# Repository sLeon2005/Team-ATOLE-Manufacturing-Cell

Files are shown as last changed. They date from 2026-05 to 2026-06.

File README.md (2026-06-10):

# 🏭 Team ATOLE Manufacturing Cell
### PLC Coordination · Computer Vision · Collaborative Robotics · IIoT Monitoring · Cybersecurity

Manufacturing Cell

An Industry 4.0 manufacturing cell developed at Tecnológico de Monterrey that integrates industrial automation, machine vision, collaborative robotics, Industrial IoT, cybersecurity, custom electronics, and digital manufacturing.

The system simulates an automated pastry production facility capable of:

- Identifying products using industrial vision
- Dynamically selecting manufacturing recipes
- Coordinating two Siemens PLCs through an S7 network
- Performing automated material handling with a collaborative robot
- Monitoring energy consumption in real time via MQTT
- Enforcing operator authentication through RFID access control
- Palletizing finished products automatically

---

# 📖 Project Overview

The project combines machining, industrial automation, robotics, cybersecurity, and Industrial IoT into a single integrated manufacturing system.

The complete solution is divided into two major subsystems:

## ⚙️ Plant 1 – Machining & Industrial IoT Monitoring

A custom Aluminum 6061 workpiece was designed, manufactured, and monitored during machining operations.

A custom non-invasive monitoring system measures:

- RMS current
- Active power
- Energy consumption
- Operating cost
- Machine operating state

The collected data is transmitted through MQTT and visualized in real time using a Node-RED dashboard.

Plant 1 Overview

---

## 🏭 Plant 2 – Automated Manufacturing Cell

The manufacturing cell is controlled by two Siemens S7-1200 PLCs interconnected through industrial Ethernet communication.

The production process includes:

1. Product classification using Cognex Vision
2. Automatic recipe selection
3. Pneumatic processing stations
4. Conveyor synchronization
5. Collaborative robotic manipulation
6. Product assembly
7. Automated palletizing

Plant 2 Overview

---

# 🏗️ System Architecture

System Architecture

The architecture integrates:

- Siemens S7-1200 PLCs
- Siemens HMIs
- Cognex Vision Sensor
- UFACTORY xArm Lite 6
- ESP32 IoT Gateway
- MQTT Broker
- Node-RED Dashboard
- RFID Authentication System
- Pneumatic Stations
- Conveyor Network

---

# 🎛️ Industrial Automation

The automation layer was implemented using two Siemens S7-1200 PLCs communicating through an S7 network.

Key features include:

- Dual PLC architecture
- Bidirectional communication
- Dynamic recipe management
- Conveyor synchronization
- Pneumatic sequencing
- HMI operation and diagnostics

PLC System

---

# 👁️ Computer Vision

A Cognex industrial vision sensor acts as the cell’s quality gate.

Three reference objects are classified and mapped to production recipes:

| Object | Recipe |
|---|---|
| Turned Aluminum Part | Chocolate |
| Milled Aluminum Part | Strawberry |
| Metal Hook | Vanilla |

The detected classification is transmitted directly to the PLC network and automatically configures downstream process parameters.

Cognex Vision System

---

# 🤖 Collaborative Robotics

A UFACTORY xArm Lite 6 collaborative robot performs:

- Raw material loading
- Inter-conveyor transfers
- Product assembly
- Palletizing

The robot was programmed in Python using the xArm SDK and operates through a Finite State Machine (FSM) architecture capable of managing multiple workpieces simultaneously.

Collaborative Robot

---

# 📡 Industrial IoT Monitoring

A custom monitoring cabinet was developed around:

- ESP32
- SCT-013 Current Transformer
- ADS1115 16-bit ADC

The system continuously estimates:

- Current
- Power
- Energy
- Operating cost
- Machine utilization

without requiring direct electrical connection to the machine power circuit.

IoT Monitoring System

---

# 📊 MQTT & Node-RED Dashboard

Process variables are published through MQTT and visualized through a Node-RED dashboard.

Available metrics include:

- Live current consumption
- Active power
- Energy usage
- Estimated operating cost
- Machine operating state
- Historical trends

Node-RED Dashboard

---

# 🔐 RFID Cybersecurity

An RFID authentication system was integrated to restrict access to critical HMI functions.

Only authorized operators are allowed to access or modify manufacturing parameters.

RFID Access Control

---

# 🔧 Custom Hardware Development

Several custom-designed hardware components were developed specifically for this project.

## 💻 IoT Monitoring PCB

Custom PCB for:

- Signal conditioning
- Current measurement
- ESP32 integration
- MQTT communication

PCB

---

# 🔧 Custom Hardware Development

Several custom electronic and mechanical systems were designed and fabricated specifically for this project.

## 🔐 RFID Access Control PCB

A custom PCB based on the ATmega328P was designed to provide RFID-based operator authentication.

Main features:

- ATmega328P microcontroller
- RFID card reader
- Relay outputs for PLC interfacing
- User identification system
- HMI access control

The board allows the PLC to identify authorized operators and restrict access to critical manufacturing functions.

<p align="center">
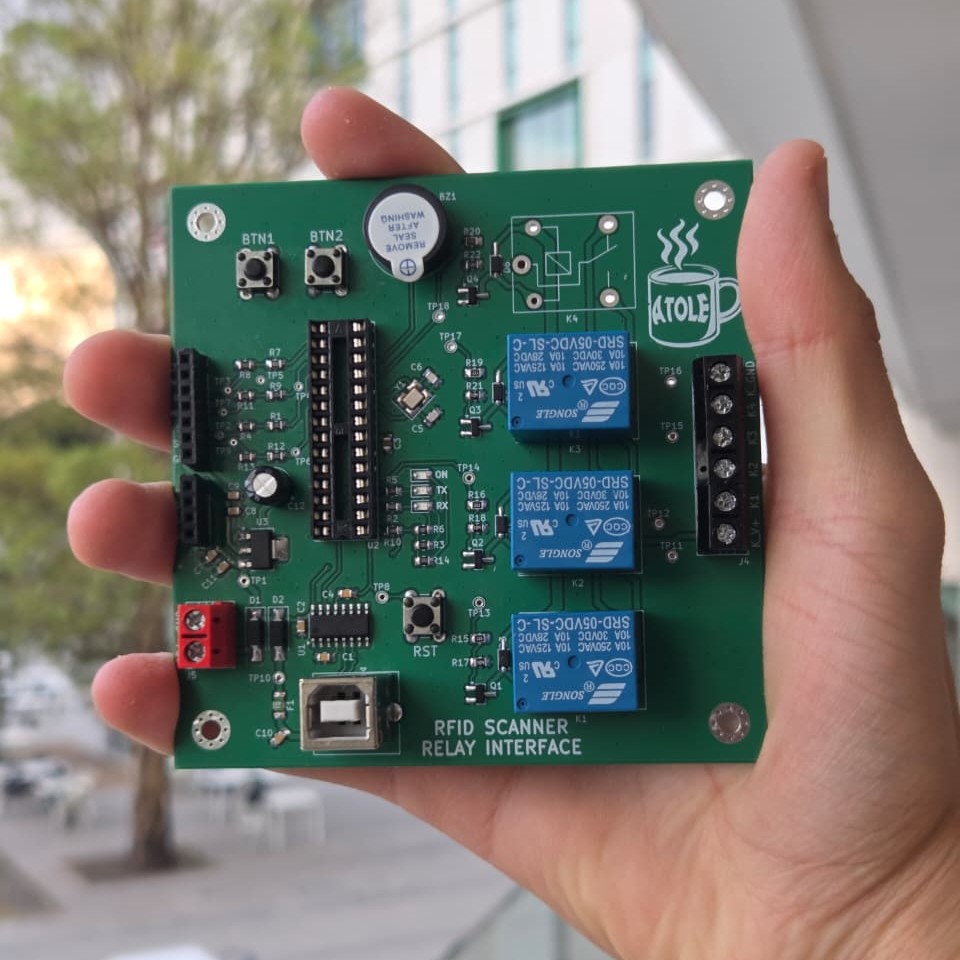
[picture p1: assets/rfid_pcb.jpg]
  
</p>

---

## 📡 IoT Energy Monitoring System

A dedicated Industrial IoT monitoring system was developed to analyze the electrical consumption of the ROMI T240 lathe.

Hardware used:

- ESP32
- SCT-013 Current Transformer
- ADS1115 16-bit ADC
- Signal conditioning circuit

The system was implemented on a prototyping board and publishes real-time data through MQTT for remote monitoring and energy analysis.

IoT Monitoring System

---

## 🦾 Custom End Effectors

Custom grippers were designed and manufactured to handle:

- Raw materials
- Semi-finished products
- Finished assemblies
- Palletizing operations

Custom Grippers

---

# 🛠️ Manufacturing

## ⚙️ Custom Machined Component

A stepped Aluminum 6061 workpiece was designed in Fusion 360 and manufactured on a ROMI T240 lathe.

The part serves both as a manufactured component and as a reference object for the vision classification system.

| CAD Model | Manufactured Part |
|---|---|
|  |  |

---

# 🧰 Software & Engineering Tools

- Siemens TIA Portal
- Siemens Plant Simulation
- Python
- xArm SDK
- MQTT
- Mosquitto
- Node-RED
- Arduino IDE
- Fusion 360
- KiCad

---

# 📈 Results

The final system successfully demonstrated:

✅ Industrial machine vision integration

✅ Dual-PLC communication architecture

✅ Collaborative robotic manipulation

✅ Automated product assembly

✅ Automated palletizing

✅ MQTT-based Industrial IoT monitoring

✅ Real-time energy analytics

✅ RFID-based cybersecurity controls

✅ Custom electronics and PCB development

✅ End-to-end Industry 4.0 integration

---

# 👥 Team

**Team ATOLE**

Tecnológico de Monterrey, Campus Querétaro

B.S. in Mechatronics Engineering

- Kintia Alexa Negrete Osuna
- Francisco Hernández Ramírez
- Sebastián León Medellín
- Yudy Camila Pérez Cervantes
- Jesús Zamora Castelazo

---

# 📄 License

This project is licensed under the MIT License.

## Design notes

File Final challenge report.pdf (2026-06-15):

## Design and Implementation of an Intelligent Pastry Manufacturing Cell Using

PLC Coordination, Computer Vision, Collaborative Robotics, IoT Monitoring,

## and Cybersecurity

Kintia Alexa Negrete Osuna (A01742928); Francisco Hernández Ramírez (A00573224); Sebastián León Medellín (A01412395); Yudy Camila Pérez Cervantes (A01707646); Jesús Zamora Castelazo (A01278023)

B.S. in Mechatronics Engineering Tecnológico de Monterrey
Querétaro, México

Abstract — This paper presents the design and physical implementation of an automated manufacturing cell integrating machining, industrial automation, computer vision, collaborative robotics, IoT monitoring, and cybersecurity. A stepped cylindrical workpiece was manufactured from Aluminum 6061 on a ROMI T240 lathe, serving as both a production component and a classification reference for the vision system. Electrical consumption during machining was monitored non-invasively using an SCT-013 current transformer, an ADS1115 16-bit ADC, and an ESP32 gateway, which continuously estimated RMS current, active three-phase power, accumulated energy consumption, operating cost, and discrete machine states (OFF, IDLE, CUTTING, FAULT). Data was transmitted via MQTT to a Node-RED dashboard, enabling remote real-time visualization and historical logging. Cell automation was integrated in two Siemens S7-1200 PLCs interconnected via an S7 network, exchanging 96 bytes of bidirectional process data. A Cognex industrial vision sensor classified three reference objects into product recipes, dynamically configuring flavor-dependent processing times through PLC multiplexor logic. Material handling, product assembly, and palletizing were performed by a UFACTORY xArm Lite 6 collaborative robot programmed in Python using a priority-based Finite State Machine capable of managing two concurrent workpieces. Performance was evaluated through machine utilization, OEE, cycle time, production rate, energy distribution per operating state, and estimated operating cost, yielding an OEE of 7% consistent with single-unit job production conditions.

Keywords — Automated Manufacturing Cell, Collaborative Robotics, Computer Vision, Programmable Logic Controller (PLC), Industrial Internet of Things (IIoT), Finite State Machine (FSM), Overall Equipment Effectiveness (OEE), Energy Monitoring

I. INTRODUCTION
A. State of the Art
The emergence of the fourth industrial revolution, broadly termed Industry 4.0, has introduced two converging forces reshaping modern manufacturing: an application-pull driven by demands for individualization, flexibility, and resource efficiency, and a technology-push characterized by increasing mechanization, digitalization, and networking of production systems (Lasi et al., 2014). At the core of this paradigm lies the Smart Factory concept, described as manufacturing environments “completely equipped with sensors, actors, and autonomous systems” (Lasi et al., 2014,
p. 240). Within these environments, cyber-physical systems merge physical processes with their digital representations
to | enable | real-time | monitoring, | control, | and
self-optimization.

Within this framework, collaborative robots have emerged as key enablers of flexible industrial automation. According to Villani et al. (2018), cobots provide a balance between robotic precision and human adaptability by integrating high accuracy, repeatability, and speed with the flexibility and cognitive capabilities of human workers. Their adoption aligns with Industry 4.0 objectives because collaborative automation seeks improvements in efficiency, productivity, and cost reduction while supporting greater flexibility and interoperability across production systems (Villani et al., 2018). Furthermore, the authors report increasing implementation of cobots in small and medium-sized enterprises due to the growing availability of affordable and user-friendly solutions, making them particularly relevant for didactic manufacturing environments.

Industrial machine vision systems constitute another foundational technology in automated manufacturing. Traditional visual inspection methods are often insufficient for modern production requirements because they rely on subjective human judgment and produce inconsistent results. As noted by Czimmermann et al. (2020), traditional inspection remains “a non-measurable process with variable and subjective outcomes” (para. 3), motivating the development of automated defect detection systems. Beyond quality control applications, industrial vision systems are increasingly employed for object identification and classification tasks that dynamically influence downstream manufacturing processes, enabling greater production flexibility and reducing manual intervention.

For real-time process monitoring, the MQTT protocol has established itself as one of the dominant communication standards in Industrial Internet of Things (IIoT) environments. Mishra and Kertesz (2020) attribute its widespread adoption to characteristics such as low overhead, simplicity, and ease of deployment, making it particularly suitable for constrained environments. The protocol was specifically designed to minimize bandwidth consumption and device resource requirements while maintaining reliable communication performance (Mishra & Kertesz, 2020). Their analysis further reports an average annual growth rate exceeding 32% in MQTT-related publications between 2004 and 2019, with applications spanning healthcare, agriculture, logistics, smart cities, and industrial manufacturing environments. Through its publish-subscribe architecture operating over TCP/IP, MQTT enables modular and scalable communication
infrastructures | that | are | particularly | suitable | for
heterogeneous IIoT systems requiring integration among multiple sensors, controllers, and monitoring platforms.
B. Challenge Description
In this work, a didactic manufacturing cell was automated and monitored to simulate an industrial pastry production facility. The cell is governed by two Siemens Simatic S7-1200 PLCs, each paired with a 7-inch Simatic HMI, and incorporates electropneumatic and electronic actuators, optoelectronic sensors, a UFACTORY xArm Lite 6 collaborative robot, and a Cognex industrial vision sensor. Complementary hardware including a pneumatic funnel, raw material supply grid, palletizing cage, and RFID access control module was designed and fabricated to achieve complete process integration. The cell operates across two sequential stages: a pneumatic processing stage and a machining simulation stage, each controlled independently while maintaining communication through an S7 network.

Concurrently, a physical aluminum workpiece was manufactured on a ROMI T240 manual lathe at the CIMA machining facility. This component, together with a milled aluminum piece and a metal hook, constitutes the set of reference objects used by the Cognex vision system to classify incoming product types at the beginning of each production cycle. Each classified object corresponds to a unique production recipe within the simulation: the lathe-machined component represents Chocolate, the milled component Strawberry, and the metal hook Vanilla.

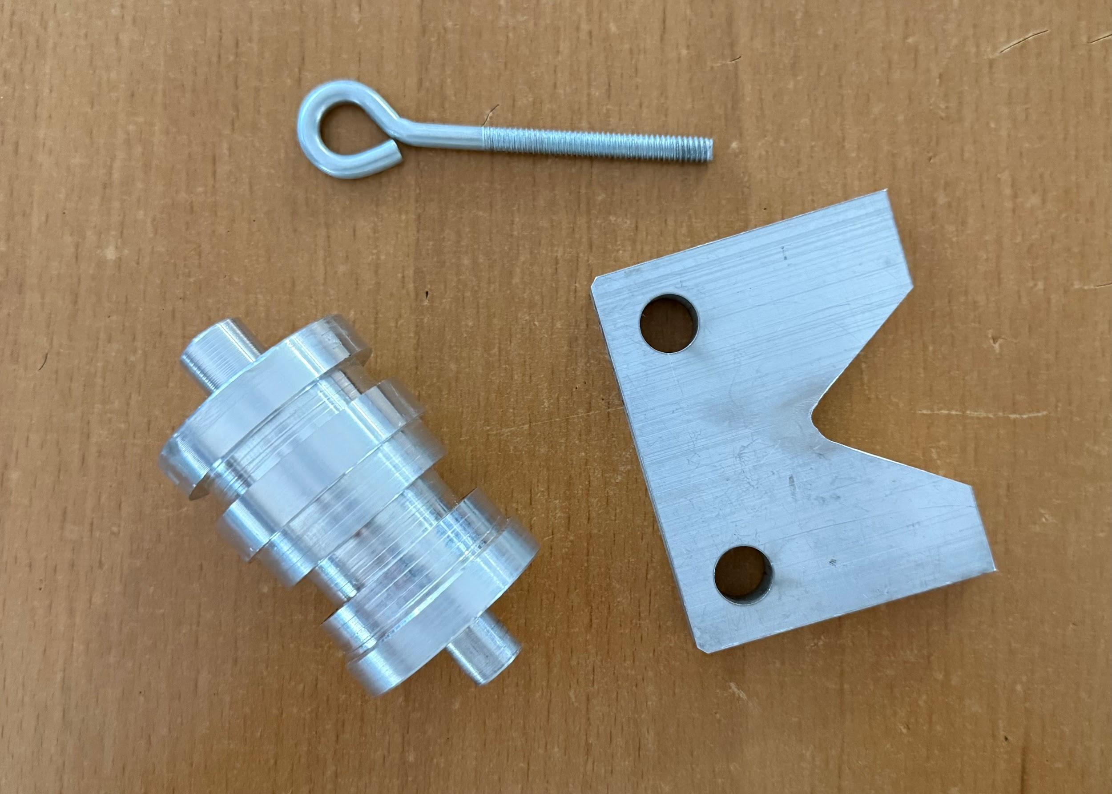
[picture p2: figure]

Figure 1. Pieces Used for the Classification System

Classification outputs are transmitted digitally to the PLCs, which dynamically adjust processing times, actuator
sequences, | and | cobot routines accordingly. The
collaborative robot performs raw material feeding, inter-conveyor transfer, product assembly, and palletizing tasks. Access to HMI interfaces is protected through RFID-based authentication connected to the PLC via relay logic, providing operator-level cybersecurity controls. Electrical consumption during machining is monitored in real time using an SCT-013 current transformer, an ADS1115 analog-to-digital converter, and an ESP32 gateway, with collected data transmitted through MQTT and visualized using a Node-RED dashboard accessible through the institutional network.
C. Team's Proposal
To address the manufacturing and automation challenge, the team proposed and physically implemented an integrated mechatronic system designed to simulate an automated cake manufacturing facility. The technical approach bridges physical machining operations with advanced industrial automation, utilizing a dual-PLC architecture, collaborative robotics, computer vision, and Industrial Internet of Things (IIoT) technologies. The specific solution is divided into three core technical pillars:
a. Plant 1: Custom Machining and Non-Invasive IoT Instrumentation
For the machining stage at CIMA, a cylindrical stepped workpiece was designed and manufactured from Aluminum 6061 using a ROMI T240 lathe. To monitor this process, a dedicated, non-invasive IoT instrumentation system was developed. This system utilizes an SCT-013 current transformer and an ESP32 microcontroller paired with an ADS1115 16-bit ADC to acquire high-resolution electrical data. An embedded algorithm processes these signals to estimate active three-phase power, accumulated energy consumption, and discrete machine states (OFF, IDLE, CUTTING, and FAULT). This data is transmitted in real-time via the lightweight MQTT protocol to a centralized Node-RED dashboard, enabling continuous remote monitoring and historical performance analysis.
b. Plant 2: Advanced Automation, Vision, and Collaborative Robotics
The automation of Cell 3105 required using two Siemens S7-1200 PLCs interconnected via an S7 communication network. A Cognex industrial vision sensor was integrated as a primary quality gate, classifying pieces into three distinct categories mapped to the simulation theme: the lathe-machined piece (Chocolate), the milled piece (Strawberry), and the metal hook (Vanilla). The PLC control logic employs dynamic array indexing to track the specific ID of each part as it moves through the line, allowing multiplexors to assign precise, flavor-dependent processing times for the drilling and mixing stations.

Furthermore, the UFACTORY xArm Lite 6 collaborative robot was programmed using Python 3 and the native xArm-Python-SDK, bypassing the limitations of rigid, linear Blockly programming. This approach implemented a pseudo-concurrent Finite State Machine (FSM) with priority-based task scheduling. This architecture allows the cobot to manage up to two products simultaneously through distinct phases: base pick-and-place, inter-conveyor transfer synchronization, topping assembly, and a structured two-level palletizing sequence that includes the automated placement of separator lids.

c. System Innovation and Cybersecurity Integration
To elevate the baseline project requirements, several innovative modules were integrated. An RFID-based access control system was implemented and wired to the PLC via relays to enforce cybersecurity protocols, ensuring only authorized users can access and modify the HMI interfaces. Additionally, custom end-effectors (grippers) were designed and fabricated for the cobot to reliably handle the specific geometries of the raw material grid, the pneumatic funnel, and the final assembled product. Finally, a unified monitoring architecture was developed, enabling real-time dashboard visualization of both Plant 1 and Plant 2 operations from any network location within the campus.

II. TECHNOLOGICAL DEVELOPMENT AND IMPLEMENTATION

A. Plant 1 - CIMA: Machining & IoT Instrumentation
a. Machining Process
The technical drawing of the proposed component is presented in Figure 2. The manufacturing challenge consisted of the development of a cylindrical stepped workpiece featuring multiple diameters and section lengths. The dimensional specifications were defined based on machining feasibility and system integration requirements. Additionally, coordination was carried out with the MCK team during the design phase to ensure geometric compatibility between the manufactured workpiece and the V-shaped support fixtures developed independently by that team. As a result, the selected diameters ensured proper alignment and handling of the component during subsequent stages. The component was manufactured using a conventional ROMI T240 lathe. The workpiece material consisted of Aluminum 6061, supplied as a cylindrical bar with an initial diameter of 2 in and a length of 7 in.

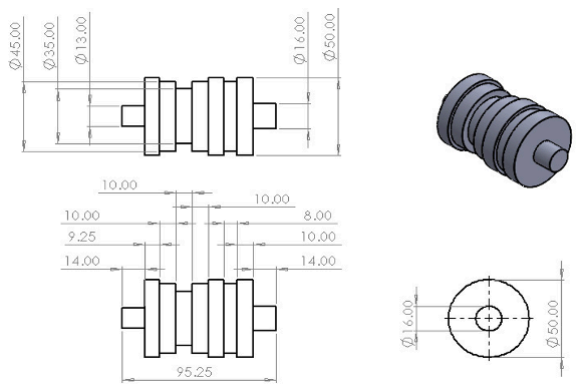
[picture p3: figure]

Figure 2. Technical Drawing of the Workpiece

Prior to machining, the raw material was sectioned using a horizontal band saw (Figure 3). An additional allowance of approximately 80 mm was intentionally left on the cut stock to prevent interference between the lathe guard and the final workpiece geometry, as well as to have enough work material in the chuck and prevent this from moving or going out due to the spindle velocity.

Figure 3. Raw Material Cutting Operation Using the JET Horizontal Band Saw

The workpiece was secured in the lathe chuck (Figure 4), and an initial facing operation was performed to establish a reference surface and obtain the required external diameter of 50 mm, as shown in Figure 5. Once the reference geometry had been established, a series of roughing passes was carried out to remove excess material and generate the stepped profile of the component.

Figure 4. Workpiece
Mounted in the ROMI
T240 Chuck

Figure 5. Initial Facing
Operation

The machining process consisted primarily of external turning operations to produce the diameters specified in the design. The final geometry incorporated a maximum diameter of Ø50 mm, intermediate diameters of Ø45 mm and Ø35 mm, and reduced end sections of Ø16 mm and Ø13 mm. Multiple geometric transitions were generated according to the dimensional requirements defined in the technical drawing. This process can be seen in Figure 6 and
7. During machining, the spindle operated at a nominal speed of 1080 RPM, providing stable cutting conditions and consistent material removal performance, as shown in Figure 8.

Figure 6. Rough Turning
Operation for Material
Removal

Figure 7. Machining of
Stepped Diameters and
Profile Features

Figure 8. Spindle Speed Configuration Used During Machining (1080 RPM)

Throughout the machining process, dimensional verification was continuously performed using a Vernier caliper. Critical diameters and lengths were periodically measured following each relevant operation to ensure compliance with the specified dimensions and to minimize dimensional deviations. The machined component achieved the specified overall length of 95.25 mm and incorporated multiple stepped features with widths ranging from 8 mm to 14 mm.

The completed component is presented in Figures 9 and 10, which show the Fusion 360 model and the physical workpiece manufactured on the ROMI T240 lathe,
respectively. | The | dimensional | validation of the
manufactured component ensures that the part is suitable for subsequent integration into the monitoring and data acquisition stage of the project. Since the geometry of the
workpiece | directly | influences | cutting | conditions,
maintaining geometric conformity with the digital model is essential for obtaining reliable process signals.

In this context, the verified agreement between the CAD model and the physical component guarantees that the machining conditions used during production correspond to the expected process parameters. This is particularly relevant for the analysis of current consumption and energy usage, as stable and repeatable cutting conditions are required to ensure that the electrical signals acquired from the ESP32-based IoT system accurately reflect the machining behavior.

Therefore, the validated manufacturing process supports the integrity of the collected electrical consumption data, enabling its use for further analysis of machining efficiency and energy performance within the production system.

Figure 9. Fusion 360
Model of the Finished
Component

Figure 10. Manufactured
Component
b. IoT Monitoring System
The electrical consumption of the ROMI T240 lathe was monitored using a non-invasive current measurement system based on an SCT-013 current sensor and an ESP32 IoT gateway.
i. Three-Phase Monitoring Enclosure
To enable safe and reliable current measurements, a dedicated monitoring enclosure was designed and assembled (Figure 11). The enclosure incorporated a three-phase industrial connector, including the three power lines and an earth conductor. All internal wiring was implemented using 12 AWG conductors to ensure adequate current-carrying capacity and compliance with electrical safety requirements. Ferrules were crimped onto all wire terminations to facilitate secure connections within the enclosure.

Figure 11. Inside of the
Three-Phase Monitoring
Enclosure

Figure 12. Installation of the Monitoring Cabinet
Between the Power Supply
and the ROMI T240 Lathe

The monitoring cabinet was installed between the electrical supply and the ROMI T240 lathe. This arrangement provided access to the individual phase conductors while maintaining normal machine operation. Since the SCT-013 is a non-invasive current sensor, it was clamped around one of the phase conductors without requiring any direct electrical connection to the power circuit. Consequently, the current flowing through the selected phase of the lathe could be measured safely and continuously during machining operations.

ii. Signal Conditioning and Data Acquisition Circuit
The SCT-013 current transformer produces a low-amplitude alternating voltage proportional to the current flowing through the monitored phase conductor (PowerUC Electronics, n.d.). Since the output signal contains both positive and negative half-cycles, direct acquisition by the analog-to-digital converter is not possible because the ADC operates only within the positive supply range.

Figure 13. Electrical Schematic of the Signal Conditioning and Data Acquisition Circuit

To address this limitation, a signal conditioning stage was designed and implemented (Figure 13). The first stage consists of a voltage divider formed by two 10 kΩ resistors connected between the 3.3 V supply and ground. This arrangement generates a reference voltage of approximately 1.65 V, corresponding to half of the supply voltage.

The reference voltage is buffered using an operational amplifier configured as a voltage follower. Capacitors were incorporated around the divider network to attenuate noise and improve voltage stability.

The SCT-013 sensor output is connected across a 150 Ω burden resistor. The burden resistor converts the secondary current produced by the current transformer into a measurable voltage signal according to Ohm’s law. The resulting AC voltage is superimposed on the 1.65 V virtual ground, effectively shifting the waveform into the operating range of the acquisition system.

A second operational amplifier, also configured as a voltage follower, isolates the sensor and conditioning stages from the ADC input. This buffering stage improves signal integrity, and ensures that the waveform delivered to the converter accurately represents the current measured by the SCT-013 sensor.

The conditioned signal is acquired by an ADS1115 16-bit analog-to-digital converter connected to the ESP32 through the I²C communication interface. Compared to the ESP32 internal ADC, the ADS1115 provides higher resolution and improved measurement accuracy, allowing more reliable current estimation (Admin, 2026).

iii. Current Measurement Algorithm
The ESP32 continuously acquires samples from the ADS1115 to estimate the electrical current consumed by the ROMI T240 lathe. The calculations were performed using the formulas presented by Storr and Storr (2026) in the RMS Voltage Tutorial.

For each measurement cycle, 500 samples are collected from the conditioned waveform. During the acquisition window, the algorithm determines the maximum and minimum voltage values measured by the ADC:
V

pp = V

max − V
min

where V is the peak-to-peak voltage of the sampled
pp
waveform.

Assuming a sinusoidal waveform, the RMS voltage is estimated from the peak-to-peak value using:
| V RMS = 0. 3536 × V pp

The RMS voltage is then converted into current using the burden resistor (150 Ω), as follows:
| I RMS = V RMS 150 Ω

Finally, the primary current flowing through the monitored conductor is obtained by applying the SCT-013 current transformation ratio:
| I = I RMS × 2000

This method allows the electrical current consumed by the lathe to be estimated from the sampled waveform without requiring direct electrical contact with the power circuit.

iv. Power and Energy Estimation
After calculating the RMS current, the ESP32 estimates the active three-phase power using the measured current, the nominal line voltage, and an assumed power factor. Since direct power-factor measurements were not available, a power factor of 0.85 was adopted. This value is representative of typical industrial machine-tool drive systems and falls within the range commonly reported for such equipment under normal loading conditions (Schneider Electric, n.d.; Power, 2026). The active three-phase power is then calculated as follows:
| P = 3 × V × I × PF
where:
- V = 220 V (line voltage)
- I is tℎe measured current
- PF = 0. 85 (assumed power factor)

Electrical energy consumption is calculated by integrating power over time:
| E = i=1 n ∑ P i × ∆t i

The accumulated energy value is expressed in kilowatt-hours (kWh) and is continuously updated during machine operation.

v. Data Transmission and Visualization
After each acquisition cycle, the ESP32 processed the sampled data and generated a set of operational and energy-related indicators representative of the electrical behavior of the ROMI T240 lathe. These variables were converted into string format and transmitted using the Message Queuing Telemetry Transport (MQTT) protocol.

MQTT was selected due to its lightweight architecture, low bandwidth requirements, and suitability for Industrial Internet of Things (IIoT) applications (Simson M, 2025). Communication was implemented using a Mosquitto MQTT broker hosted on a dedicated workstation connected to the university network (Yudy’s computer). This workstation served as the central communication hub between the ESP32 IoT gateway and the monitoring platform. Operating under a publish-subscribe architecture, the broker received data published by the ESP32 and distributed the information to all subscribed clients.

The ESP32 was connected to the university wireless network and periodically published process variables to dedicated MQTT topics. A separate topic was assigned to each monitored variable, allowing modular data management and simplified dashboard integration. The transmitted variables included:

- Current (A)
- Active power consumption (kW)
- Accumulated energy consumption (kWh)
- Estimated operating cost (MXN)
- Machine operating state (OFF, IDLE, CUTTING, or FAULT)
- Accumulated OFF time (s)
- Accumulated IDLE time (s)
- Accumulated CUTTING time (s)
- Accumulated FAULT time (s)

For visualization purposes, a Node-RED dashboard was developed and configured as an MQTT subscriber. The dashboard continuously monitored the corresponding topics and updated the graphical interface whenever new measurements became available. The interface incorporated numerical indicators, trend charts, energy consumption metrics, and machine status displays, providing operators with real-time insight into machine utilization and electrical performance.

The integration of MQTT and Node-RED enabled continuous remote monitoring of the machining process while maintaining a low-cost and scalable IIoT architecture (Figure 14). By combining current measurements, power and energy calculations, and machine-state information, the dashboard provided a comprehensive overview of equipment utilization, operational efficiency, and energy consumption throughout the manufacturing process.

Figure 14. IoT Architecture for Real-Time Monitoring of the ROMI T240 Lathe

B. Plant 2 - Cell 3105: Automation & Robotics
a. Computer Vision Criterion (Quality Gate)
The Cognex industrial vision sensor was implemented as the primary quality gate of the manufacturing cell. Its function is to identify the type of part entering the process and communicate the classification result directly to the Siemens S7-1200 PLC through discrete digital signals.

Before each production cycle, the operator places one of three reference objects inside the Cognex inspection area: the lathe manufactured aluminum part, the milled aluminum part, or a metal hook. These objects were selected to represent the three product recipes of the pastry manufacturing simulation. The lathe part corresponds to the Chocolate recipe, the milled part corresponds to the Strawberry recipe, and the metal hook corresponds to the Vanilla recipe.

The Cognex sensor was electrically integrated into the control architecture of the Manufacturing PLC (front left) using a shared 24 VDC industrial power supply. Both the PLC and Cognex were connected to the same voltage reference and common ground (0 VDC / GND) through the control panel terminal distribution. Maintaining a common electrical reference between both devices was essential to guarantee stable digital communication, reduce electrical noise susceptibility, and avoid undefined voltage states during signal transitions (WDF,2025).

Communication between the PLC and the vision system was implemented using one digital output and three digital inputs of the PLC, as well as one digital input and three digital outputs of the Cognex sensor. PLC output Q8.7, identified in the control program as Cognex_IN0 was wired to the trigger input of the Cognex sensor, whereas the digital outputs generated by the camera were connected directly to PLC inputs I9.0, I9.1, and I9.2, corresponding to Cognex_OUT0, Cognex_OUT1, and Cognex_OUT2 respectively in the ladder program of the PLC. These outputs transmit the inspection result detected by the vision algorithm.

During operation, the PLC sequencing logic activates the trigger signal through output Q8.7 whenever the HMI designed button is pressed. Immediately after, a timer pulse (TP) instruction is activated to maintain the trigger active for one second, ensuring efficient acquisition time for stable image capture and processing. Once the image is processed internally by the Cognex sensor, the corresponding digital output is activated and sent to the PLC.

The implemented architecture was configured to support three independent classifications. Therefore, the PLC monitors the status of the three Cognex outputs (whenever the signal of the trigger is activated with the HMI button) and stores the detected result inside the Communication Data Block variable: Cognex_Code and its own local tag CognexID. The classification logic is defined as follows:

I9.0 (Cognex_OUT0) → Classification 0 (Chocolate) → Cognex_Code = CognexID=0

I9.1 (Cognex_OUT1) → Classification 1 (Vanilla) → Cognex_Code = CognexID = 1 I9.2 (Cognex_OUT2) → Classification 2 (Strawberry) → Cognex_Code = CognexID = 2

The resulting code is later used by the PLC state machine to determine the corresponding actuation or sorting sequence within the manufacturing cell.

Additionally, a fault-handling condition was incorporated into the inspection logic to improve process reliability. If none of the Cognex outputs becomes active during the acquisition window, the PLC automatically assigns the value -1 to the variable Cognex_Code. This condition represents an invalid or inconclusive inspection result and may be caused by incorrect part positioning, inadequate illumination, motion blur, or failure to detect a valid object within the camera region of interest. Under this condition, the PLC does not execute any manipulation or classification movement, preventing incorrect operations caused by unreliable image data.

Originally, the system design considered the implementation of an additional “task completed” signal from the Cognex sensor to indicate the end of image processing. However, due to a third classification proposed by the team since the beginning of the planification, the available communication resource, originally assigned to the vision sensor output Cognex_OUT2 was reassigned as an additional classification output.

Once the classification is completed, the detected ID is transmitted to the Pneumatic PLC through the PUT and GET communication network. The receiving PLC stores the value in the variable CognexID, which becomes the main decision parameter for the subsequent manufacturing operations. Indicator lights are activated to provide visual feedback of the detected product type, while the classification code is simultaneously used to select the appropriate process parameters.

A multiplexor (MUX) instruction was implemented to automatically assign different punching times according to the detected product type. Therefore, the vision system not only performs product identification but also dynamically configures the manufacturing recipe, enabling flexible production without manual intervention.

b. Control Logic and Sequencing
Recalling that a dual-PLC architecture was used for this project, a crucial step regarding the communication was to establish an S7 network that allowed the exchange of information between CPUs. This communication method involves the creation of two identical (in content) data blocks (one on each one of the PLC’s) where information will be read and written in real time by using the blocks PUT (write to the other data block) and GET (read from the other data block) from the TIA portal interface.

To implement this protocol, it is important to highlight that data blocks are arranged as a list of tags, each one of them having its own associated memory direction where the information should be written or read from. Recalling this, to reach the integration level of this project, a continuous bidirectional communication was established, where a total of 96 bytes of information are exchanged between the PLCs.

The reason behind the necessity to communicate such a great amount of information, is because two strings are shared between devices, representing 74 bytes by themselves, while the rest can be attributed to sensor states, classifications, execution codes, variables, etc.

The manufacturing process begins with the Machining PLC (front left) by setting the corresponding tags to 0, 1 or 2 depending on the classification received from the Cognex vision sensor (if the classification is invalid, the code is written in a certain way that the value -1 is never used, so it waits until receiving a valid ID). As the cobot is wired to the Pneumatic PLC (front right), the S7 network and its corresponding data blocks are used to share the classification between both CPUs.
Once the Pneumatic PLC receives the classification, it sets a byte and sends the first three bits to the cobot through its wired inputs, each different combination corresponding to the piece that is next to be manufactured. The Byte is set as follows:

Classification 0 (Chocolate Flavor) → Decimal number assigned = 1 → Byte = 00000001 Classification 1 (Vanilla Flavor) → Decimal number assigned = 2 → Byte = 00000010 Classification 2 (Strawberry Flavor) → Decimal number assigned = 3 → Byte = 00000011

Through its programming and mapped positions, the cobot knows where to move over the grid to get the corresponding raw material that will be the input for the immediate process. Right after, the cobot grabs the piece and moves it to the cell input at the pneumatic funnel.

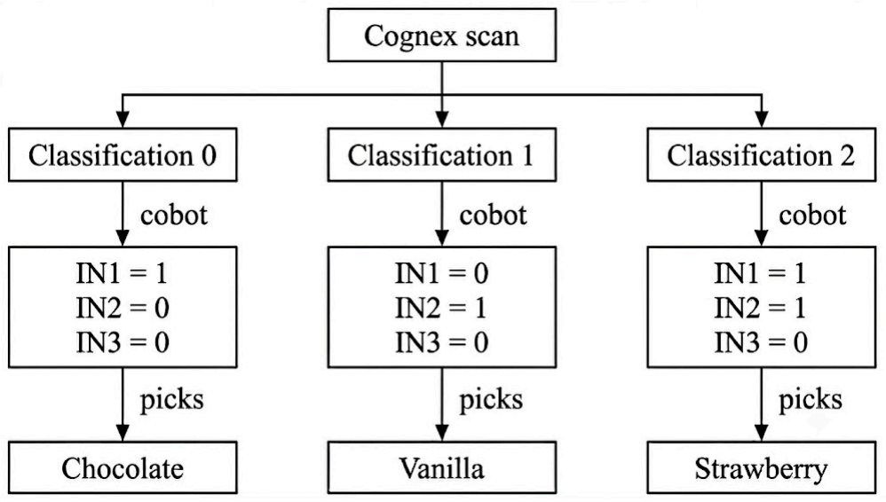
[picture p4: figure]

Figure 15. Flow Chart for Input Detection

Once a piece is located at the starting position of the pneumatic process and the optoelectronic sensor is covered, with the use of a normally closed contact, a timer ON (200ms) is used to delay the activation of a timer OFF that keeps the starting piston extended (400ms) pushing the raw material into the turntable, which is activated by the extension of the piston and latched until the button that is below is pressed, which leaves the piece under the vertical piston.

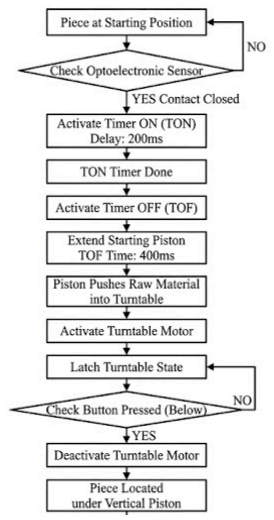
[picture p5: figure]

Figure 16. Flow Chart for Input Raw Material

Depending on the current piece that is being manufactured (chocolate, vanilla or strawberry) a multiplexor is used to set the corresponding number of presses the piston must perform; once it is done, the turntable is again activated and leaves the piece in position to be pushed to the first conveyor. When the piece pushes the conveyor button, the originally extended piston is contracted (with the use of a Pulse timer we ensure enough time is given for the piece to be pulled), placing the material on the conveyor and activating it.

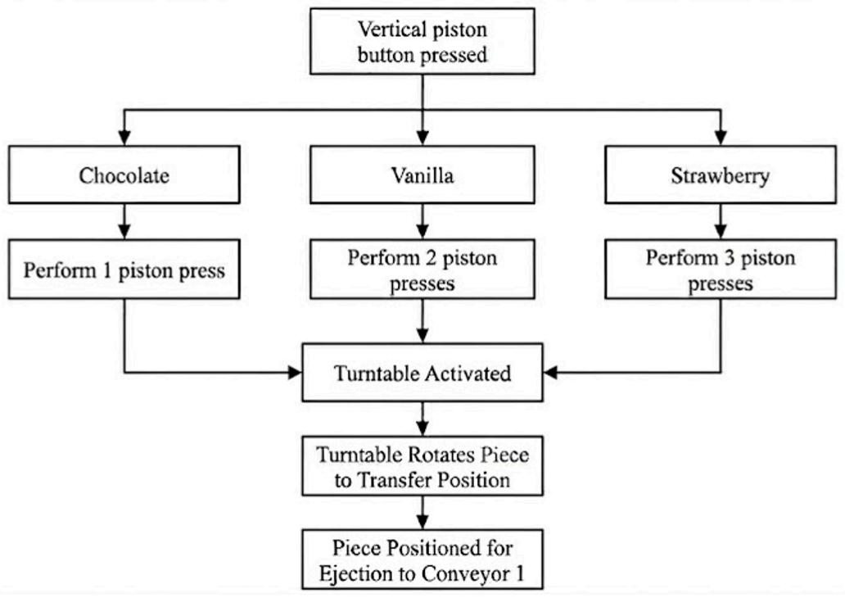
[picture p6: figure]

Figure 17. Flow Chart for Vertical Piston Operation

Since this point, all the manufacturing tasks, except for the cobot instructions are performed by the Manufacturing PLC, hence the state of the sensor placed at the end of the first conveyor and connected to the Pneumatic PLC has to be sent via the S7 network. Following this, when the sensor detects the piece, the change produced at the contact is received by the Manufacturing PLC which activates the second conveyor and latches it. At this point the piece is transferred between both conveyor belts and then passes through the first optoelectronic sensor of the second conveyor, whose state is sent back to the Pneumatic PLC to indicate the first conveyor has already completed its task and must be turned off.

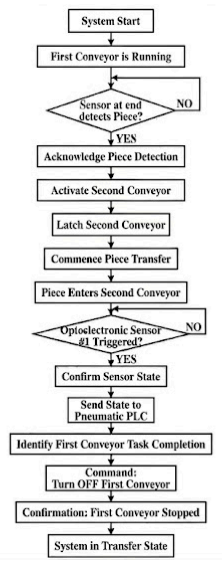
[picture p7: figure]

Figure 18. Flow Chart for Transfer Between Stations

When the piece reaches the last optoelectronic sensor of the second conveyor, two Pulse timers are chain triggered, one (3.5s) to keep the conveyor on for enough time to get the piece to the pusher position and the second one (3.3s) to delay the activation of the pusher that transfers the piece to the third conveyor. At the same time, the activation of the pusher is used to turn on the third conveyor which runs until its own optoelectronic sensor detects a piece, stopping it for the drilling operation.

Figure 19. Flow Chart for Conveyor 2 to Conveyor 3 Transferring

An important feature of the programming is that for the machining part of the cell, data blocks with arrays going from 0 to 99 were created to store the type of the pieces detected with the vision sensor in the same order they were scanned, so we can keep track of which type of piece is been and will be manufactured at every time and the processing times are not mixed up.

This was achieved by creating inside the data blocks, two indexes, one that is used to keep track of the upcoming empty position (by augmenting in one whenever a position is used) of the array and store there the corresponding ID every time the vision sensor makes a classification, and the other one used to keep track of the piece that is currently being manufactured and set the corresponding times for each operation of the cell. It is also important to highlight that a data block with these arrays and indexes was created for each operation (drilling and mixing) and for the cobot to also keep track of the piece currently on the line.

With this information, the moment that the piece stops under the drill, a Pulse timer (whose preset time is selected by a multiplexor) is activated for the time corresponding to the piece type that is on the line; once the timer reaches its preset value, another Pulse timer is triggered for 2 seconds to move the conveyor again and transfer the piece to the mixing station conveyor (conveyor 4), where, following the same logic, the process is repeated; the conveyor carrying the piece stops when the corresponding optoelectronic sensor changes its state; with the ID stored at the array and the use of a multiplexor, the operation time is set on a Pulse timer, and once the operation is done, another Pulse timer activates the conveyor to move the piece to where the second pusher is located. Additionally the timer’s output bit is used at the input of a timer ON that delays the activation of the pusher until the piece reaches the target position.

Figure 20. Flow Chart for Drilling Operation

When the pusher is activated, conveyor 5 is turned on to move the manufactured piece towards its edge, where an optoelectronic sensor stops it, sets a byte corresponding to decimal 4 and sends the first three bits to the cobot, indicating the piece has to be transported from conveyor 5 to conveyor 6 for the last part of the manufacturing process. The cobot grabs the piece from conveyor 5, releases it at the beginning of conveyor 6 and then retracts to a safe position, when this routine is completed it sends three bits through its digital outputs to the PLC corresponding to a decimal 1, with the use of a comparator, a timer ON is triggered and after 300 milliseconds conveyor 6 is activated to move the piece towards the press machine.

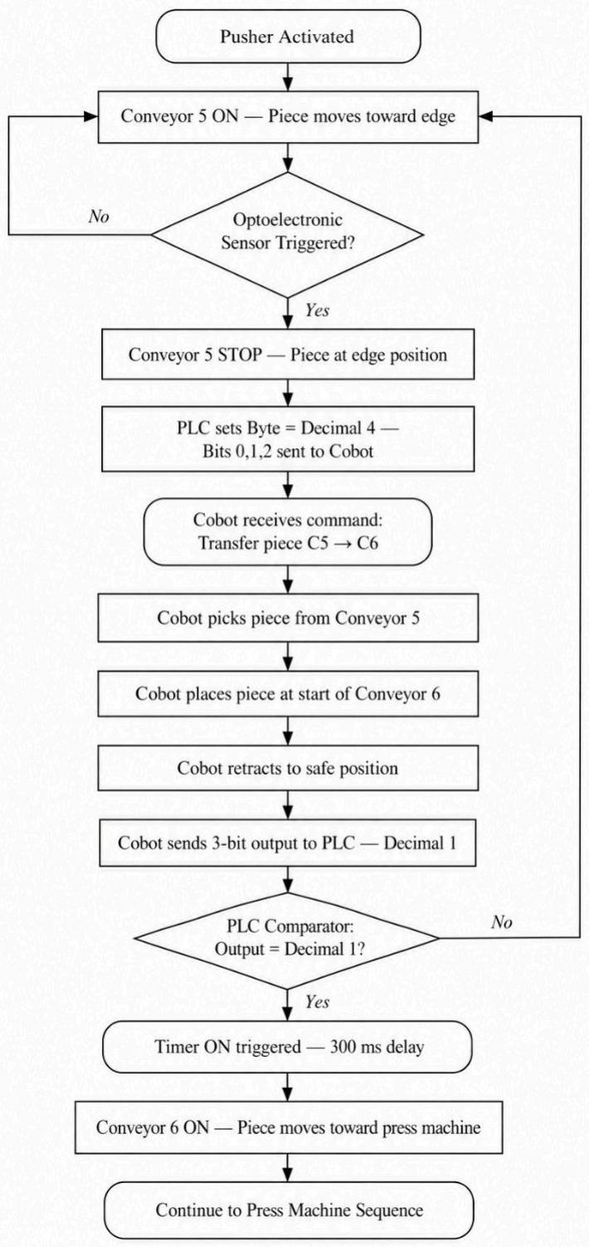
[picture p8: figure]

Figure 21. Flow Chart for Conveyor 5 to Conveyor 6 Transferring

With the use of a Pulse timer (800 ms) and a timer ON (300 ms), the piece is placed right below the press machine, and by using conveyor 6 end’s optoelectronic sensor, the press machine is actuated down. After a period of 1.5 seconds set at a timer ON, the press machine is contracted and the piece is taken again to the start of the conveyor.

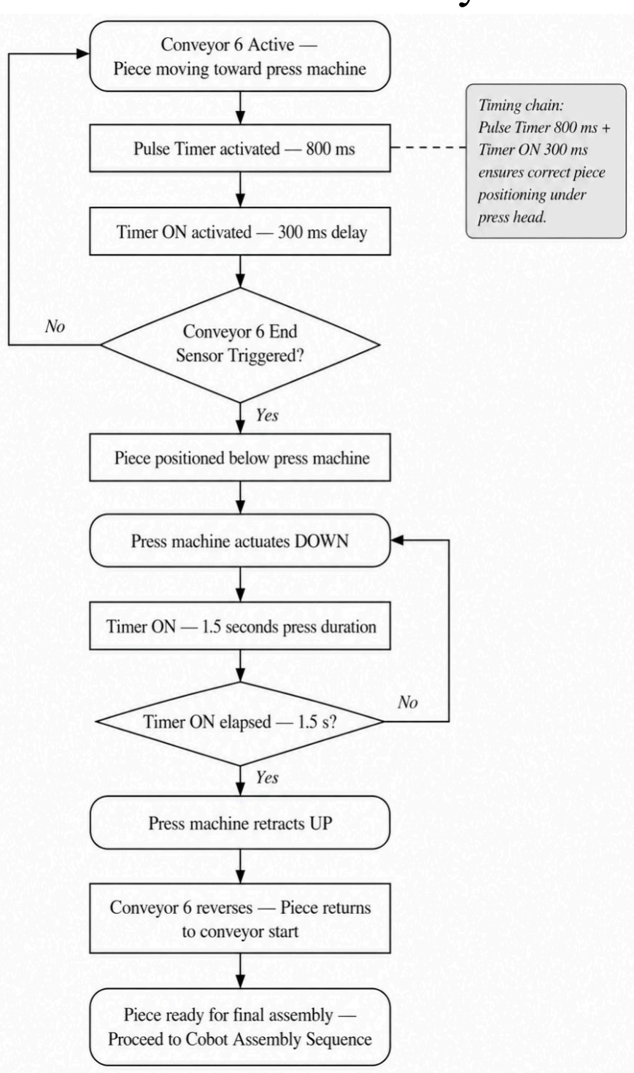
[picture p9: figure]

Figure 22. Flow Chart for Conveyor 6 and Press Machine Operation

By using the same logic as before, with a data block containing an array and a couple indexes, a multiplexor is used to set a byte corresponding to a decimal 5, 6 or 7 depending on the piece that is exiting the cell, then, the first three bits are sent through the digital inputs of the cobot so it grabs the matching complementary piece, assembles the final product and begins the palletizing sequence.

Figure 23. Flow Chart for Final Assembly and Palletizing

c. Collaborative Robot Control Logic and Integration
i. System Architecture and Hardware Configuration
The UFACTORY xArm Lite 6 collaborative robot was integrated into Cell 3105 as the primary material handling and palletizing subsystem. Physical communication with the cell’s central Programmable Logic Controller (PLC) is established through a bidirectional digital I/O interface comprising four configurable inputs (CI0–CI3) and three configurable outputs (CO1–CO3). The hardware operates under active-low logic for inputs and active-high logic for outputs.
Signal | Designation | PLC Address | Function | Active State
Input | CI0 | Q8.0 | - | Normally HIGH
Input | CI1 | Q8.1 | Flavor selection bit 0 | Active LOW
Input | CI2 | Q8.2 | Flavor selection bit 1 | Active LOW
Input | CI3 | Q9.4 | Conveyor 5 end | Active LOW
Output | CO1 | I0.1 | Response bit 0 | Active HIGH
Output | CO2 | I0.2 | Response bit 1 | Active HIGH
Output | CO3 | I0.3 | Response bit 2 | Active HIGH

Table 1. Digital I/O Configuration

ii. Control Interface Rationale
While the native UFACTORY Blockly interface is suitable for basic, linear pick-and-place routines, it is suboptimal for complex industrial logic. Blockly operates on a rigid, single-threaded execution model that forces the robot into a synchronous "wait-and-act" paradigm. This limitation renders it incapable of managing concurrent workflows, tracking real-time production data, or handling multi-device asynchronous communication.

To overcome these limitations, the control logic was
engineered | using | Python | 3 | and | the | native
xArm-Python-SDK (v1.11.0). This implementation replaces traditional linear sequencing with a pseudo-concurrent pipeline architecture. By leveraging the Python runtime environment, the system executes non-blocking I/O polling, manages up to two active work-in-progress (WIP) units simultaneously, enforces independent safety timeouts, and facilitates advanced error logging.

Furthermore, critical safety telemetry is processed via independent background threads managed through
asynchronous | hardware | callbacks
(register_error_warn_changed_callback | and
register_state_changed_callback). | This | multi-threaded
configuration isolates fault monitoring from the primary control loop, ensuring immediate actuator shutdown during collision events or emergency stops without introducing latency in the main execution cycle.

iii. Operational Sequence
The control software manages the production line via a non-blocking Finite State Machine (FSM). Rather than processing a single unit sequentially from start to finish, the FSM allows up to two units to co-exist in different stages of the production line. The robot executes a single evaluation per iteration, prioritizing tasks dynamically to maximize throughput. Each waiting state incorporates a 120-second timeout to prevent terminal blocking under fault conditions.

Phase 1 — Flavor Detection
The product flavor is identified by continuously polling the digital inputs of the cobot. A 50 ms software sampling window ensures signal stability and filters out electrical noise before the classification is committed.
Flavor | CI2 | CI1 | GPIO Pattern | Y Coordinate (mm)
Chocolate | HIGH | LOW | [1,0,1,1,1,1,1,1] | −200.0
Vanilla | LOW | HIGH | [1,1,0,1,1,1,1,1] | −250.0
Strawberry | LOW | LOW | [1,0,0,1,1,1,1,1] | −300.0

Table 2. Flavor Encoding

The X coordinate for tray access is shared across all flavors: X_1ST = [5.0, 55.0, 105.0] mm for base pieces and X_2ND = [155.0, 205.0, 255.0] mm for lids, indexed by a per-flavor counter that cycles through positions 0–2.

Phase 2 — Base Pick-and-Place
Upon flavor identification, the robot executes a pick-and-place operation transferring the cake base from the first section of the supply tray to the funnel that marks the start of the production line. The trajectory consists of seven precise waypoints.
# | Waypoint | X | Y | Z | Rx | Ry | Rz

1 | Home | 200.0 | -100. 0 | 200.0 | 180.0 | 0.0 | -45.0
2 | Approach | target _x | target _y | 50.0 | 180.0 | 0.0 | -45.0
3 | Pick | target _x | target _y | 10.0 | 180.0 | 0.0 | -45.0
4 | Retract | target _x | target _y | 50.0 | 180.0 | 0.0 | -45.0
5 | Transit | 200.0 | 110.0 | 200.0 | 180.0 | 0.0 | -45.0
6 | Place approach | -37.8 | 243.4 | 193.3 | 180.0 | 0.0 | -45.0
7 | Place | -37.8 | 243.4 | 144.7 | 180.0 | 0.0 | -45.0

Table 3. Phase 2 Trajectory

Waypoint 1 utilizes an asynchronous call (wait=False) to initiate physical hardware acceleration immediately while subsequent target positions are evaluated in the Python runtime.

Phase 3 — Cell Transfer Synchronization
Following base placement on the cell, the robot releases the “cake base” and becomes available to execute other pipeline tasks. Concurrently, the FSM monitors the unit by polling input CI3 at 50 ms intervals. CI3 transitioning to LOW signals that the part has reached the end-of-travel sensor on Conveyor 5 and is mechanically ready for inter-conveyor transfer.

Phase 4 — Inter-Conveyor Transfer
Upon CI3 activation, the cake base is transferred to Conveyor 6. The end-effector rotates from Rz = −45° (tray access orientation) to Rz = 90° (conveyor handling orientation) to align the cake base correctly for lid placement and prevent collisions. Upon placement at Conveyor 6 (252.1, −2.6, 56.4 mm), a 500 ms binary pulse is transmitted to the PLC via CO1–CO3 to signal that a base has been placed on the conveyor and to initiate the corresponding process.

Phase 5 — PLC Assembly-Ready Acknowledgment
The robot enters a non-blocking monitoring state, polling CI1–CI3 for a flavor-specific acknowledgment handshake from the PLC. This handshake confirms that upstream processes are complete and the base is ready for final assembly.
Flavor | CI3 | CI2 | CI1 | GPIO Pattern
Chocolate | LOW | HIGH | LOW | [1,0,1,0,1,1,1,1]
Vanilla | LOW | LOW | HIGH | [1,1,0,0,1,1,1,1]
Strawberry | LOW | LOW | LOW | [1,0,0,0,1,1,1,1]

Table 4. PLC Acknowledgment Encoding

Phase 6 — Topping Pick-and-Place
Once the PLC acknowledgment is validated, the topping corresponding to the active flavor is retrieved from the second section of the supply tray (X_2ND coordinates) and deposited on top of the cake base positioned at Conveyor 6 (Z = 71.4 mm). Upon successful placement, the specific per-flavor counter is incremented by one.

Phase 7 — Palletizing
The fully assembled product moves from Conveyor 6 onto a pallet, where it is stacked in a 2×2 grid across two vertical levels.m To determine exactly where each product goes, the system uses a simple repeating sequence based on the total number of pallets processed:
grid_idx = global_pallet_count (mod 4)

The height (Z-axis) automatically adjusts depending on the layer, shifting from Layer 1 (Z = 10 mm) to Layer 2 (Z = 55 mm). Once the product is placed, the system sends a 700 ms binary signal to log the specific product flavor into the PLC registry.

Flavor | CO3 | CO2 | CO1 | Binary
Chocolate | 0 | 1 | 0 | 010
Vanilla | 0 | 1 | 1 | 011
Strawberry | 1 | 0 | 0 | 100

Table 5. Palletizing Completion Codes

Phase 8 — Separator Lid Placement
To protect the products during storage, separator lids are inserted at two specific intervals. The system places an intermediate separator after every 4 units (picking at Z = 80 mm and placing at Z = 40 mm), and a final top lid after every 8 units (picking at Z = 33 mm and placing at Z = 82 mm). Once the top lid is in place, the global_pallet_count resets to zero to start the next palletizing cycle.

iv. Dynamic Task Scheduling and Pipeline Management The system uses a priority-based scheduling method that allows the robotic cell to handle up to two products at the same time without needing complex multi-threading. Instead of processing one product from start to finish before starting the next, each product is tracked as an independent task within a Finite State Machine (FSM). Every task moves through its own series of steps, including base placement, conveyor transfer, PLC synchronization, lid assembly, and palletizing.

To prevent traffic jams on the line and maximize efficiency, the scheduler checks all active tasks during every turn of the main control loop. Only one physical robot action happens per cycle, but the system constantly monitors every product using fast, non-blocking digital (GPIO) checks and timeout tracking. This allows multiple products to exist at different stages of the line while sharing the same robotic arm.
A Work-In-Process (WIP) limit of two active products is enforced through the parameter:

MAX_CONCURRENT = 2

This constraint was selected to prevent excessive queue buildup. As a result, one product may be waiting for conveyor transport or PLC acknowledgment while another product is already entering production. For example, if Task A is in State 3 (ready for lid assembly) while Task B is in State 4 (ready for palletizing), the scheduler will execute Task B's palletizing operation first (Priority 1), even if Task A has been waiting longer. This prevents assembly station blockage.

The scheduler applies a fixed-priority strategy designed to protect critical resources and avoid bottlenecks.

Priority | Operation | Objective
1 | Palletizing completed products | Free the assembly station immediately
2 | Conveyor 5 → Conveyor 6 transfer | Prevent conveyor blockage
3 | Lid assembly | Complete partially processed products
4 | Start new production cycle | Utilize remaining capacity

Table 6. Cobot Task Scheduling Priorities

This hierarchy ensures that products further down the line are finished before new work is introduced. For example, if a fully assembled product is waiting to be palletized at the same time a new product needs to be moved from the conveyor, the system will always choose to palletize first. Clearing the end of the line first keeps the production flow stable.

An additional safeguard prevents the system from accidentally creating duplicate tasks. Before accepting a new production order, the scheduler checks that another active task with the same flavor and tray position is not already running. This prevents repeated PLC signals from creating "ghost" products in the software and keeps the virtual tracking perfectly synced with the actual physical inventory.

The resulting setup provides pseudo-concurrent operation: while the physical robot can only move to do one thing at a time, multiple products can progress through the pipeline simultaneously. This significantly improves factory throughput compared to traditional systems, where a product has to exit the entire line before the next one can even begin.

v. Error Handling and Safety Mechanisms
To ensure industrial-grade reliability and protect the hardware, the system uses a four-tier safety framework:
- State-of-Health Validation (is_alive): The system continuously evaluates controller integrity by
checking | the | physical | connection | status,
confirming that error_code == 0, and verifying that the robot state remains operational (state< 4). It also includes a brief time filter to ignore temporary delays caused by motion buffering (State 5), which prevents unnecessary shutdowns.
- Inline Return-Code Verification (_check_code): Every motion and gripper command is wrapped in a validation function. If the xArm API returns any error code (a non-zero value), the system instantly sets the alive status flag to False, stops the robot's movement, and saves a detailed log report for troubleshooting.
- Asynchronous Hardware Callbacks: Critical events (such as emergency stops, safety curtain breaches, or motor over-current faults) trigger low-level background safety responses. Because these background threads run independently of the main Python program, they can immediately turn off the operational flag and lock the motor brakes the moment a safety limit is crossed.
- Monotonic Timeouts: To prevent the robot from freezing due to a broken sensor or a missing PLC signal, all waiting periods are managed by strict software deadlines using time.monotonic(). If the system gets stuck waiting for more than 120 seconds, it automatically runs an orderly shutdown sequence: it turns off all digital outputs and brings the robotic arm to a safe stop so an operator can step in.

vi. Pseudocode and State Transitions
To clarify how the priority strategy works in practice, the core logic of the main control loop can be represented by the following structured pseudocode:

INITIALIZE cobot
INITIALIZE task list

WHILE system is operational:

# Clean up the pipeline

Remove completed tasks from list

# Check background PLC status for waiting tasks FOR each task waiting for PLC acknowledgment: IF acknowledgment received:

Move task to "Ready for Lid Assembly" ELSE IF timeout expired:
Trigger safety stop
END IF
END FOR

# ---------------------------------------------------# Priority 1: Palletize completed products

# ----------------------------------------------------IF any task is ready for palletizing:

Palletize product
Place separator lid if counter threshold is met Mark task as completed
# Priority 2: Transfer product between conveyors

ELSE IF any task is waiting for Conveyor Sensor CI3: IF CI3 activated:
Transfer product from Conveyor 5 to Conveyor 6 Notify PLC of transfer
Set task state to wait for PLC acknowledgment ELSE IF timeout expired:
Trigger safety stop
END IF

# ----------------------------------------------------# Priority 3: Assemble topping

# ----------------------------------------------------ELSE IF any task is ready for lid assembly: Pick topping/lid from storage

Assemble topping onto product base Mark task as "Ready for Palletizing"
# Priority 4: Start new product

ELSE IF active products < MAX_CONCURRENT: IF new flavor detected by entry sensors:
Pick new cake base
Deposit base onto Cell
Register new task in FSM tracking list END IF
END IF

# Prevent CPU saturation during idle cycles

IF no physical action was executed during this cycle: Sleep briefly

END WHILE

Each task registered in the scheduler moves through a strict, sequential Finite State Machine (FSM). The diagram below illustrates the life cycle of a single product as it progresses through the cell:

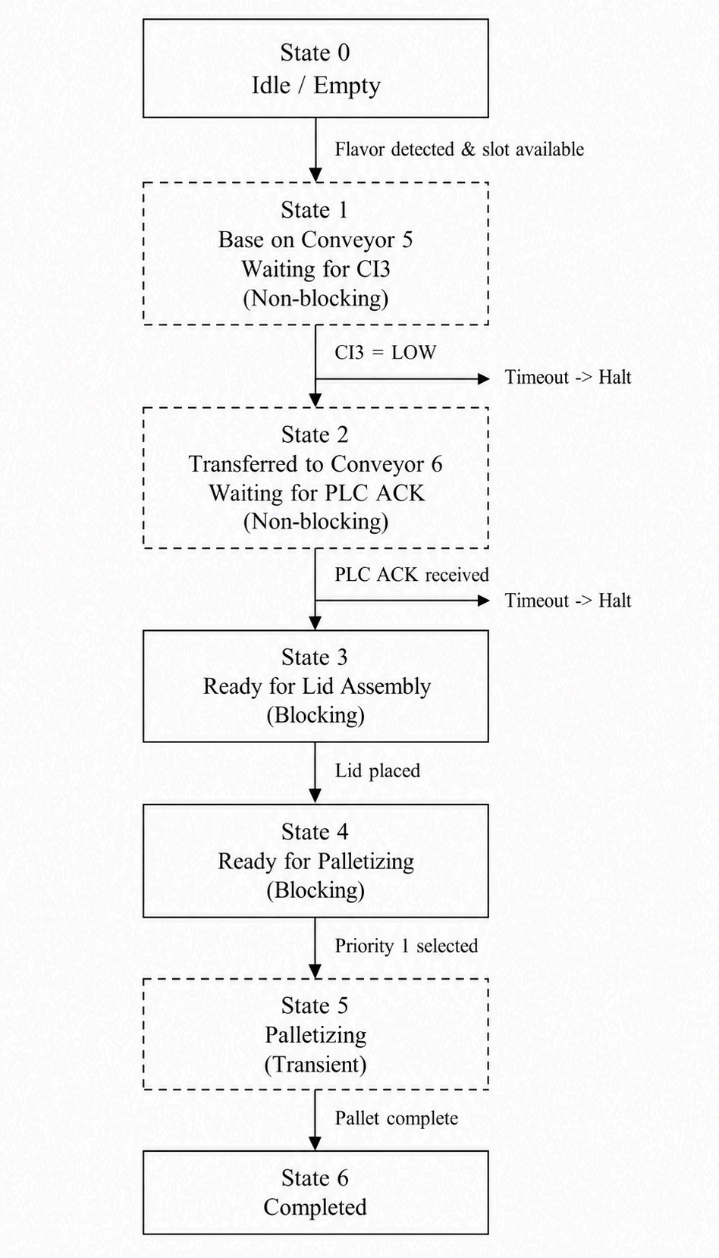
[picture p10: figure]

Figure 24. Finite State Machine (FSM) Diagram of the Single-Product Lifecycle

C. Cell HMI Interfaces
The HMI system consists of two independent panels: the Pneumatic HMI and the Machining HMI. Both share a consistent visual language and a unified navigation flow, operating as a coordinated interface for the production cell.

At startup, both screens display a locked access screen. The operator must present a valid RFID card to the reader to authenticate. Once the credentials are verified, the Pneumatic HMI displays the recognized user's name and assigned role, allowing the operator to confirm their identity before pressing Enter to gain access. Upon doing so, both HMIs transition simultaneously to their respective main screens, ensuring session state remains synchronized across both panels.

The main screen serves as the central navigation hub. On the Pneumatic HMI, it provides access to five screens: Plant View, Set Process Times, Manual Control, Camera, and Get Cycle Time. The Machining HMI main screen gives access to three screens: Plant View, Set Process Times, and Manual Control. Each navigation button includes a status lamp that indicates access permission: green signals that the current user is authorized to enter that screen, while grey indicates restricted access. A button with no permission produces no response when pressed, preventing unauthorized navigation without displaying error prompts that could distract the operator.

To return to the main screen from any sub-screen, the operator presses the Home button, which is consistently placed across all screens. Session termination is handled through the Logout button located at the bottom left of the

Pneumatic HMI's main screen; pressing it ends the active session on both panels simultaneously and returns them to the access screen, ready for the next user.

The interface design follows a minimalist approach, using grey as the dominant background color across all screens. Color is used purposefully and sparingly: red is reserved exclusively for warning alarms, and green for operational status indicators. This controlled use of color reduces visual noise and ensures that critical signals are immediately distinguishable from the rest of the interface. All screens use Tahoma as the sole typeface, reinforcing visual consistency. Text is sized to remain legible at operator viewing distance, and buttons are dimensioned to allow reliable interaction on a touchscreen panel, minimizing the risk of accidental input.

The interface design complies with the ANSI/ISA-101
Human-Machine | Interface | standard | for | industrial
applications. The use of a neutral grey background with color reserved only for alarms and status indicators aligns with the standard's guidelines on color philosophy, which discourage decorative use of color in order to preserve its communicative value. The consistent navigation structure, a central main screen with clearly labeled sub-screens and a fixed Home button, reflects the standard's emphasis on predictable, low-cognitive-load navigation. Role-based access control with visual feedback through permission lamps supports the standard's requirements for operator guidance and error prevention. The uniform font, button sizing, and layout hierarchy across both panels further satisfy ISA-101's principles of interface consistency and ergonomic design.
a. Pneumatic PLC
Access: The screen that shows on startup. It waits for the user to place an authorized RFID card on the reader, once read, current user and role are displayed and the user is free to press the enter button and gain access to the main screen of both the pneumatic and machining PLC.

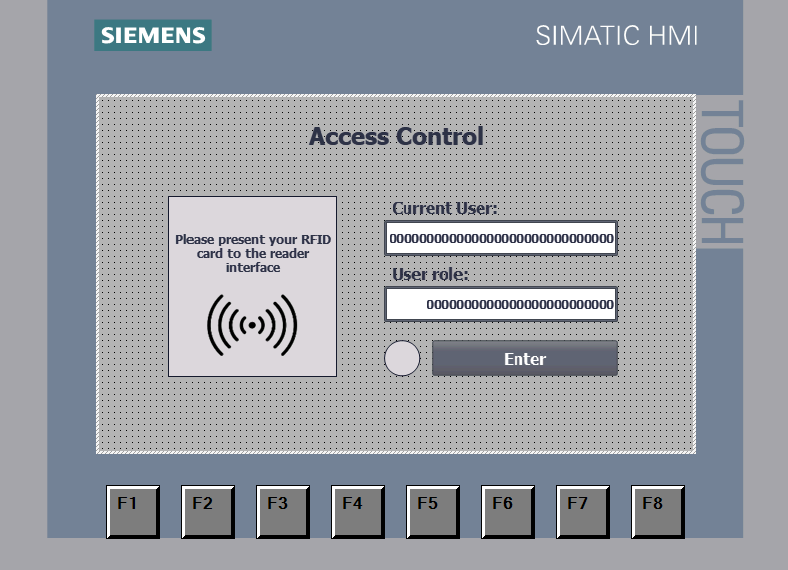
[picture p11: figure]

Figure 25. Access Control Screen of the Pneumatic Station HMI

Main Screen: Once authenticated, the operator is taken to the main screen, which serves as the central navigation hub. It displays the complete list of available screens as labelled buttons, each accompanied by a square indicator lamp. If the operator has access to a given screen, the lamp turns green; if access is restricted, it remains grey and the button produces no response when pressed, silently preventing unauthorized navigation. A cake graphic is displayed on the right side of the screen to represent the company's line of business. The Logout button is located at the bottom left, ending the active session when pressed.

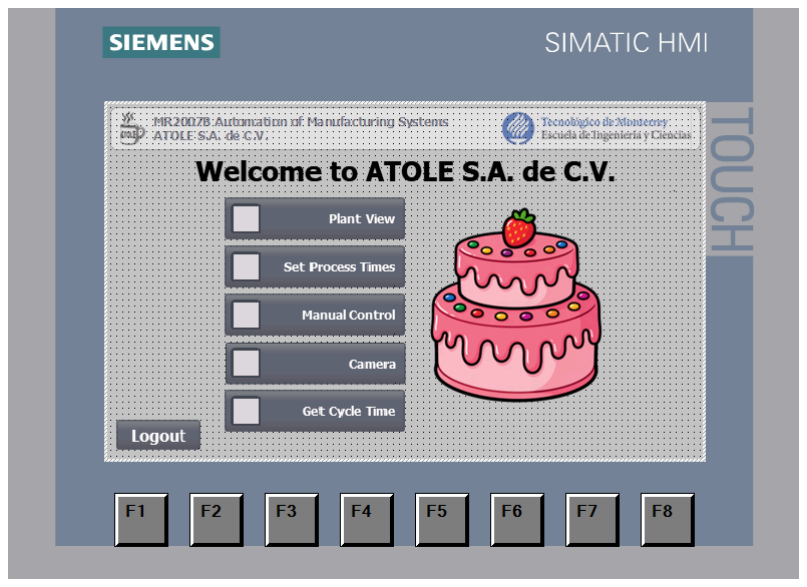
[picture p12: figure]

Figure 26. Main Navigation Screen of the Pneumatic Station HMI

Manual Control: The Manual Control screen allows individual actuation of the pneumatic components within the plant. Manual mode can be enabled using the switch located on the left side of the screen. Once enabled, the screen displays a list of buttons corresponding to each pneumatic actuator available for manual operation. Pressing a button energizes the associated actuator, while releasing it causes the actuator to return to its inactive state. An indicator lamp is displayed next to each actuator to show its current status, allowing the operator to verify whether the corresponding actuator is activated or deactivated.

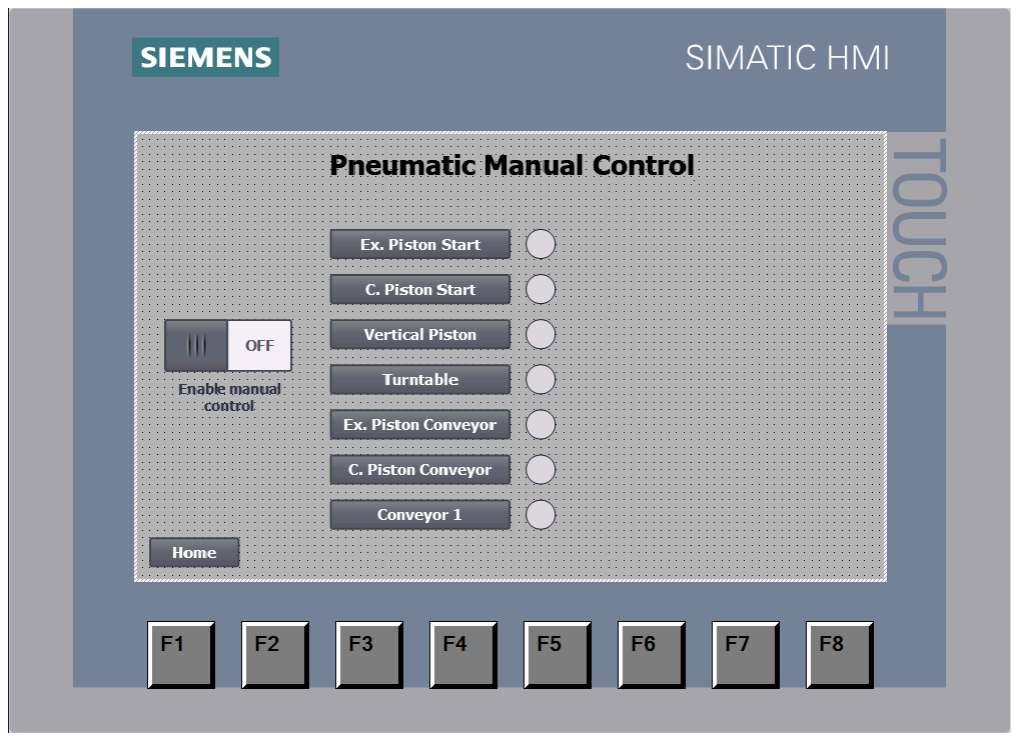
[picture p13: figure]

Figure 27. Manual Control Interface for Pneumatic Actuator Operation

Camera Control: The Camera Control screen is used to initiate the manufacturing process. When the operator presses the Scan Workpiece button, a signal is sent to the Cognex camera to capture an image of the work area. Once the camera data is received, the screen displays the ID of the scanned workpiece, the cake flavor associated with that ID, and the elapsed time, in seconds, since the image was captured. If a valid ID is detected, a signal is sent to the cobot, which proceeds to pick up the workpiece corresponding to the identified flavor. An alarm message is displayed above the scan button whenever the cobot or the pneumatic station is busy, preventing the operator from initiating a new scan while the system is occupied. While this alarm is active, the Scan Workpiece button is disabled and pressing it has no effect.

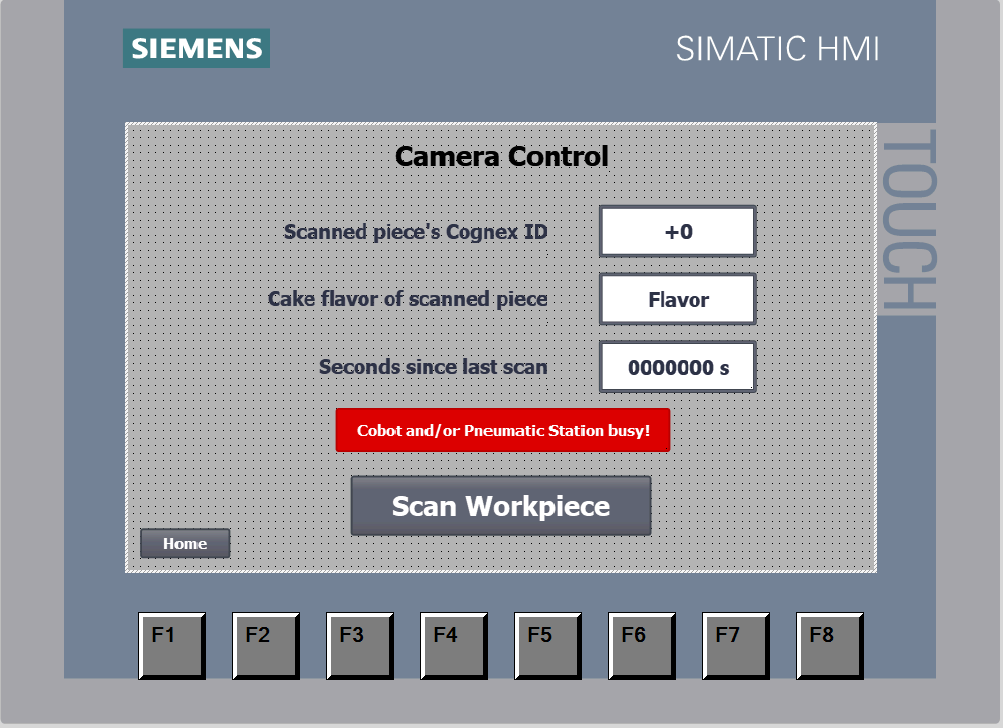
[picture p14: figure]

Figure 28. Camera Control Screen for Workpiece Identification and Production Initiation

Plant View: The Plant View screen provides a top-down representation of the pneumatic station. The color scheme was intentionally designed to resemble the physical plant as closely as possible, allowing operators to easily associate the graphical elements displayed on the HMI with their real-world counterparts. This approach enhances visual recognition of the equipment and reinforces the relationship between the physical system and its digital representation. All actuators are displayed in their corresponding locations within the station, each accompanied by indicator lamps that show their current status. For actuators controlled by double-solenoid valves, two indicator lamps are provided to represent the extension and retraction solenoids independently. The live pressure of the pneumatic system is displayed in pounds per square inch (PSI). Additionally, a power consumption indicator located in the lower-right corner of the screen displays the instantaneous power consumption of the pneumatic station and cobot in watts.

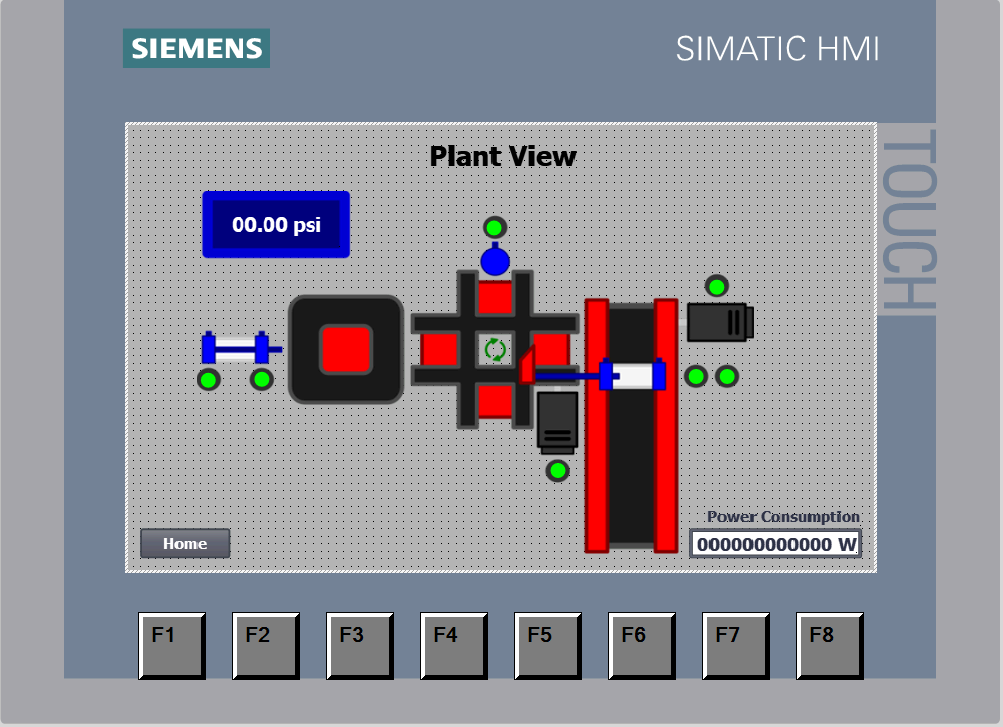
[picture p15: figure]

Figure 29. Plant View Screen Showing the Pneumatic Station Layout and Real-Time Status Indicators

Process Times: The Process Times screen allows the operator to configure the pressing duration of the vertical pneumatic piston for each cake flavor. Separate time values can be defined for chocolate, vanilla, and strawberry products, enabling the pressing operation to be adjusted according to the specific requirements of each flavor. These values are used by the control system during automatic operation to determine how long the vertical piston remains actuated while processing each workpiece.

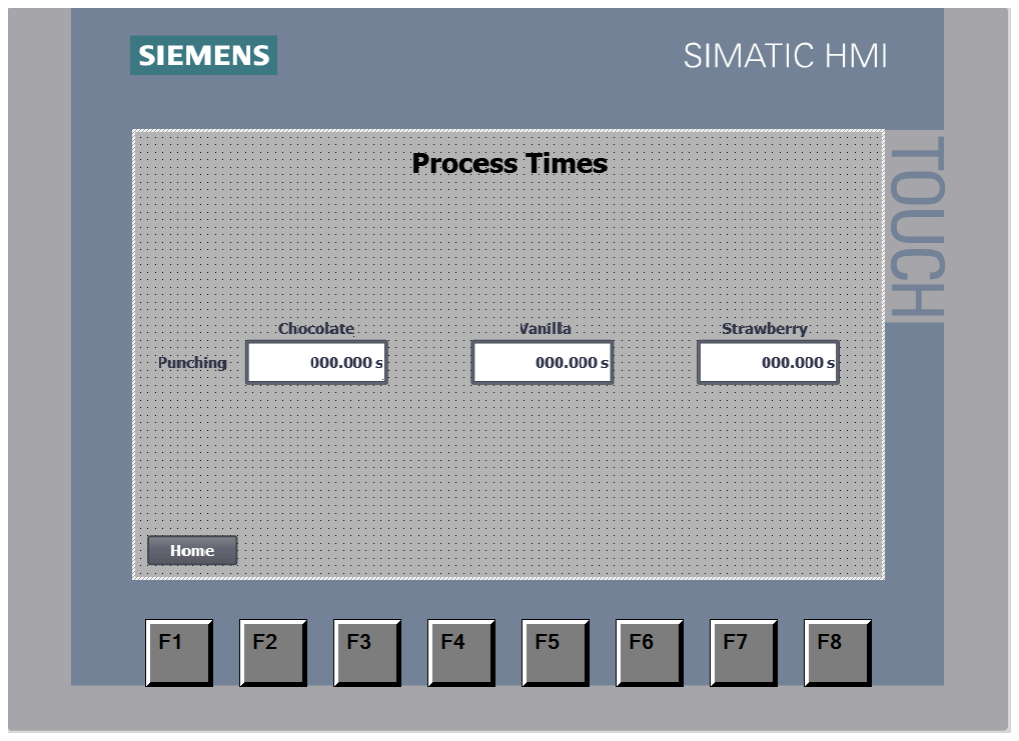
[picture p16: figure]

Figure 30. Process Time Configuration Screen for Flavor-Dependent Pressing Operations

Measure Cycle Time: The Measure Cycle Time screen allows the operator to initiate a cycle time measurement routine. Measurement mode is enabled by pressing the Enable Measuring button, causing the associated indicator lamp to turn green and signal that the system is ready to record cycle time data. Once measurement mode is active, the operator can scan a workpiece and start a manufacturing sequence. During operation, the screen displays the elapsed time of the current cycle as well as the ID of the workpiece being processed. A configurable target cycle time is provided at the bottom of the screen, allowing the operator to define a reference value for performance evaluation. Instructions describing the proper use of the measurement routine are displayed on the right side of the screen.

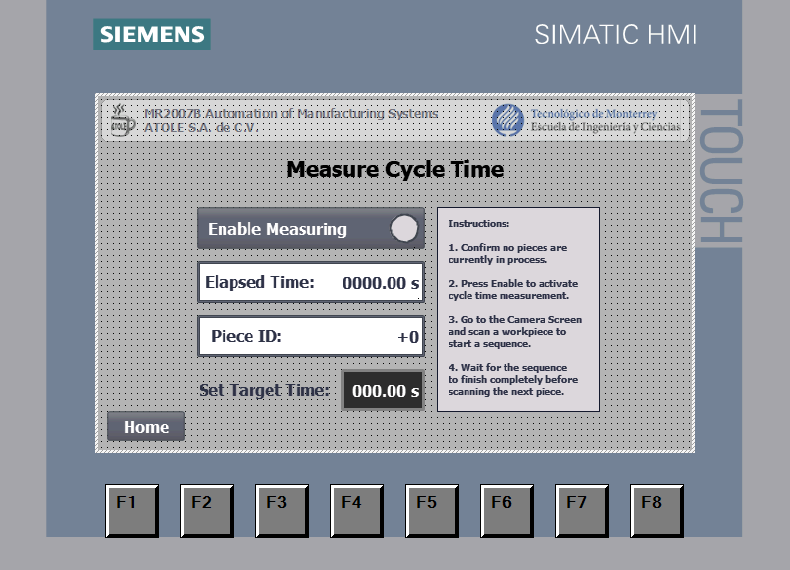
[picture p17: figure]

Figure 31. Cycle Time Measurement Interface for Production Performance Evaluation

b. Machining PLC
Access: The Access Control screen does not provide any operational controls, indicators, or configurable parameters. Its sole purpose is to prevent unauthorized users from accessing the HMI. Authentication cannot be performed from this screen; instead, user authentication is carried out through the Access Control interface of the Pneumatic HMI. Until a valid authentication is completed on that system, access to the remaining screens and functions of this HMI remains restricted.

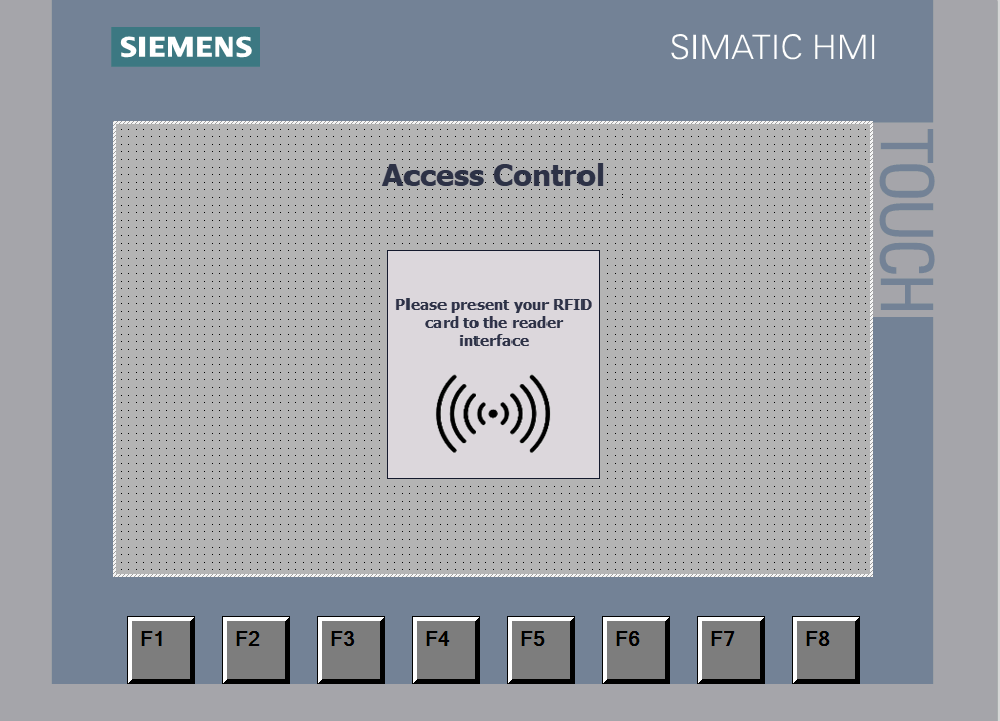
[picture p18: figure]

Figure 32. Access Control Screen of the Machining Station HMI

Main: Following successful authentication through the Pneumatic HMI, the operator is directed to the Main screen of the machining station, which serves as the central navigation hub for this HMI. The screen displays the complete list of available screens as labeled buttons, each accompanied by a square indicator lamp that reflects the access permissions assigned to the current user. If access to a given screen is granted, the corresponding indicator turns green; otherwise, it remains grey and the associated button produces no response when pressed. A cake graphic is displayed on the right side of the screen to represent the company's line of business. Unlike the corresponding screen in the Pneumatic HMI, no Logout button is provided, as user authentication and session management are handled exclusively through the Pneumatic HMI.

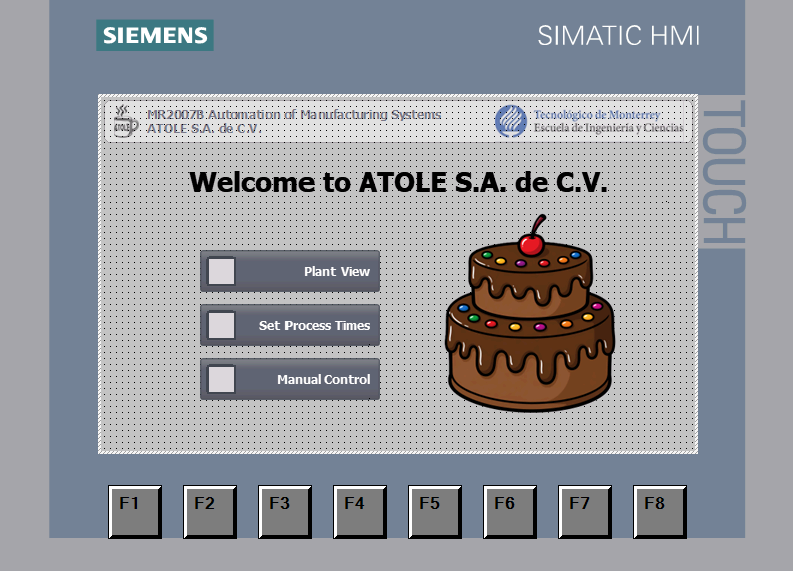
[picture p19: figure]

Figure 33. Main Navigation Screen of the Machining Station HMI

Manual Control: The Manual Control screen provides the same functionality as the corresponding screen in the Pneumatic HMI, but for the actuators located in the machining station. Manual mode can be enabled using the switch located on the left side of the screen. Once enabled, the operator may actuate any available component by pressing its corresponding button. An indicator lamp is displayed next to each actuator to show its current status, allowing the operator to verify whether the corresponding actuator is activated or deactivated.

Figure 34. Manual Control Interface for Machining Station Actuators

Plant View: The Plant View screen provides the same functionality as the corresponding screen in the Pneumatic HMI, presenting a top-down representation of the machining station and its actuators. Each actuator is displayed in its corresponding location within the station and is accompanied by an indicator that shows its current status. For actuators capable of bidirectional operation, such as Conveyor 6 and the motor driving the stamping mechanism, directional arrows are used instead of a single status indicator to represent the current direction of motion. Additionally, a power consumption indicator located in the lower-right corner of the screen displays the instantaneous power consumption of the machining station in watts.

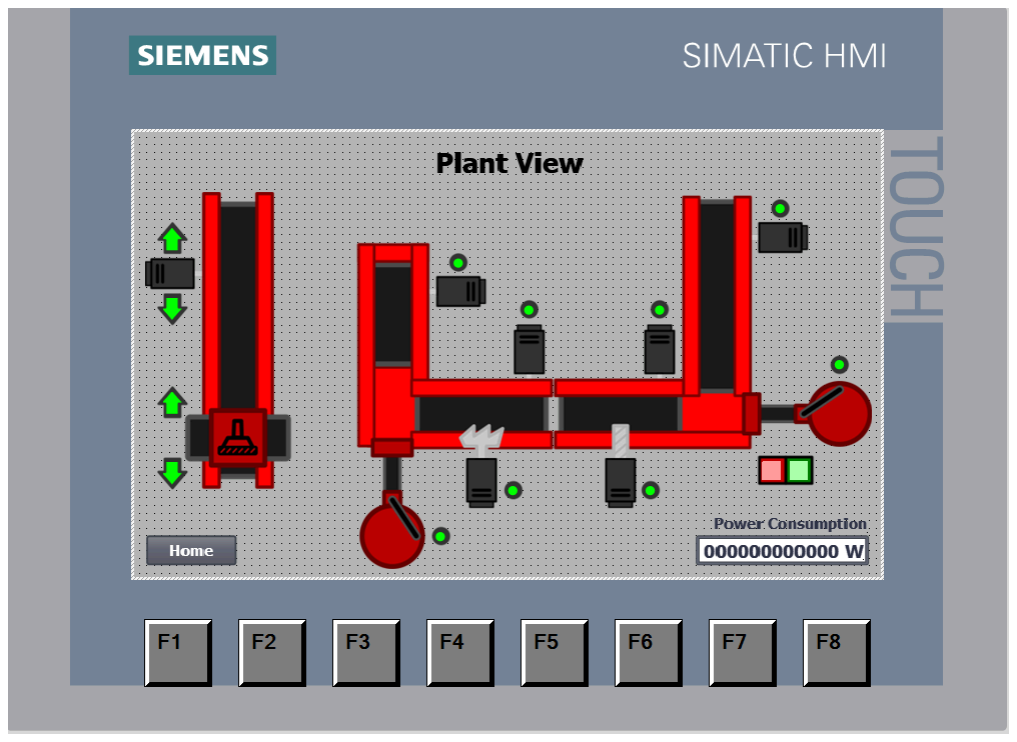
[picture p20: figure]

Figure 35. Plant View Screen Showing the Machining Station Layout and Real-Time Status Indicators

Process Times: The Process Times screen provides the same functionality as the corresponding screen in the Pneumatic HMI, allowing the operator to configure process-specific timing parameters for each cake flavor. Separate time values can be defined for the drilling and mixing operations of chocolate, vanilla, and strawberry products. These values are entered in seconds and are used by the control system during automatic operation to determine how long each workpiece remains at the corresponding machining station.

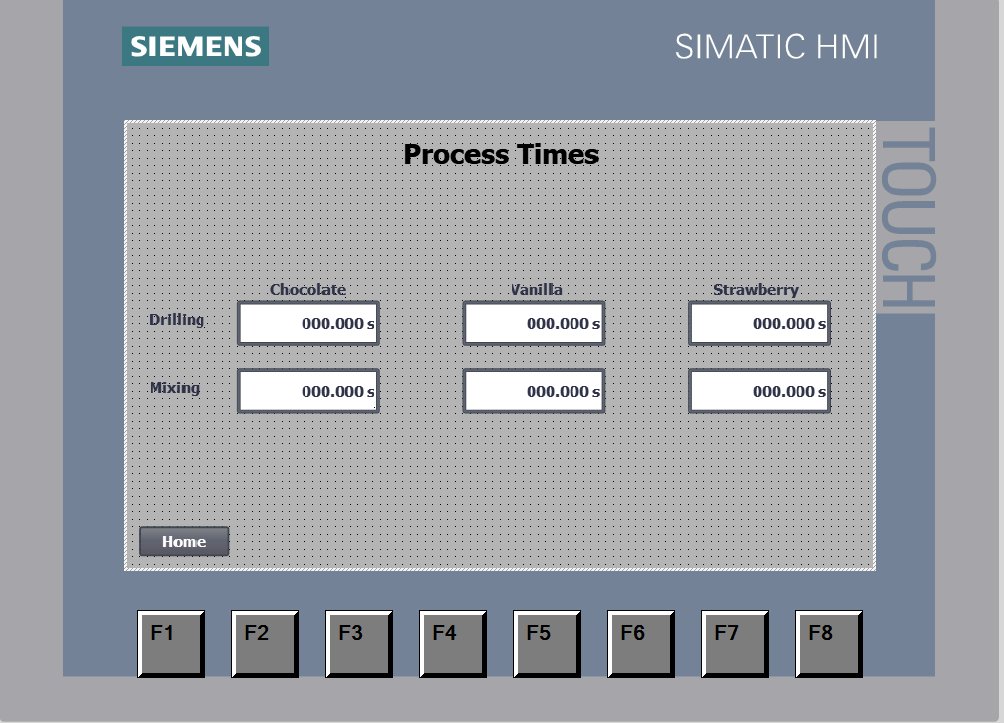
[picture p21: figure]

Figure 36. Process Time Configuration Screen for Drilling and Mixing Operations

D. Monitoring Centers (Dashboards) & Simulation
a. Plant Dashboards
To provide centralized monitoring of both manufacturing environments, three independent dashboards were developed in Node-RED. The dashboards were integrated into a single web-based platform accessible through different tabs, enabling operators and supervisors to navigate between Plant 1 (CIMA), Plant 2 (Cell 3105), and a global monitoring interface.

The dashboards were designed following an Industrial Internet of Things (IIoT) architecture in which data from the ESP32 gateway and the PLC-based automation cell were collected, processed, and transmitted through MQTT communication. The ROMI T240 monitoring system published data directly from the ESP32 to the MQTT broker, while the manufacturing cell data was acquired from the PLC through a Python-based interface that acted as an intermediary between the PLC and the MQTT infrastructure. This resulted in two independent data acquisition systems converging into a unified monitoring platform.

i. Plant 1 Dashboard – CIMA IoT Monitoring
The Plant 1 dashboard was specifically designed to monitor the electrical behavior and energy performance of the ROMI T240 lathe during machining operations. The interface served as the primary monitoring tool for the IoT instrumentation system, providing operators with both real-time measurements and historical performance data.

The dashboard was organized into three main sections. The first section displayed key performance indicators (KPIs), including current, power consumption, energy consumption, and estimated operating cost. These indicators were updated continuously from the measurements acquired by the ESP32 gateway and provided an immediate overview of the machine's electrical demand.

The second section consisted of historical trend charts showing current, power, energy, and cost as functions of time. These visualizations enabled the identification of machining cycles, transient events, startup conditions, and variations in energy consumption. By analyzing these trends, users could correlate electrical demand with specific manufacturing activities and evaluate the efficiency of the machining process.

The third section focused on machine operational status. The dashboard displayed the current machine state (OFF, IDLE, CUTTING, or FAULT) together with accumulated operating times for each state. This information allowed users to evaluate machine utilization, identify productive and non-productive periods, and estimate equipment availability throughout the manufacturing cycle.

In addition to real-time monitoring, all process variables were archived in CSV files and SQL databases, enabling subsequent analysis of machine utilization, energy efficiency, and production performance.

Figure 37. Plant 1 Dashboard for Real-Time Monitoring of the ROMI T240 Lathe

ii. Plant 2 Dashboard – Cell 3105 IoT Monitoring
The Plant 2 dashboard was developed to provide comprehensive supervision of the automated manufacturing cell. Unlike the Plant 1 dashboard, which focused on energy monitoring, this interface concentrated on operational status, production performance, and subsystem coordination.

The dashboard consolidated information from multiple cell components, including the pneumatic station, machining station, collaborative robot, and production management system. Data was acquired from the PLC and transmitted through the MQTT infrastructure using a Python-based communication bridge.

The interface was divided into functional areas that reflected the physical organization of the cell. A dedicated section monitored the machining and pneumatic stations by displaying their instantaneous power consumption and pneumatic pressure values.

Safety-related information was also incorporated into the dashboard through emergency status indicators associated with both the machining and pneumatic stations.

Production monitoring was implemented through counters that tracked the number of completed parts delivered for each product category (Chocolate, Vanilla, and Strawberry) as well as the total production output. These counters provided real-time visibility of manufacturing progress and facilitated production tracking during laboratory operation.

A dedicated area displayed the status of the collaborative robot, indicating whether the cobot was actively executing a motion sequence or waiting for the next task. User-management information was also integrated into the dashboard, displaying the currently logged-in operator and associated user role. This functionality supported traceability and improved accountability during cell operation.

Furthermore, operational indicators were included through the visualization of total energy consumption and estimated operating cost for the automated cell. These metrics complemented the production indicators and enabled evaluation of both productivity and resource utilization.

Overall, the Plant 2 dashboard provided operators with a centralized interface for supervising equipment status, production throughput, utility consumption, safety conditions, and user activity within the manufacturing cell.

Figure 38. Plant 2 Dashboard for Monitoring and Supervision of Cell 3105 Operations

ii. Integrated Overview Dashboard
To facilitate system-wide supervision, an additional dashboard was developed to aggregate the most relevant information from both manufacturing environments into a single interface. This overview dashboard acted as a monitoring center, providing a consolidated representation of the entire manufacturing system.

The dashboard displayed key operating metrics from the ROMI T240 lathe, including machine state, current consumption, power demand, energy usage, and operating cost. Simultaneously, it presented the operational status of Cell 3105, including cobot activity, machining and pneumatic station conditions, production counts, and user information.

By integrating information from both plants, the overview dashboard allowed users to evaluate the overall condition of the manufacturing system without navigating between multiple interfaces. The centralized architecture also demonstrated the interoperability of the proposed IIoT framework, successfully integrating embedded IoT devices, PLC-based automation systems, MQTT communication, databases, and web-based visualization tools into a unified monitoring environment.

Figure 39. Integrated Overview Dashboard for Unified Monitoring of the Manufacturing System

The developed dashboards can be accessed through the following URL: http://10.25.110.236:1880/ui, provided that the workstation hosting the Mosquitto MQTT broker is active and connected to the institutional network. This capability allows authorized users to monitor the manufacturing systems from different locations while maintaining real-time access to operational and energy-related data.

Throughout the project, the dashboards underwent multiple design iterations. In addition to the initial implementation, a second version was developed with the objective of improving usability, enhancing information organization, and facilitating user interaction. The updated interfaces incorporated additional process indicators, improved visual layouts, and more comprehensive operational metrics, allowing operators to access relevant information more efficiently. These modifications contributed to a more intuitive monitoring experience and provided a broader understanding of both manufacturing processes. The final versions of the dashboards are presented in the following figures.

Figure 40. Integrated Overview Dashboard V2

Figure 41. Plant 1 Dashboard V2

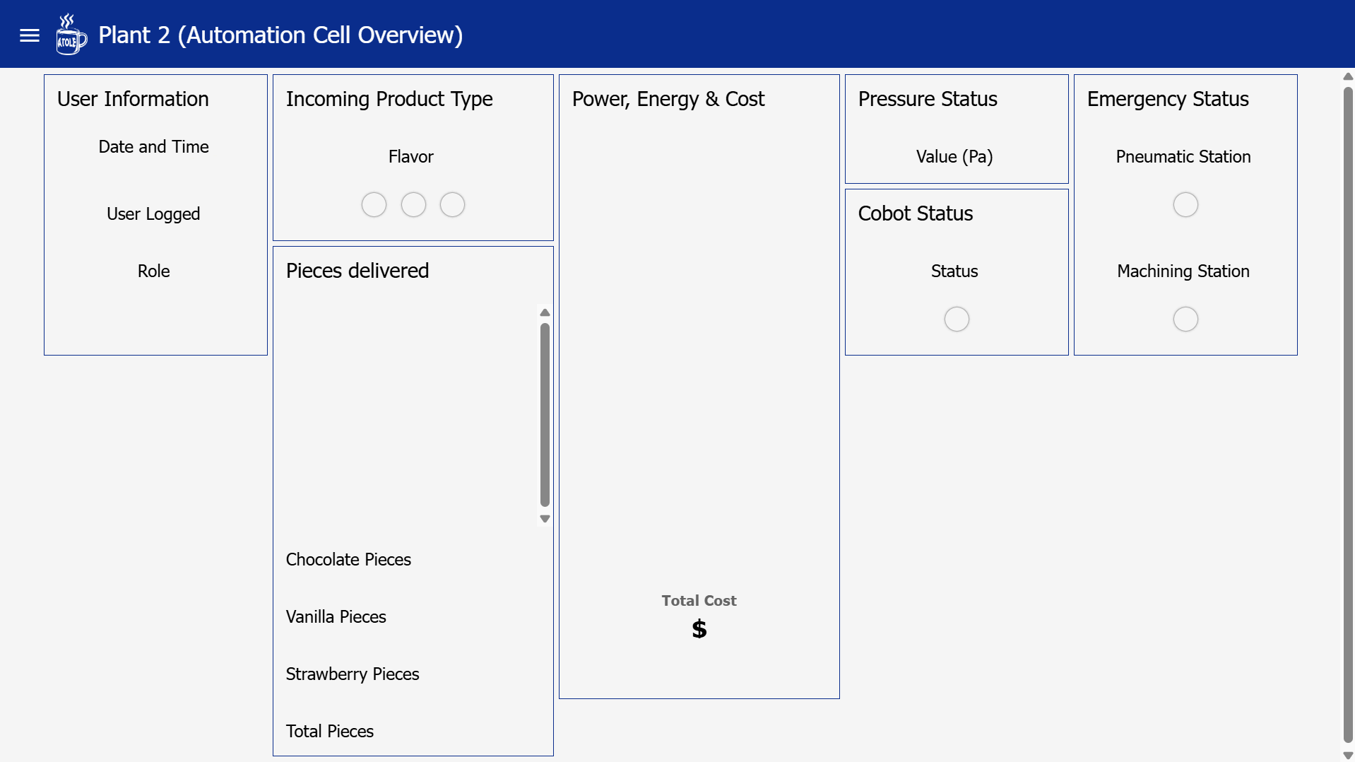
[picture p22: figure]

Figure 42. Plant 2 Dashboard V2

b. Process Simulation
i. Description of the complete production line

Figure 43. Complete 2D Layout of the Production Plant Simulation

The production line simulation was developed in Tecnomatix Plant Simulation to accurately replicate the physical manufacturing process. The simulation begins with Line 1, where cylindrical parts (blue material) are manufactured using a lathe machine operated by Worker 1. The lathe station (Lathe_L1) was configured with a processing time of 1 hour, 47 minutes, and 57 seconds per batch, with automatic processing enabled to simulate continuous operation. Material supply for this line was modeled using Source_L1, which generates batches of 10 cylinder units (MU_Cylinder).

Line 2 operates simultaneously using a fully automatic milling machine (Milling_L2) to produce V-shaped parts (orange material). In accordance with the challenge specifications, since Line 1 utilizes a lathe, Line 2 employs a milling machine with a processing time calculated as half of the lathe's cycle time, resulting in 53 minutes and 58.5 seconds per batch. The milling station was configured with an 8-minute setup time, a Mean Time To Repair (MTTR) of 10 minutes, and 85% availability to reflect realistic operational conditions. Source_L2 was programmed to supply batches of 20 V-shaped parts (MU_VShape) to this line.

The machined cylinders from Line 1 are initially stored in an initial buffer (Buffer), which was configured with a capacity of 20 units using a queue-type buffer structure. Worker 2 was then assigned to transfer these parts from Buffer to Buffer1, maintaining the same storage capacity of 20 pieces. Simultaneously, the V-shaped parts from Line 2's milling machine are transported via conveyor belt to Buffer2, which also maintains a capacity of 20 units.

Additionally, a third production stream was incorporated into the simulation to introduce hook components (MU_Hook) into the manufacturing process. This supplementary line utilizes Source_Strawberry, configured to generate single units at intervals of 1 hour and 50 minutes, with production starting at 1:50:00 and stopping at the end of the simulation day (1:00:00:00). These hook parts are stored in Buffer3, which was configured with a capacity of 10 units in a queue-type structure. This third buffer enables the integration of an additional component into the assembly process, expanding the complexity of the material handling system.

The material selection process from these buffers using the first Pick and Place robot was implemented using custom CONTROLS and METHOD programming. The selection logic was coded to prioritize buffer retrieval based on availability: the system first checks if Buffer1 contains parts (Buffer1.numMU > 0), then Buffer2, and finally Buffer3, ensuring efficient material flow without bottlenecks.

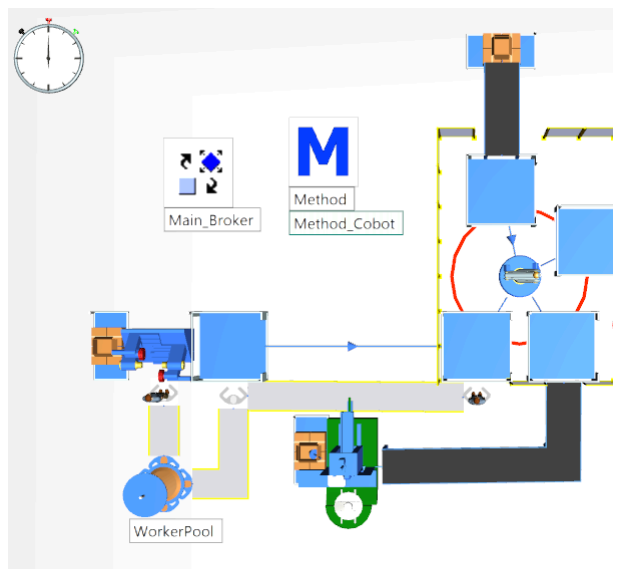
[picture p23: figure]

Figure 44. 3D Layout of the CIMA Production Line Simulation

The PickAndPlace COBOT is configured with loading and unloading times of 10 seconds each, set with a capacity of 1 unit, and configured to retain the MU (Material Unit) conveying direction. Once the COBOT retrieves a part, it is placed into Buffer_Entry, a queue-type buffer configured with a capacity of 1 unit, which acts as the direct entry point to the manufacturing cell. From Buffer_Entry, the parts are immediately fed into the cell by a Hydraulic_Pusher station. The Hydraulic_Pusher is configured with automatic processing and a rapid processing time of 2 seconds.

After being pushed by the Hydraulic_Pusher into Conveyor1, the parts enter the manufacturing cell's conveyor system, which directs them toward the first processing stage (piston station). To accurately simulate the physical layout and belt direction changes required by the challenge, the material flow incorporates turntables and angle converters. The parts are first directed through a turntable (Turntable_4Pos), configured with Entry and Exit Angle Tables to simulate the 360° rotating turntable in the physical cell. In this case, the entry angle is 180° and the exit angle is 270° into Conveyor2.

Following this directional change, the parts are transported along the conveyor to Workstation1. This workstation is set to automatic processing, with its specific processing times dynamically controlled via a List(Type) variable named "ProcTime1". This table assigns distinct processing times based on the part type: 2 seconds for MU_Cylinder, 6 seconds for MU_VShape, and 4 seconds for MU_Hook, accurately reflecting the varied treatment times defined for the manufacturing cell operations.

Upon exiting Workstation1, the parts are directed into a second turntable (Turntable_4Pos1). This second turntable is precisely configured to redirect the flow, ensuring the parts are correctly oriented and physically redirected onto the subsequent conveyor belt, Conveyor3. To fulfill the specific simulation requirement of using at least one angle converter alongside the turntables, the parts on Conveyor3 are then routed through an Angular Converter. This component facilitates the transition of the parts onto Conveyor4, adjusting their orientation for the next stage of the cell.

Conveyor4 then directs the parts into a final turntable (Turntable), which is configured with specific Entry and Exit Angle Tables to manage the final directional shift. The Entry Angle Table is set to receive parts from Conveyor4 at an angle of 90 degrees, while the Exit Angle Table directs them onto Conveyor5 at an angle of 0 degrees. Finally, the parts are transported along Conveyor5 to reach Workstation2, the second stage of the manufacturing cell.

Following transport via Conveyor5, the parts arrive at Workstation2, labeled as the Drilling station. This station is configured for automatic processing with no setup or recovery times. The processing duration is dynamically controlled via a List(Type) variable named ProcTime2. This table assigns distinct processing times based on the specific part type entering the station: 3 seconds for MU_Cylinder, 7 seconds for MU_VShape, and 5 seconds for MU_Hook.

Upon completion of the drilling operation, the parts are transferred to the final stage of the manufacturing cell, Workstation3, labeled as the Mixing station. This workstation is also set to automatic processing. Its cycle times are set by the ProcTime3 table, which similarly differentiates processing durations for each component (3 seconds for cylinders, 7 seconds for V-shapes, and 5 seconds for hooks), completing the treatment phase before the parts exit the manufacturing cell to be picked up by the second COBOT.

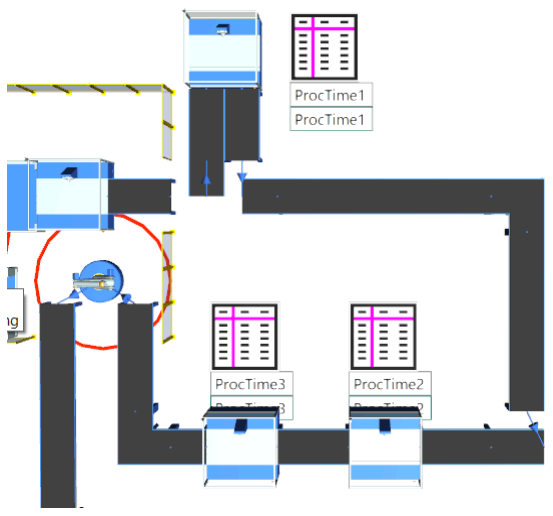
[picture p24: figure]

Figure 45. 3D Layout of the Manufacturing Cell

The parts are then placed onto the polishing belt and fed into the Polishing station. This workstation is configured for fully automatic processing with a constant cycle time of 10 seconds per part. No setup or recovery times are applied at this stage, ensuring a continuous surface-finishing flow.

Once the polishing process is complete, the parts are transported along the conveyor to a Converter designed to physically separate the different component types. This converter is configured with the "MU Name" strategy, utilizing a custom AttributeList to route each specific part to its designated exit conveyor: MU_Hook is directed to exit 1, MU_VShape to exit 3, and MU_Cylinder to exit 0.

Following this separation, each part type is routed to its dedicated inspection station (Inspect_Cylinder, Inspect_V, and Inspect_Hook). All three inspection stations are configured for fully automatic processing with a constant cycle time of 30 seconds per part, ensuring that every component undergoes a standardized quality control check before proceeding.

The validated cylinders are routed to intermediate storage buffers to synchronize the differing production rates and prevent line overflow. Specifically, they are routed to Buffer4, a queue-type buffer configured with a capacity of 15 units. From this buffer, the cylinders proceed to AssemblyStation1. This station is configured to perform the initial sub-assembly, combining 1 Cylinder (acting as the Main MU from Predecessor 1) with 2 V-shapes (Predecessor 2). The station is operated in "Delete MUs" mode, consuming the individual parts to create the sub-assembly.

Simultaneously, the inspected hooks are stored in a parallel buffer (also with a capacity of 15) to ensure availability for the final assembly stage. Additionally, a separate material stream is introduced via Source_CakeTop, which generates MU_CakeTop units at a fixed interval of 2 hours (02:00:00).

At AssemblyStation2, these three streams (the sub-assembly from Station 1, the hooks, and the cake tops) are combined. This final assembly station is configured with the sub-assembly as the Main MU (Predecessor 1). The assembly table dictates the addition of 1 Hook (from Predecessor 2) and 1 CakeTop (from Predecessor 3). The completed products are stored in a buffer configured with a capacity of 20 pieces. This buffer serves to decouple the assembly line from the packing process, ensuring a steady supply of products even if packing is momentarily delayed.

The packing operation is managed at the Packing_Station. To support this, a separate material stream is introduced via
Source_Box, | which | supplies | packaging | units
(.UserObjects.Box) at a fixed interval of 2 hours and 10 minutes. These boxes are transported via conveyor to the packing station. At the Packing_Station, the system is configured to combine the final assembly (acting as the Main MU from Predecessor 1) with the packaging box (from Predecessor 2). The station utilizes the "Attach MUs" assembly mode, which physically groups the assembly and the box into a single transport unit for the final stage.

This operation is performed by Worker_3, who is assigned to the station's services list. The sequence is set to "MUs then Services," ensuring that both the assembly and the box are present before the worker begins the task. The packing process is set to take 10 seconds per unit.

Once packed, the boxed assemblies are transferred from the Packing_Station to auxiliary processing stations before final distribution. The packed units first enter Aux1, an auxiliary station configured with automatic processing and a cycle time of 10 seconds. This station is linked to Workplace4, where workers can perform additional tasks if required, though the "Worker stays here after completing the job" option is disabled to allow worker mobility.

Figure 46. 3D Layout of the Inspection and Assembly, and Packing Areas

Following Aux1, the boxes are transferred to Aux2, another auxiliary processing station also configured with a 10-second automatic processing time. These auxiliary stations are utilized to ensure proper spacing and sequencing of packed units.

Figure 47. 3D Layout of the Shipping and Distribution Segment

From Aux2, the packed boxes are transferred to the plant's main transport network via TransferStationL. This transfer station is configured as a "Load" type station, which physically loads the parts from Aux2 onto the track system (bus network). The sensor position is set to Lane A at position 2, ensuring precise detection and routing of the packed assemblies.

Once loaded, the packed boxes travel along a 30-meter Track. This track is configured with a length of 30 meters, a width of 0.3 meters, and an unlimited capacity (-1) to accommodate the continuous flow of packed units. To simulate realistic material handling along this route, a bus system is implemented using Source_Bus, which generates a single Bus unit (.UserObjects.Bus) at the 2:26:00 mark to transport the loaded packages along the track.

At the end of the transport route, the packages are unloaded from the track using TransferStationU. This station is configured as an "Unload" type, detecting the parts at sensor position 28 on Lane A and transferring them to the final auxiliary station, Aux3. Aux3 is configured with automatic processing and a cycle time of 10 seconds, serving as the final handling point before the products exit the system. Finally, the packed assemblies are moved to a Drain (Sink) object, marking the successful completion of the entire production and shipping simulation.

Figure 48. Complete 3D Visualization of the Production Plant

ii. Results Analysis
The simulation results demonstrate the successful completion of the production cycle over a simulated period of 1 day (1:00:00:00.0000). These statistics obtained via the
Summary | Report | and | a | custom | method
(GenerateFinalReport) reveal critical insights into the system's performance and material flow efficiency:
- Production Output Analysis: The final statistics from Drain1 show that 10 packed boxes successfully completed the entire production process. The mean life time of these units was approximately 3 hours and 45 minutes, indicating the total time from raw material input to final shipment. The production breakdown shows:
- 10 cylinders were machined on Line 1 (Lathe_L1)
- 20 V-shapes were machined on Line 2 (Milling_L2)
- | 11 | hooks | were | supplied | via
Source_Strawberry
- 11 cake tops were supplied via Source_CakeTop

Figure 49. GenerateFinalReport Method

Figure 50. Production Report Table

- Assembly Efficiency: The assembly stations
processed | all | 10 | sub-assemblies | from
AssemblyStation1 (1 cylinder + 2 V-shapes) and successfully combined them with hooks and cake tops at AssemblyStation2 to create 10 final products. The slight over-supply of hooks and cake tops (11 units each) provided a buffer to prevent assembly line stoppages.
- Time Distribution Analysis: The final Summary Report reveals that:
- 75.57% of time was spent on production activities (machining, assembly, polishing, inspection, packing)
- 24.43% of time was consumed by transport and material handling operations
- 17.74% value added represents the actual
transformation | time | that | directly
contributes to product value
- 0.00% storage time indicates an efficient flow with minimal waiting in buffers

Figure 51. Final Output Metrics

These results validate that the simulation accurately represents a real manufacturing environment with proper material flow, realistic processing times, and efficient use of resources while meeting all the challenge requirements.

E. Team Innovation Module

### 1. Segmented access: To address security issues

within the manufacturing cell, it was decided to add an authentication stage to the cell based on an RFID sensor. Whenever an user wants to get access to the cell’s functions, he/she will have to present his identification card to the sensor and depending on his/her assigned role, different interfaces will be or not accessible.
For this purpose a completely external system was designed. To make it more robust, a PCB was designed for the electronic system. It mainly consists of four relays that are activated in different patterns depending on the code of each user’s credential; these relays are wired to four digital inputs of the PLC and through the programming all the functions are established.
Additionally, an LCD screen to display important information was added and a case to encapsulate all the electronic components, the PCB and the wirings was designed.

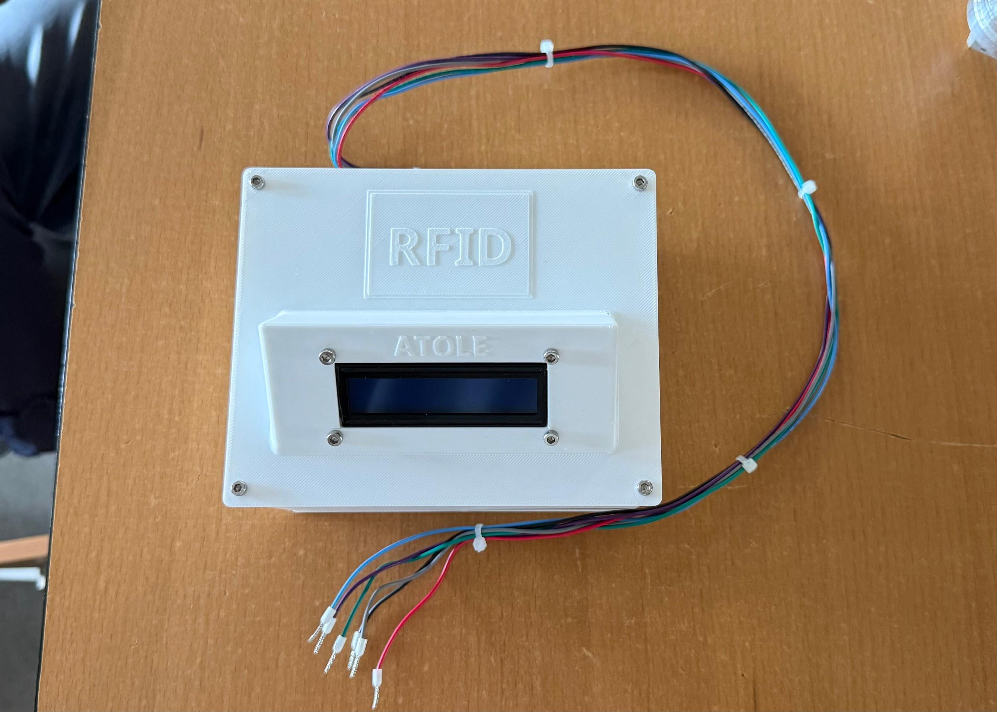
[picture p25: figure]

Figure 52. 3D RFID System

### 2. Bigger number of available classifications: As

previously mentioned, contrary to the original requirements, the vision sensor and the PLC are capable to detect three different classifications, and perform three different processes instead of only two; this was achieved by modifying certain parameters of the Cognex sensor and adding extra steps to the ladder logic in order to detect invalid classifications.

### 3. The output of the cell is different to the input:

To simulate a fully terminated item, the cell is capable of physically assembling a product that is different to the original input piece. Taking advantage of the team’s proposal to simulate a cake factory, the input to the cell is a piece that simulates the base (first floor) of a cake, which, after completing its travel through the cell, is attached to a smaller piece (that simulates the second floor) with the use of the cobot. Therefore, the output of the cell is a fully terminated cake.
It is important to note that the top of the cake corresponds to its base, so if a chocolate base is the input to the system, a full chocolate cake will be the output, and the same with the vanilla and strawberry flavors.

Figure 53. 3D Fully Assembled Cakes (Strawberry, Chocolate and Vanilla)

### 4. Integrated dashboard: The main dashboard is a

compendium of the most important parameters of both the cell and the lathe located at CIMA, achieving a full integration of both process metrics for a general view of the complete industrial system’s performance. Besides, two separated dashboards integrated into the same web address, allow the access to a wider view of each stage of the production process where more specific metrics for the cell and the lathe can be found separetely. Additionally, taking advantage of Tec’s internet, the dashboard can be accessed from any device connected to its local campus network.

Figure 54 & 55. Real Time Lathe Monitoring on Monterrey Campus

### 5. Power, Energy, and Cost Estimation: Beyond

raw current measurement, the IoT monitoring system was extended to estimate a comprehensive set of electrical performance indicators in real time. Using the measured RMS current, an assumed line voltage of 220 V, and a representative power factor of 0.85, the system calculates the estimated three-phase active power demand. Energy consumption is then obtained by integrating power over time, and an operating cost estimate is continuously updated using a reference electricity rate of 2.50 MXN/kWh based on CFE tariff data. These indicators are published via MQTT and displayed on the Node-RED dashboard, providing operators with actionable economic metrics alongside operational data.

### 6. FIFO-Based Per-Piece Process Tracking: To

handle simultaneous requests of different flavors on the line without mixing up their associated processing times, a FIFO (First In, First Out) indexing strategy was implemented in the PLC. Dedicated data blocks were created for drilling, and mixing processing stations, as well as for the cobot tracking logic. Every time the vision sensor classifies a new piece, its flavor ID is stored in the next available position of each array. A separate read index advances independently as each piece reaches its corresponding station, ensuring that the multiplexor always applies the correct processing time for the piece currently being operated on, regardless of how many pieces are on the line simultaneously. This architecture guarantees
process | integrity | even | under | continuous,
multi-flavor production conditions.

### 7. Enhanced palletizing: To simulate a ready-to-sell

product, a structured two-level palletizing sequence was designed and implemented. The palletizing cage consists of three physical components: a base tray, an intermediate separator lid, and a top cover lid. Each level accommodates a 2×2 arrangement of fully assembled cakes, for a total capacity of 8 units per palletizing cycle. The cobot places the first four finished cakes onto the lower level of the base tray. Once four units are placed, it picks and positions the intermediate separator lid on top of the first layer, and subsequently fills the upper level with the next four cakes. Finally, the top cover lid is placed to seal the pallet. Upon completion of the 8-unit cycle, all counters and positional indices are automatically reset, allowing the system to assume a new empty cage is in place and repeat the sequence continuously without operator intervention.

### 8. Custom End-Effectors and Cell Fixtures: A

custom gripper was developed for the xArm Lite 6 cobot, capable of securely grasping cake bases, second-floor topping pieces, and palletizing separator lids. A pneumatic funnel was designed to guide the cobot's placement of each cake base onto the cell's entry point, ensuring consistent and repeatable positioning at the start of the pneumatic process and reducing the risk of misalignment. Two 3×3 supply grids were fabricated to organize and store the raw cake bases and topping pieces in fixed, indexed positions. These grids allow the cobot to navigate to each slot using precalculated coordinates, supporting the per-flavor pick sequence without the need for additional sensing.

### 9. Analog Signal Integration: To extend the cell's

sensing capabilities beyond discrete digital signals, pressure monitoring is acquired through the PLC's analog input module and transmitted to the
Node-RED | dashboard | via | the | MQTT
infrastructure, where it is displayed as a real-time pressure indicator in Pascals. This addition provides operators with continuous visibility of the pneumatic system's operating condition, enabling early detection of pressure drops or abnormal values that could indicate leaks, actuator faults, or supply irregularities, contributing to more proactive maintenance and safer cell operation.

III. RESULTS AND DISCUSSION

a. System Data Analysis
i. Analysis of Data Acquired Through the Node-RED Dashboard
The results presented in the following analysis were obtained through the instrumentation of a ROMI T240 lathe using an SCT current sensor for electrical current monitoring. The acquired measurements were transmitted via the MQTT protocol to a Node-RED dashboard, where the data were stored both in a CSV file and in a SQL database for subsequent processing and analysis.

During the monitored period, the machine operated for a total of 1.80 hours (107.95 minutes). Based on the measured current values, the machine operating condition was classified into four discrete states using predefined current thresholds. The classification logic implemented in the data analysis was defined as follows:
- OFF: Current < 0.40 A
- IDLE: 0.40 A ≤ Current ≤ 7.30 A
- CUTTING: 7.30 A < Current ≤ 15.00 A
- FAULT: Current > 15.00 A

The OFF threshold was established to identify periods during which the machine spindle and drive systems were not drawing significant electrical power. Current values below 0.40 A were primarily associated with machine inactivity, part inspection, dimensional verification using measuring instruments, process planning activities, and tool entry and exit movements that did not involve material removal.

The IDLE state corresponds to machine operation without active cutting, including spindle preparation, positioning movements, setup adjustments, and short waiting periods between machining operations. The upper threshold of 7.30 A was determined experimentally from the observed current profile, representing the transition between non-productive operation and material removal.

The CUTTING state was defined for current values above 7.30 A and below 15.00 A. This range was associated with active machining operations, during which the spindle motor and feed mechanisms experienced increased electrical demand due to the cutting forces generated during turning. The threshold was selected based on the measured current distribution and visual correlation with the machining process.

Finally, current values exceeding 15.00 A were classified as FAULT conditions within the monitoring algorithm. However, these events did not necessarily correspond to actual machine faults. During the experimental evaluation, most occurrences above this threshold were associated with the transient inrush current generated during machine startup. When the ROMI T240 lathe was powered on, a short-duration current peak was observed as the electrical and drive systems were energized. Consequently, the FAULT classification should be interpreted as a high-current condition rather than a confirmed machine failure. The threshold was retained to identify abnormal current peaks and facilitate the detection of potential overloads or unexpected operating conditions during future deployments.

As shown in Table 7, the OFF state accounted for 63% of the monitored period. Although this percentage may initially appear high, a significant portion of this time was dedicated to non-machining activities required for part production, including dimensional measurements, diameter verification, machining calculations, process planning, and tool approach and withdrawal operations. Consequently, the OFF state should not be interpreted exclusively as machine downtime, but rather as a combination of inactive and auxiliary production activities necessary for manufacturing the workpiece.

State | Percentage | Time (h)
OFF | 63% | 1.133333333
IDLE | 3% | 0.062777778

CUTTING | 33% | 0.593888889
FAULT | 1% | 0.009166667

Table 7. Operating Time Distribution by Machine State

The recorded electrical current ranged from 0.01 A to 15.18 A, with an average value of 3.25 A.

The power profile obtained from the electrical measurements reflects the different operating conditions of the machine throughout the monitored period. The average power demand during the CUTTING state was higher than during the OFF and IDLE states, as expected due to the energy required to perform the machining operation. The maximum recorded power reached 4.92 kW, while the average power throughout the monitoring period was
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

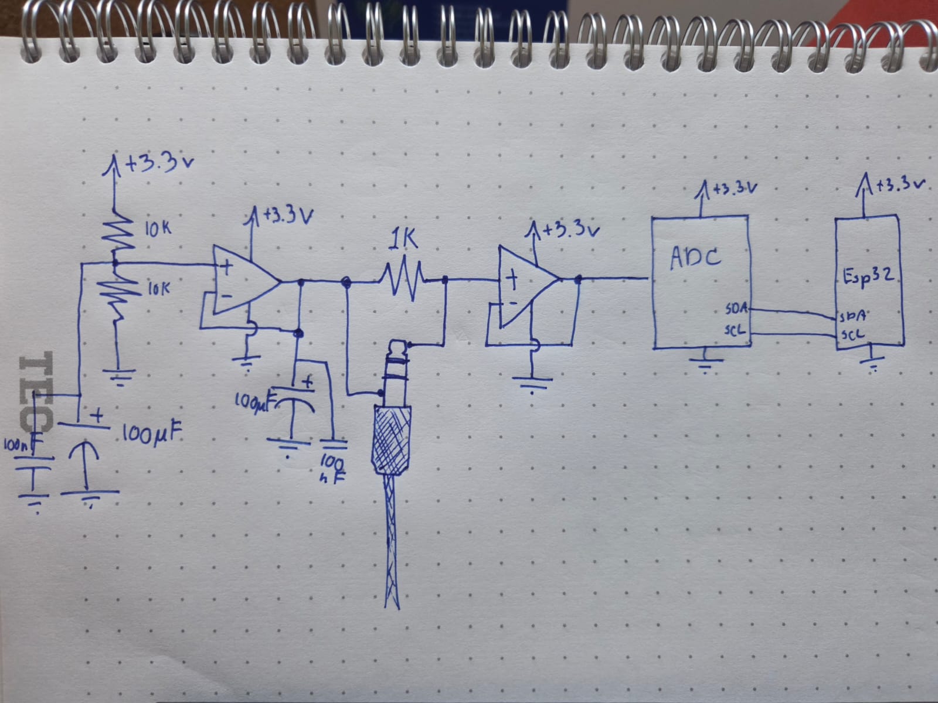
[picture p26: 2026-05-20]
IoT-Current-Sensor/instrumentationSchematic.jpeg

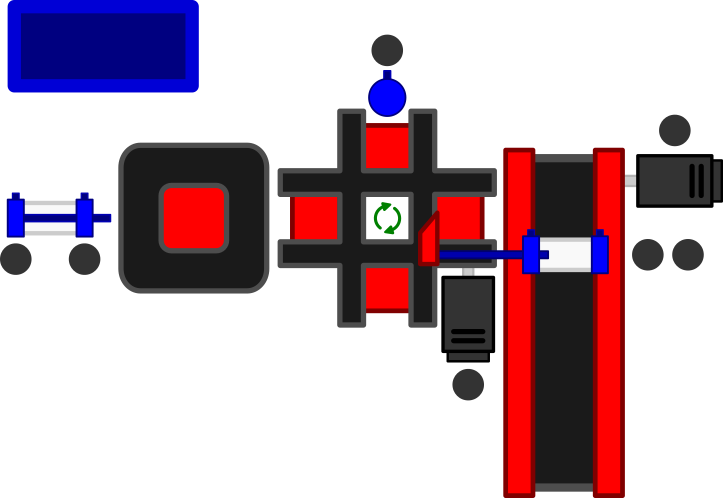
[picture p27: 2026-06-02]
assets/pneumaticCellDiagram.png

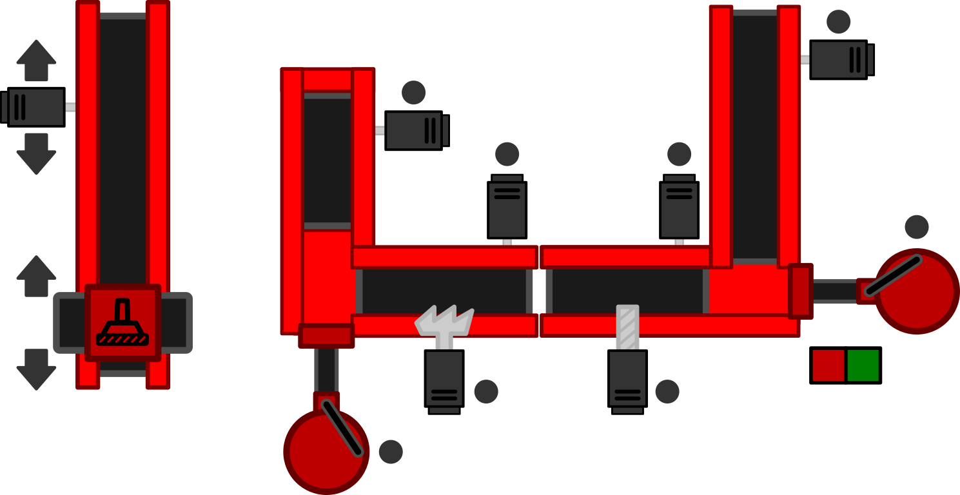
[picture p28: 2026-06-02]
assets/machiningCellDiagram.png

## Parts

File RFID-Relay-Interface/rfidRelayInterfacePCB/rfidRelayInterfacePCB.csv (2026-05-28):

Reference | Qty | Value | DNP | Exclude from BOM | Exclude from Board | Footprint | Datasheet
BZ1 | 1 | Buzzer |  |  |  | Buzzer_Beeper:Buzzer_D14mm_H7mm_P10mm | ~
C1,C2,C4,C7,C8,C9,C10,C11 | 8 | 100nF |  |  |  | Capacitor_SMD:C_0805_2012Metric_Pad1.18x1.45mm_HandSolder | ~
C3 | 1 | 10uF |  |  |  | Capacitor_SMD:C_0805_2012Metric_Pad1.18x1.45mm_HandSolder | ~
C5,C6 | 2 | 22pF |  |  |  | Capacitor_SMD:C_0805_2012Metric_Pad1.18x1.45mm_HandSolder | ~
C12 | 1 | 100uF |  |  |  | Capacitor_THT:CP_Radial_D6.3mm_P2.50mm | ~
D1,D2 | 2 | SS34 |  |  |  | Diode_SMD:D_SMA_Handsoldering | https://www.vishay.com/docs/88751/ss32.pdf
D3,D4,D5,D6 | 4 | 1N5819 |  |  |  | Diode_SMD:D_SOD-323_HandSoldering | ~
F1 | 1 | Fuse |  |  |  | Fuse:Fuse_1206_3216Metric_Pad1.42x1.75mm_HandSolder | ~
J1 | 1 | USB_B |  |  |  | Connector_USB:USB_B_TE_5787834_Vertical | ~
J2 | 1 | Conn_01x07_Pin |  |  |  | Connector_PinSocket_2.54mm:PinSocket_1x07_P2.54mm_Vertical | ~
J3 | 1 | Conn_01x04_Socket |  |  |  | Connector_PinHeader_2.54mm:PinHeader_1x04_P2.54mm_Vertical | ~
J4 | 1 | Screw_Terminal_01x06 |  |  |  | TerminalBlock:TerminalBlock_MaiXu_MX126-5.0-06P_1x06_P5.00mm | ~
J5 | 1 | Screw_Terminal_01x02 |  |  |  | TerminalBlock:TerminalBlock_MaiXu_MX126-5.0-02P_1x02_P5.00mm | ~
K1,K2,K3,K4 | 4 | SANYOU_SRD_Form_C |  |  |  | Relay_THT:Relay_SPDT_SANYOU_SRD_Series_Form_C | http://www.sanyourelay.ca/public/products/pdf/SRD.pdf
ON1,RX1,TX1 | 3 | ~ |  |  |  | LED_SMD:LED_0805_2012Metric_Pad1.15x1.40mm_HandSolder | ~
Q1,Q2,Q3,Q4 | 4 | IRLML2502 |  |  |  | Package_TO_SOT_SMD:SOT-23_Handsoldering | https://www.infineon.com/dgdl/irlml2060pbf.pdf?fileId=5546d462533600a401535664b7fb25ee
R1,R2,R3,R5,R6,R7,R9,R12,R14 | 9 | 1K |  |  |  | Resistor_SMD:R_0805_2012Metric_Pad1.20x1.40mm_HandSolder | ~
R4,R8,R11,R13 | 4 | 2K |  |  |  | Resistor_SMD:R_0805_2012Metric_Pad1.20x1.40mm_HandSolder | ~
R10 | 1 | 10K |  |  |  | Resistor_SMD:R_0805_2012Metric_Pad1.20x1.40mm_HandSolder | ~
R15,R16,R19,R20 | 4 | 220R |  |  |  | Resistor_SMD:R_0805_2012Metric_Pad1.20x1.40mm_HandSolder | ~
R17,R18,R21,R22 | 4 | 100K |  |  |  | Resistor_SMD:R_0805_2012Metric_Pad1.20x1.40mm_HandSolder | ~
SW1,SW2,SW3 | 3 | SW_Push |  |  |  | Button_Switch_THT:SW_PUSH_6mm_H5mm | ~
TP1,TP8,TP10,TP11,TP12,TP13,TP14,TP15,TP16,TP17,TP18 | 11 | TestPoint |  |  |  | TestPoint:TestPoint_THTPad_D1.5mm_Drill0.7mm | ~
U1 | 1 | CH340C |  |  |  | Package_SO:SOIC-16_3.9x9.9mm_P1.27mm | https://datasheet.lcsc.com/szlcsc/Jiangsu-Qin-Heng-CH340C_C84681.pdf
U2 | 1 | ATmega328-P |  |  |  | Package_DIP:DIP-28_W7.62mm_Socket_LongPads | http://ww1.microchip.com/downloads/en/DeviceDoc/ATmega328_P%20AVR%20MCU%20with%20picoPower%20Technology%20Data%20Sheet%2040001984A.pdf
U3 | 1 | AMS1117-3.3 |  |  |  | Package_TO_SOT_SMD:SOT-223-3_TabPin2 | http://www.advanced-monolithic.com/pdf/ds1117.pdf
Y1 | 1 | 16MHz |  |  |  | Crystal:Crystal_SMD_3225-4Pin_3.2x2.5mm_HandSoldering | ~

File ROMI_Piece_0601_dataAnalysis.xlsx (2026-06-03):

timestamp | current (A) | power (kW) | energy (kWh) | cost ($ MXN) | (current) state | value state | delta time | previous state | transition | id | duration per event | insights
8:03:01 | 0.01 | 0.00323884 | 0 | 0 | 0 | OFF | 0 |  |  | 1 | 0.2925000001
8:03:01 | 0.01 | 0.00323884 | 0 | 0 | 0 | OFF | 0 | OFF | OFF -> OFF | 1 | 0.2925000001 | max current (A) | 15.18 |  |  | summary |  |  |  | load factor | avg power / max power
8:03:03 | 0.01 | 0.00323884 | 1.799355976e-06 | 4.49838994e-06 | 0 | OFF | 0.0005555556854 | OFF | OFF -> OFF | 1 | 0.2925000001 | min current (A) | 0.01 |  |  | state | average power (kW) | total energy (kWh) | time (h) | 21.40202531% | advantage of the installed capacity
8:03:04 | 0.01 | 0.00323884 | 8.996774225e-07 | 2.249193556e-06 | 0 | OFF | 0.0002777776681 | OFF | OFF -> OFF | 1 | 0.2925000001 | average current (A) | 3.248827441 |  |  | OFF | 0.09576430763 | 0.09576430763 | 1.133333333
8:03:05 | 0.01 | 0.00323884 | 8.996779881e-07 | 2.24919497e-06 | 0 | OFF | 0.0002777778427 | OFF | OFF -> OFF | 1 | 0.2925000001 |  |  |  |  | IDLE | 2.039403982 | 2.039403982 | 0.06277777761
8:03:06 | 0.01 | 0.00323884 | 8.996779881e-07 | 2.24919497e-06 | 0 | OFF | 0.0002777778427 | OFF | OFF -> OFF | 1 | 0.2925000001 | max power (W) | 4.91655912 |  |  | CUTTING | 2.415611431 | 2.415611431 | 0.5938888892
8:03:07 | 0.01 | 0.00323884 | 8.996774225e-07 | 2.249193556e-06 | 0 | OFF | 0.0002777776681 | OFF | OFF -> OFF | 1 | 0.2925000001 | min power (W) | 0.00323884 |  |  | FAULT | 4.903113027 | 4.903113027 | 0.009166666714
8:03:08 | 0.01 | 0.00323884 | 8.996779881e-07 | 2.24919497e-06 | 0 | OFF | 0.0002777778427 | OFF | OFF -> OFF | 1 | 0.2925000001 | average power OFF (W) | 0.09576430763
8:03:09 | 0.01 | 0.00323884 | 8.996774225e-07 | 2.249193556e-06 | 0 | OFF | 0.0002777776681 | OFF | OFF -> OFF | 1 | 0.2925000001 | average power IDLE (W) | 2.039403982 |  |  | utilization
8:03:10 | 0.01 | 0.00323884 | 8.996779881e-07 | 2.24919497e-06 | 0 | OFF | 0.0002777778427 | OFF | OFF -> OFF | 1 | 0.2925000001 | average power CUTTING (W) | 2.415611431 |  |  | state | percentage
8:03:11 | 0.01 | 0.00323884 | 8.996779881e-07 | 2.24919497e-06 | 0 | OFF | 0.0002777778427 | OFF | OFF -> OFF | 1 | 0.2925000001 | average power FAULT (W) | 4.903113027 |  |  | OFF | 62.99212597%
8:03:12 | 0.01 | 0.00323884 | 8.996774225e-07 | 2.249193556e-06 | 0 | OFF | 0.0002777776681 | OFF | OFF -> OFF | 1 | 0.2925000001 | average power (W) | 1.052243227 |  |  | IDLE | 3.489269714%
8:03:13 | 0.01 | 0.00323884 | 8.996779881e-07 | 2.24919497e-06 | 0 | OFF | 0.0002777778427 | OFF | OFF -> OFF | 1 | 0.2925000001 |  |  |  |  | CUTTING | 33.00910917% | only the 33% of the time was producing
8:03:14 | 0.01 | 0.00323884 | 8.996779881e-07 | 2.24919497e-06 | 0 | OFF | 0.0002777778427 | OFF | OFF -> OFF | 1 | 0.2925000001 | total energy OFF (kWh, %) | 0.09060744865 | 5.338267113% |  | FAULT | 0.5094951392%
8:03:15 | 0.01 | 0.00323884 | 8.996774225e-07 | 2.249193556e-06 | 0 | OFF | 0.0002777776681 | OFF | OFF -> OFF | 1 | 0.2925000001 | total energy IDLE (kWh, %) | 0.1280808271 | 7.546064672%
8:03:16 | 0.01 | 0.00323884 | 8.996779881e-07 | 2.24919497e-06 | 0 | OFF | 0.0002777778427 | OFF | OFF -> OFF | 1 | 0.2925000001 | total energy CUTTING (kWh, %) | 1.433686021 | 84.46765746% |  | wasted energy |  | no productive energy
8:03:17 | 0.01 | 0.00323884 | 8.996774225e-07 | 2.249193556e-06 | 0 | OFF | 0.0002777776681 | OFF | OFF -> OFF | 1 | 0.2925000001 | total energy FAULT (kWh, %) | 0.04494520297 | 2.648010759% |  | state | energy (kWh)
8:03:18 | 0.01 | 0.00323884 | 8.996779881e-07 | 2.24919497e-06 | 0 | OFF | 0.0002777778427 | OFF | OFF -> OFF | 1 | 0.2925000001 | total energy (kWh) | 1.6973195 |  |  | OFF | 0.09060744865
8:03:19 | 0.01 | 0.00323884 | 8.996779881e-07 | 2.24919497e-06 | 0 | OFF | 0.0002777778427 | OFF | OFF -> OFF | 1 | 0.2925000001 |  |  |  |  | IDLE | 0.1280808271
8:03:20 | 0.01 | 0.00323884 | 8.996774225e-07 | 2.249193556e-06 | 0 | OFF | 0.0002777776681 | OFF | OFF -> OFF | 1 | 0.2925000001 | time OFF (hr, min, %) | 1.133333333 | 67.99999999 | 62.99212597% | FAULT | 0.04494520297
8:03:21 | 0.01 | 0.00323884 | 8.996779881e-07 | 2.24919497e-06 | 0 | OFF | 0.0002777778427 | OFF | OFF -> OFF | 1 | 0.2925000001 | time IDLE (hr, min, %) | 0.06277777761 | 3.766666657 | 3.489269714% |  | 0.2636334788 | total wasted energy
8:03:22 | 0.01 | 0.00323884 | 8.996779881e-07 | 2.24919497e-06 | 0 | OFF | 0.0002777778427 | OFF | OFF -> OFF | 1 | 0.2925000001 | time CUTTING (hr, min, %) | 0.5938888892 | 35.63333335 | 33.00910917% |  | 15.53234254% | percentage of energy that didn't generate production
8:03:23 | 0.01 | 0.00323884 | 8.996774225e-07 | 2.249193556e-06 | 0 | OFF | 0.0002777776681 | OFF | OFF -> OFF | 1 | 0.2925000001 | time FAULT (hr, min, %) | 0.009166666714 | 0.5500000028 | 0.5094951392%
8:03:24 | 0.01 | 0.00323884 | 8.996779881e-07 | 2.24919497e-06 | 0 | OFF | 0.0002777778427 | OFF | OFF -> OFF | 1 | 0.2925000001 | total time (hr, min) | 1.799166667 | 107.95 |  | cycle changes
8:03:25 | 0.01 | 0.00323884 | 8.996774225e-07 | 2.249193556e-06 | 0 | OFF | 0.0002777776681 | OFF | OFF -> OFF | 1 | 0.2925000001 |  |  |  |  | transition | # of events
8:03:26 | 0.01 | 0.00323884 | 8.996779881e-07 | 2.24919497e-06 | 0 | OFF | 0.0002777778427 | OFF | OFF -> OFF | 1 | 0.2925000001 | total cost ($ MXN) | $4.24 |  |  | OFF -> IDLE | 4 | machine start-up = frequent shutdowns
8:03:27 | 0.01 | 0.00323884 | 8.996779881e-07 | 2.24919497e-06 | 0 | OFF | 0.0002777778427 | OFF | OFF -> OFF | 1 | 0.2925000001 |  |  |  |  | IDLE -> CUTTING | 27 | production start-up = constant restarts
8:03:28 | 0.01 | 0.00323884 | 8.996774225e-07 | 2.249193556e-06 | 0 | OFF | 0.0002777776681 | OFF | OFF -> OFF | 1 | 0.2925000001 |  |  |  |  | CUTTING -> IDLE | 37 | normal shutdown = microstops
8:03:29 | 0.01 | 0.00323884 | 8.996779881e-07 | 2.24919497e-06 | 0 | OFF | 0.0002777778427 | OFF | OFF -> OFF | 1 | 0.2925000001 |  |  |  |  | IDLE -> OFF | 14 | total shutdown
8:03:30 | 0.01 | 0.00323884 | 8.996779881e-07 | 2.24919497e-06 | 0 | OFF | 0.0002777778427 | OFF | OFF -> OFF | 1 | 0.2925000001 |  |  |  |  | CUTTING -> FAULT | 2 | incoming faults
8:03:31 | 0.01 | 0.00323884 | 8.996774225e-07 | 2.249193556e-06 | 0 | OFF | 0.0002777776681 | OFF | OFF -> OFF | 1 | 0.2925000001 |  |  |  |  | FAULT -> IDLE | 0 | recovery faults
8:03:32 | 0.01 | 0.00323884 | 8.996779881e-07 | 2.24919497e-06 | 0 | OFF | 0.0002777778427 | OFF | OFF -> OFF | 1 | 0.2925000001
8:03:33 | 0.01 | 0.00323884 | 8.996774225e-07 | 2.249193556e-06 | 0 | OFF | 0.0002777776681 | OFF | OFF -> OFF | 1 | 0.2925000001 |  |  |  |  | maximum continuous analysis
8:03:34 | 0.01 | 0.00323884 | 8.996779881e-07 | 2.24919497e-06 | 0 | OFF | 0.0002777778427 | OFF | OFF -> OFF | 1 | 0.2925000001 |  |  |  |  | state | hours | minutes
8:03:35 | 0.01 | 0.00323884 | 8.996779881e-07 | 2.24919497e-06 | 0 | OFF | 0.0002777778427 | OFF | OFF -> OFF | 1 | 0.2925000001 |  |  |  |  | OFF | 0.2925000001 | 17.55000001
8:03:36 | 0.01 | 0.00323884 | 8.996774225e-07 | 2.249193556e-06 | 0 | OFF | 0.0002777776681 | OFF | OFF -> OFF | 1 | 0.2925000001 |  |  |  |  | CUTTING | 0.06861111108 | 4.116666665
8:03:37 | 0.01 | 0.00323884 | 8.996779881e-07 | 2.24919497e-06 | 0 | OFF | 0.0002777778427 | OFF | OFF -> OFF | 1 | 0.2925000001 |  |  |  |  | IDLE | 0.01611111121 | 0.9666666726
8:03:38 | 0.01 | 0.00323884 | 8.996779881e-07 | 2.24919497e-06 | 0 | OFF | 0.0002777778427 | OFF | OFF -> OFF | 1 | 0.2925000001 |  |  |  |  | FAULT | 0.00194444455 | 0.116666673
8:03:39 | 0.01 | 0.00323884 | 8.996774225e-07 | 2.249193556e-06 | 0 | OFF | 0.0002777776681 | OFF | OFF -> OFF | 1 | 0.2925000001
8:03:40 | 0.01 | 0.00323884 | 8.996779881e-07 | 2.24919497e-06 | 0 | OFF | 0.0002777778427 | OFF | OFF -> OFF | 1 | 0.2925000001
8:03:41 | 0.01 | 0.00323884 | 8.996774225e-07 | 2.249193556e-06 | 0 | OFF | 0.0002777776681 | OFF | OFF -> OFF | 1 | 0.2925000001
8:03:42 | 0.01 | 0.00323884 | 8.996779881e-07 | 2.24919497e-06 | 0 | OFF | 0.0002777778427 | OFF | OFF -> OFF | 1 | 0.2925000001
8:03:43 | 0.01 | 0.00323884 | 8.996779881e-07 | 2.24919497e-06 | 0 | OFF | 0.0002777778427 | OFF | OFF -> OFF | 1 | 0.2925000001
8:03:44 | 0.01 | 0.00323884 | 8.996774225e-07 | 2.249193556e-06 | 0 | OFF | 0.0002777776681 | OFF | OFF -> OFF | 1 | 0.2925000001
8:03:45 | 0.01 | 0.00323884 | 8.996779881e-07 | 2.24919497e-06 | 0 | OFF | 0.0002777778427 | OFF | OFF -> OFF | 1 | 0.2925000001
8:05:42 | 0.01 | 0.00323884 | 0.0001052622997 | 0.0002631557493 | 0 | OFF | 0.03249999991 | OFF | OFF -> OFF | 1 | 0.2925000001
8:05:43 | 0.01 | 0.00323884 | 8.996779881e-07 | 2.24919497e-06 | 0 | OFF | 0.0002777778427 | OFF | OFF -> OFF | 1 | 0.2925000001
8:05:44 | 0.01 | 0.00323884 | 8.996779881e-07 | 2.24919497e-06 | 0 | OFF | 0.0002777778427 | OFF | OFF -> OFF | 1 | 0.2925000001
8:05:45 | 0.01 | 0.00323884 | 8.996774225e-07 | 2.249193556e-06 | 0 | OFF | 0.0002777776681 | OFF | OFF -> OFF | 1 | 0.2925000001
8:05:46 | 0.01 | 0.00323884 | 8.996779881e-07 | 2.24919497e-06 | 0 | OFF | 0.0002777778427 | OFF | OFF -> OFF | 1 | 0.2925000001
8:05:52 | 0.01 | 0.00323884 | 5.398066797e-06 | 1.349516699e-05 | 0 | OFF | 0.001666666707 | OFF | OFF -> OFF | 1 | 0.2925000001
8:15:30 | 0.01 | 0.00323884 | 0.0005200137555 | 0.001300034389 | 0 | OFF | 0.1605555555 | OFF | OFF -> OFF | 1 | 0.2925000001
8:15:32 | 0.01 | 0.00323884 | 1.799355411e-06 | 4.498388527e-06 | 0 | OFF | 0.0005555555108 | OFF | OFF -> OFF | 1 | 0.2925000001
8:15:33 | 0.01 | 0.00323884 | 8.996779881e-07 | 2.24919497e-06 | 0 | OFF | 0.0002777778427 | OFF | OFF -> OFF | 1 | 0.2925000001
8:15:34 | 0.01 | 0.00323884 | 8.996774225e-07 | 2.249193556e-06 | 0 | OFF | 0.0002777776681 | OFF | OFF -> OFF | 1 | 0.2925000001
8:15:35 | 0.01 | 0.00323884 | 8.996779881e-07 | 2.24919497e-06 | 0 | OFF | 0.0002777778427 | OFF | OFF -> OFF | 1 | 0.2925000001
8:15:36 | 0.01 | 0.00323884 | 8.996779881e-07 | 2.24919497e-06 | 0 | OFF | 0.0002777778427 | OFF | OFF -> OFF | 1 | 0.2925000001
8:15:37 | 0.01 | 0.00323884 | 8.996774225e-07 | 2.249193556e-06 | 0 | OFF | 0.0002777776681 | OFF | OFF -> OFF | 1 | 0.2925000001
8:15:38 | 0.01 | 0.00323884 | 8.996779881e-07 | 2.24919497e-06 | 0 | OFF | 0.0002777778427 | OFF | OFF -> OFF | 1 | 0.2925000001
8:15:39 | 0.01 | 0.00323884 | 8.996774225e-07 | 2.249193556e-06 | 0 | OFF | 0.0002777776681 | OFF | OFF -> OFF | 1 | 0.2925000001
8:15:40 | 0.01 | 0.00323884 | 8.996779881e-07 | 2.24919497e-06 | 0 | OFF | 0.0002777778427 | OFF | OFF -> OFF | 1 | 0.2925000001
8:15:41 | 0.01 | 0.00323884 | 8.996779881e-07 | 2.24919497e-06 | 0 | OFF | 0.0002777778427 | OFF | OFF -> OFF | 1 | 0.2925000001
8:15:42 | 0.01 | 0.00323884 | 8.996774225e-07 | 2.249193556e-06 | 0 | OFF | 0.0002777776681 | OFF | OFF -> OFF | 1 | 0.2925000001
8:15:43 | 0.01 | 0.00323884 | 8.996779881e-07 | 2.24919497e-06 | 0 | OFF | 0.0002777778427 | OFF | OFF -> OFF | 1 | 0.2925000001
8:15:44 | 0.01 | 0.00323884 | 8.996779881e-07 | 2.24919497e-06 | 0 | OFF | 0.0002777778427 | OFF | OFF -> OFF | 1 | 0.2925000001
8:15:45 | 0.01 | 0.00323884 | 8.996774225e-07 | 2.249193556e-06 | 0 | OFF | 0.0002777776681 | OFF | OFF -> OFF | 1 | 0.2925000001
8:15:46 | 0.01 | 0.00323884 | 8.996779881e-07 | 2.24919497e-06 | 0 | OFF | 0.0002777778427 | OFF | OFF -> OFF | 1 | 0.2925000001
8:15:47 | 0.01 | 0.00323884 | 8.996779881e-07 | 2.24919497e-06 | 0 | OFF | 0.0002777778427 | OFF | OFF -> OFF | 1 | 0.2925000001
8:15:48 | 0.01 | 0.00323884 | 8.996774225e-07 | 2.249193556e-06 | 0 | OFF | 0.0002777776681 | OFF | OFF -> OFF | 1 | 0.2925000001
8:15:49 | 0.01 | 0.00323884 | 8.996779881e-07 | 2.24919497e-06 | 0 | OFF | 0.0002777778427 | OFF | OFF -> OFF | 1 | 0.2925000001
8:15:50 | 0.01 | 0.00323884 | 8.996774225e-07 | 2.249193556e-06 | 0 | OFF | 0.0002777776681 | OFF | OFF -> OFF | 1 | 0.2925000001
8:15:51 | 0.01 | 0.00323884 | 8.996779881e-07 | 2.24919497e-06 | 0 | OFF | 0.0002777778427 | OFF | OFF -> OFF | 1 | 0.2925000001
8:15:52 | 0.01 | 0.00323884 | 8.996779881e-07 | 2.24919497e-06 | 0 | OFF | 0.0002777778427 | OFF | OFF -> OFF | 1 | 0.2925000001
8:15:53 | 0.01 | 0.00323884 | 8.996774225e-07 | 2.249193556e-06 | 0 | OFF | 0.0002777776681 | OFF | OFF -> OFF | 1 | 0.2925000001
8:15:54 | 0.01 | 0.00323884 | 8.996779881e-07 | 2.24919497e-06 | 0 | OFF | 0.0002777778427 | OFF | OFF -> OFF | 1 | 0.2925000001
8:15:55 | 0.01 | 0.00323884 | 8.996779881e-07 | 2.24919497e-06 | 0 | OFF | 0.0002777778427 | OFF | OFF -> OFF | 1 | 0.2925000001
8:15:56 | 0.01 | 0.00323884 | 8.996774225e-07 | 2.249193556e-06 | 0 | OFF | 0.0002777776681 | OFF | OFF -> OFF | 1 | 0.2925000001
8:15:57 | 0.01 | 0.00323884 | 8.996779881e-07 | 2.24919497e-06 | 0 | OFF | 0.0002777778427 | OFF | OFF -> OFF | 1 | 0.2925000001
8:15:58 | 0.01 | 0.00323884 | 8.996774225e-07 | 2.249193556e-06 | 0 | OFF | 0.0002777776681 | OFF | OFF -> OFF | 1 | 0.2925000001
8:15:59 | 0.01 | 0.00323884 | 8.996779881e-07 | 2.24919497e-06 | 0 | OFF | 0.0002777778427 | OFF | OFF -> OFF | 1 | 0.2925000001
8:16:00 | 0.01 | 0.00323884 | 8.996779881e-07 | 2.24919497e-06 | 0 | OFF | 0.0002777778427 | OFF | OFF -> OFF | 1 | 0.2925000001
8:16:01 | 0.01 | 0.00323884 | 8.996774225e-07 | 2.249193556e-06 | 0 | OFF | 0.0002777776681 | OFF | OFF -> OFF | 1 | 0.2925000001
8:16:02 | 0.01 | 0.00323884 | 8.996779881e-07 | 2.24919497e-06 | 0 | OFF | 0.0002777778427 | OFF | OFF -> OFF | 1 | 0.2925000001
8:16:03 | 0.01 | 0.00323884 | 8.996779881e-07 | 2.24919497e-06 | 0 | OFF | 0.0002777778427 | OFF | OFF -> OFF | 1 | 0.2925000001
8:16:04 | 0.01 | 0.00323884 | 8.996774225e-07 | 2.249193556e-06 | 0 | OFF | 0.0002777776681 | OFF | OFF -> OFF | 1 | 0.2925000001
8:16:05 | 0.01 | 0.00323884 | 8.996779881e-07 | 2.24919497e-06 | 0 | OFF | 0.0002777778427 | OFF | OFF -> OFF | 1 | 0.2925000001
8:16:06 | 0.01 | 0.00323884 | 8.996774225e-07 | 2.249193556e-06 | 0 | OFF | 0.0002777776681 | OFF | OFF -> OFF | 1 | 0.2925000001
8:16:07 | 0.01 | 0.00323884 | 8.996779881e-07 | 2.24919497e-06 | 0 | OFF | 0.0002777778427 | OFF | OFF -> OFF | 1 | 0.2925000001
8:16:08 | 0.01 | 0.00323884 | 8.996779881e-07 | 2.24919497e-06 | 0 | OFF | 0.0002777778427 | OFF | OFF -> OFF | 1 | 0.2925000001
8:16:09 | 0.01 | 0.00323884 | 8.996774225e-07 | 2.249193556e-06 | 0 | OFF | 0.0002777776681 | OFF | OFF -> OFF | 1 | 0.2925000001
8:16:10 | 0.01 | 0.00323884 | 8.996779881e-07 | 2.24919497e-06 | 0 | OFF | 0.0002777778427 | OFF | OFF -> OFF | 1 | 0.2925000001
8:16:11 | 0.01 | 0.00323884 | 8.996779881e-07 | 2.24919497e-06 | 0 | OFF | 0.0002777778427 | OFF | OFF -> OFF | 1 | 0.2925000001
8:16:12 | 0.01 | 0.00323884 | 8.996774225e-07 | 2.249193556e-06 | 0 | OFF | 0.0002777776681 | OFF | OFF -> OFF | 1 | 0.2925000001
8:16:13 | 0.01 | 0.00323884 | 8.996779881e-07 | 2.24919497e-06 | 0 | OFF | 0.0002777778427 | OFF | OFF -> OFF | 1 | 0.2925000001
8:16:14 | 0.01 | 0.00323884 | 8.996774225e-07 | 2.249193556e-06 | 0 | OFF | 0.0002777776681 | OFF | OFF -> OFF | 1 | 0.2925000001
8:16:15 | 0.01 | 0.00323884 | 8.996779881e-07 | 2.24919497e-06 | 0 | OFF | 0.0002777778427 | OFF | OFF -> OFF | 1 | 0.2925000001
8:16:16 | 0.01 | 0.00323884 | 8.996779881e-07 | 2.24919497e-06 | 0 | OFF | 0.0002777778427 | OFF | OFF -> OFF | 1 | 0.2925000001
8:16:17 | 0.01 | 0.00323884 | 8.996774225e-07 | 2.249193556e-06 | 0 | OFF | 0.0002777776681 | OFF | OFF -> OFF | 1 | 0.2925000001
8:16:18 | 0.01 | 0.00323884 | 8.996779881e-07 | 2.24919497e-06 | 0 | OFF | 0.0002777778427 | OFF | OFF -> OFF | 1 | 0.2925000001
8:16:19 | 0.01 | 0.00323884 | 8.996779881e-07 | 2.24919497e-06 | 0 | OFF | 0.0002777778427 | OFF | OFF -> OFF | 1 | 0.2925000001
8:16:20 | 0.01 | 0.00323884 | 8.996774225e-07 | 2.249193556e-06 | 0 | OFF | 0.0002777776681 | OFF | OFF -> OFF | 1 | 0.2925000001
8:16:21 | 0.01 | 0.00323884 | 8.996779881e-07 | 2.24919497e-06 | 0 | OFF | 0.0002777778427 | OFF | OFF -> OFF | 1 | 0.2925000001
8:16:22 | 0.01 | 0.00323884 | 8.996779881e-07 | 2.24919497e-06 | 0 | OFF | 0.0002777778427 | OFF | OFF -> OFF | 1 | 0.2925000001
8:16:23 | 0.01 | 0.00323884 | 8.996774225e-07 | 2.249193556e-06 | 0 | OFF | 0.0002777776681 | OFF | OFF -> OFF | 1 | 0.2925000001
8:16:24 | 0.01 | 0.00323884 | 8.996779881e-07 | 2.24919497e-06 | 0 | OFF | 0.0002777778427 | OFF | OFF -> OFF | 1 | 0.2925000001
8:16:25 | 0.01 | 0.00323884 | 8.996774225e-07 | 2.249193556e-06 | 0 | OFF | 0.0002777776681 | OFF | OFF -> OFF | 1 | 0.2925000001
8:16:26 | 0.01 | 0.00323884 | 8.996779881e-07 | 2.24919497e-06 | 0 | OFF | 0.0002777778427 | OFF | OFF -> OFF | 1 | 0.2925000001
8:16:27 | 0.01 | 0.00323884 | 8.996779881e-07 | 2.24919497e-06 | 0 | OFF | 0.0002777778427 | OFF | OFF -> OFF | 1 | 0.2925000001
8:16:28 | 0.01 | 0.00323884 | 8.996774225e-07 | 2.249193556e-06 | 0 | OFF | 0.0002777776681 | OFF | OFF -> OFF | 1 | 0.2925000001
8:16:29 | 0.01 | 0.00323884 | 8.996779881e-07 | 2.24919497e-06 | 0 | OFF | 0.0002777778427 | OFF | OFF -> OFF | 1 | 0.2925000001
8:16:30 | 0.01 | 0.00323884 | 8.996779881e-07 | 2.24919497e-06 | 0 | OFF | 0.0002777778427 | OFF | OFF -> OFF | 1 | 0.2925000001
8:16:31 | 0.01 | 0.00323884 | 8.996774225e-07 | 2.249193556e-06 | 0 | OFF | 0.0002777776681 | OFF | OFF -> OFF | 1 | 0.2925000001
8:16:32 | 0.01 | 0.00323884 | 8.996779881e-07 | 2.24919497e-06 | 0 | OFF | 0.0002777778427 | OFF | OFF -> OFF | 1 | 0.2925000001
8:16:33 | 0.01 | 0.00323884 | 8.996774225e-07 | 2.249193556e-06 | 0 | OFF | 0.0002777776681 | OFF | OFF -> OFF | 1 | 0.2925000001
8:16:34 | 0.01 | 0.00323884 | 8.996779881e-07 | 2.24919497e-06 | 0 | OFF | 0.0002777778427 | OFF | OFF -> OFF | 1 | 0.2925000001
8:16:35 | 0.01 | 0.00323884 | 8.996779881e-07 | 2.24919497e-06 | 0 | OFF | 0.0002777778427 | OFF | OFF -> OFF | 1 | 0.2925000001
8:16:36 | 0.01 | 0.00323884 | 8.996774225e-07 | 2.249193556e-06 | 0 | OFF | 0.0002777776681 | OFF | OFF -> OFF | 1 | 0.2925000001
8:16:37 | 0.01 | 0.00323884 | 8.996779881e-07 | 2.24919497e-06 | 0 | OFF | 0.0002777778427 | OFF | OFF -> OFF | 1 | 0.2925000001
8:16:38 | 0.01 | 0.00323884 | 8.996779881e-07 | 2.24919497e-06 | 0 | OFF | 0.0002777778427 | OFF | OFF -> OFF | 1 | 0.2925000001
8:16:39 | 0.01 | 0.00323884 | 8.996774225e-07 | 2.249193556e-06 | 0 | OFF | 0.0002777776681 | OFF | OFF -> OFF | 1 | 0.2925000001
8:16:40 | 0.01 | 0.00323884 | 8.996779881e-07 | 2.24919497e-06 | 0 | OFF | 0.0002777778427 | OFF | OFF -> OFF | 1 | 0.2925000001
8:16:41 | 0.01 | 0.00323884 | 8.996774225e-07 | 2.249193556e-06 | 0 | OFF | 0.0002777776681 | OFF | OFF -> OFF | 1 | 0.2925000001
8:16:42 | 0.01 | 0.00323884 | 8.996779881e-07 | 2.24919497e-06 | 0 | OFF | 0.0002777778427 | OFF | OFF -> OFF | 1 | 0.2925000001
8:16:43 | 0.01 | 0.00323884 | 8.996779881e-07 | 2.24919497e-06 | 0 | OFF | 0.0002777778427 | OFF | OFF -> OFF | 1 | 0.2925000001
8:16:44 | 0.01 | 0.00323884 | 8.996774225e-07 | 2.249193556e-06 | 0 | OFF | 0.0002777776681 | OFF | OFF -> OFF | 1 | 0.2925000001
8:16:45 | 0.01 | 0.00323884 | 8.996779881e-07 | 2.24919497e-06 | 0 | OFF | 0.0002777778427 | OFF | OFF -> OFF | 1 | 0.2925000001
8:16:46 | 0.01 | 0.00323884 | 8.996779881e-07 | 2.24919497e-06 | 0 | OFF | 0.0002777778427 | OFF | OFF -> OFF | 1 | 0.2925000001
8:16:47 | 0.01 | 0.00323884 | 8.996774225e-07 | 2.249193556e-06 | 0 | OFF | 0.0002777776681 | OFF | OFF -> OFF | 1 | 0.2925000001
8:16:48 | 0.01 | 0.00323884 | 8.996779881e-07 | 2.24919497e-06 | 0 | OFF | 0.0002777778427 | OFF | OFF -> OFF | 1 | 0.2925000001
8:16:49 | 0.01 | 0.00323884 | 8.996774225e-07 | 2.249193556e-06 | 0 | OFF | 0.0002777776681 | OFF | OFF -> OFF | 1 | 0.2925000001
8:16:50 | 0.01 | 0.00323884 | 8.996779881e-07 | 2.24919497e-06 | 0 | OFF | 0.0002777778427 | OFF | OFF -> OFF | 1 | 0.2925000001
8:16:51 | 0.01 | 0.00323884 | 8.996779881e-07 | 2.24919497e-06 | 0 | OFF | 0.0002777778427 | OFF | OFF -> OFF | 1 | 0.2925000001
8:16:52 | 0.01 | 0.00323884 | 8.996774225e-07 | 2.249193556e-06 | 0 | OFF | 0.0002777776681 | OFF | OFF -> OFF | 1 | 0.2925000001
8:16:53 | 0.01 | 0.00323884 | 8.996779881e-07 | 2.24919497e-06 | 0 | OFF | 0.0002777778427 | OFF | OFF -> OFF | 1 | 0.2925000001
8:16:54 | 0.01 | 0.00323884 | 8.996779881e-07 | 2.24919497e-06 | 0 | OFF | 0.0002777778427 | OFF | OFF -> OFF | 1 | 0.2925000001
8:16:55 | 0.01 | 0.00323884 | 8.996774225e-07 | 2.249193556e-06 | 0 | OFF | 0.0002777776681 | OFF | OFF -> OFF | 1 | 0.2925000001
8:16:56 | 0.01 | 0.00323884 | 8.996779881e-07 | 2.24919497e-06 | 0 | OFF | 0.0002777778427 | OFF | OFF -> OFF | 1 | 0.2925000001
8:16:57 | 0.01 | 0.00323884 | 8.996774225e-07 | 2.249193556e-06 | 0 | OFF | 0.0002777776681 | OFF | OFF -> OFF | 1 | 0.2925000001
8:16:58 | 0.01 | 0.00323884 | 8.996779881e-07 | 2.24919497e-06 | 0 | OFF | 0.0002777778427 | OFF | OFF -> OFF | 1 | 0.2925000001
8:16:59 | 0.01 | 0.00323884 | 8.996779881e-07 | 2.24919497e-06 | 0 | OFF | 0.0002777778427 | OFF | OFF -> OFF | 1 | 0.2925000001
8:17:01 | 0.01 | 0.00323884 | 1.799355411e-06 | 4.498388527e-06 | 0 | OFF | 0.0005555555108 | OFF | OFF -> OFF | 1 | 0.2925000001
8:17:02 | 0.01 | 0.00323884 | 8.996779881e-07 | 2.24919497e-06 | 0 | OFF | 0.0002777778427 | OFF | OFF -> OFF | 1 | 0.2925000001
8:17:03 | 0.01 | 0.00323884 | 8.996774225e-07 | 2.249193556e-06 | 0 | OFF | 0.0002777776681 | OFF | OFF -> OFF | 1 | 0.2925000001
8:17:04 | 0.01 | 0.00323884 | 8.996779881e-07 | 2.24919497e-06 | 0 | OFF | 0.0002777778427 | OFF | OFF -> OFF | 1 | 0.2925000001
8:17:05 | 0.01 | 0.00323884 | 8.996779881e-07 | 2.24919497e-06 | 0 | OFF | 0.0002777778427 | OFF | OFF -> OFF | 1 | 0.2925000001
8:17:06 | 0.01 | 0.00323884 | 8.996774225e-07 | 2.249193556e-06 | 0 | OFF | 0.0002777776681 | OFF | OFF -> OFF | 1 | 0.2925000001
8:17:07 | 0.01 | 0.00323884 | 8.996779881e-07 | 2.24919497e-06 | 0 | OFF | 0.0002777778427 | OFF | OFF -> OFF | 1 | 0.2925000001
8:17:08 | 0.01 | 0.00323884 | 8.996774225e-07 | 2.249193556e-06 | 0 | OFF | 0.0002777776681 | OFF | OFF -> OFF | 1 | 0.2925000001
8:17:09 | 0.01 | 0.00323884 | 8.996779881e-07 | 2.24919497e-06 | 0 | OFF | 0.0002777778427 | OFF | OFF -> OFF | 1 | 0.2925000001
8:17:10 | 0.01 | 0.00323884 | 8.996779881e-07 | 2.24919497e-06 | 0 | OFF | 0.0002777778427 | OFF | OFF -> OFF | 1 | 0.2925000001
8:17:11 | 0.01 | 0.00323884 | 8.996774225e-07 | 2.249193556e-06 | 0 | OFF | 0.0002777776681 | OFF | OFF -> OFF | 1 | 0.2925000001
8:17:12 | 0.01 | 0.00323884 | 8.996779881e-07 | 2.24919497e-06 | 0 | OFF | 0.0002777778427 | OFF | OFF -> OFF | 1 | 0.2925000001
8:17:13 | 0.01 | 0.00323884 | 8.996779881e-07 | 2.24919497e-06 | 0 | OFF | 0.0002777778427 | OFF | OFF -> OFF | 1 | 0.2925000001
8:17:14 | 0.01 | 0.00323884 | 8.996774225e-07 | 2.249193556e-06 | 0 | OFF | 0.0002777776681 | OFF | OFF -> OFF | 1 | 0.2925000001
8:17:15 | 0.01 | 0.00323884 | 8.996779881e-07 | 2.24919497e-06 | 0 | OFF | 0.0002777778427 | OFF | OFF -> OFF | 1 | 0.2925000001
8:17:16 | 0.01 | 0.00323884 | 8.996774225e-07 | 2.249193556e-06 | 0 | OFF | 0.0002777776681 | OFF | OFF -> OFF | 1 | 0.2925000001
8:17:17 | 0.01 | 0.00323884 | 8.996779881e-07 | 2.24919497e-06 | 0 | OFF | 0.0002777778427 | OFF | OFF -> OFF | 1 | 0.2925000001
8:17:18 | 0.01 | 0.00323884 | 8.996779881e-07 | 2.24919497e-06 | 0 | OFF | 0.0002777778427 | OFF | OFF -> OFF | 1 | 0.2925000001
8:17:19 | 0.01 | 0.00323884 | 8.996774225e-07 | 2.249193556e-06 | 0 | OFF | 0.0002777776681 | OFF | OFF -> OFF | 1 | 0.2925000001
8:17:20 | 0.01 | 0.00323884 | 8.996779881e-07 | 2.24919497e-06 | 0 | OFF | 0.0002777778427 | OFF | OFF -> OFF | 1 | 0.2925000001
8:17:21 | 0.01 | 0.00323884 | 8.996779881e-07 | 2.24919497e-06 | 0 | OFF | 0.0002777778427 | OFF | OFF -> OFF | 1 | 0.2925000001
8:17:22 | 0.01 | 0.00323884 | 8.996774225e-07 | 2.249193556e-06 | 0 | OFF | 0.0002777776681 | OFF | OFF -> OFF | 1 | 0.2925000001
8:17:23 | 0.01 | 0.00323884 | 8.996779881e-07 | 2.24919497e-06 | 0 | OFF | 0.0002777778427 | OFF | OFF -> OFF | 1 | 0.2925000001
8:17:24 | 0.01 | 0.00323884 | 8.996774225e-07 | 2.249193556e-06 | 0 | OFF | 0.0002777776681 | OFF | OFF -> OFF | 1 | 0.2925000001
8:17:25 | 0.01 | 0.00323884 | 8.996779881e-07 | 2.24919497e-06 | 0 | OFF | 0.0002777778427 | OFF | OFF -> OFF | 1 | 0.2925000001
8:17:26 | 0.01 | 0.00323884 | 8.996779881e-07 | 2.24919497e-06 | 0 | OFF | 0.0002777778427 | OFF | OFF -> OFF | 1 | 0.2925000001
8:17:27 | 0.01 | 0.00323884 | 8.996774225e-07 | 2.249193556e-06 | 0 | OFF | 0.0002777776681 | OFF | OFF -> OFF | 1 | 0.2925000001
8:17:28 | 0.01 | 0.00323884 | 8.996779881e-07 | 2.24919497e-06 | 0 | OFF | 0.0002777778427 | OFF | OFF -> OFF | 1 | 0.2925000001
8:17:29 | 0.01 | 0.00323884 | 8.996779881e-07 | 2.24919497e-06 | 0 | OFF | 0.0002777778427 | OFF | OFF -> OFF | 1 | 0.2925000001
8:17:30 | 0.01 | 0.00323884 | 8.996774225e-07 | 2.249193556e-06 | 0 | OFF | 0.0002777776681 | OFF | OFF -> OFF | 1 | 0.2925000001
8:17:31 | 0.01 | 0.00323884 | 8.996779881e-07 | 2.24919497e-06 | 0 | OFF | 0.0002777778427 | OFF | OFF -> OFF | 1 | 0.2925000001
8:17:32 | 0.01 | 0.00323884 | 8.996774225e-07 | 2.249193556e-06 | 0 | OFF | 0.0002777776681 | OFF | OFF -> OFF | 1 | 0.2925000001
8:17:33 | 0.01 | 0.00323884 | 8.996779881e-07 | 2.24919497e-06 | 0 | OFF | 0.0002777778427 | OFF | OFF -> OFF | 1 | 0.2925000001
8:17:34 | 0.01 | 0.00323884 | 8.996779881e-07 | 2.24919497e-06 | 0 | OFF | 0.0002777778427 | OFF | OFF -> OFF | 1 | 0.2925000001
8:17:35 | 0.01 | 0.00323884 | 8.996774225e-07 | 2.249193556e-06 | 0 | OFF | 0.0002777776681 | OFF | OFF -> OFF | 1 | 0.2925000001
8:17:36 | 0.01 | 0.00323884 | 8.996779881e-07 | 2.24919497e-06 | 0 | OFF | 0.0002777778427 | OFF | OFF -> OFF | 1 | 0.2925000001
8:17:37 | 0.01 | 0.00323884 | 8.996779881e-07 | 2.24919497e-06 | 0 | OFF | 0.0002777778427 | OFF | OFF -> OFF | 1 | 0.2925000001
8:17:38 | 0.01 | 0.00323884 | 8.996774225e-07 | 2.249193556e-06 | 0 | OFF | 0.0002777776681 | OFF | OFF -> OFF | 1 | 0.2925000001
8:17:39 | 0.01 | 0.00323884 | 8.996779881e-07 | 2.24919497e-06 | 0 | OFF | 0.0002777778427 | OFF | OFF -> OFF | 1 | 0.2925000001
8:17:40 | 0.01 | 0.00323884 | 8.996779881e-07 | 2.24919497e-06 | 0 | OFF | 0.0002777778427 | OFF | OFF -> OFF | 1 | 0.2925000001
8:17:41 | 0.01 | 0.00323884 | 8.996774225e-07 | 2.249193556e-06 | 0 | OFF | 0.0002777776681 | OFF | OFF -> OFF | 1 | 0.2925000001
8:17:42 | 0.01 | 0.00323884 | 8.996779881e-07 | 2.24919497e-06 | 0 | OFF | 0.0002777778427 | OFF | OFF -> OFF | 1 | 0.2925000001
8:17:43 | 0.04 | 0.01295536 | 3.59870969e-06 | 8.996774225e-06 | 0 | OFF | 0.0002777776681 | OFF | OFF -> OFF | 1 | 0.2925000001
8:17:44 | 0.04 | 0.01295536 | 3.598711952e-06 | 8.996779881e-06 | 0 | OFF | 0.0002777778427 | OFF | OFF -> OFF | 1 | 0.2925000001
8:17:45 | 0.04 | 0.01295536 | 3.598711952e-06 | 8.996779881e-06 | 0 | OFF | 0.0002777778427 | OFF | OFF -> OFF | 1 | 0.2925000001
8:17:46 | 0.03 | 0.00971652 | 2.699032268e-06 | 6.747580669e-06 | 0 | OFF | 0.0002777776681 | OFF | OFF -> OFF | 1 | 0.2925000001
8:17:47 | 0.03 | 0.00971652 | 2.699033964e-06 | 6.747584911e-06 | 0 | OFF | 0.0002777778427 | OFF | OFF -> OFF | 1 | 0.2925000001
8:17:48 | 0.03 | 0.00971652 | 2.699033964e-06 | 6.747584911e-06 | 0 | OFF | 0.0002777778427 | OFF | OFF -> OFF | 1 | 0.2925000001
8:17:49 | 0.03 | 0.00971652 | 2.699032268e-06 | 6.747580669e-06 | 0 | OFF | 0.0002777776681 | OFF | OFF -> OFF | 1 | 0.2925000001
8:17:50 | 0.02 | 0.00647768 | 1.799355976e-06 | 4.49838994e-06 | 0 | OFF | 0.0002777778427 | OFF | OFF -> OFF | 1 | 0.2925000001
8:17:51 | 0.02 | 0.00647768 | 1.799354845e-06 | 4.498387113e-06 | 0 | OFF | 0.0002777776681 | OFF | OFF -> OFF | 1 | 0.2925000001
8:17:52 | 0.02 | 0.00647768 | 1.799355976e-06 | 4.49838994e-06 | 0 | OFF | 0.0002777778427 | OFF | OFF -> OFF | 1 | 0.2925000001
8:17:53 | 0.02 | 0.00647768 | 1.799355976e-06 | 4.49838994e-06 | 0 | OFF | 0.0002777778427 | OFF | OFF -> OFF | 1 | 0.2925000001
8:17:54 | 0.02 | 0.00647768 | 1.799354845e-06 | 4.498387113e-06 | 0 | OFF | 0.0002777776681 | OFF | OFF -> OFF | 1 | 0.2925000001
8:17:55 | 0.02 | 0.00647768 | 1.799355976e-06 | 4.49838994e-06 | 0 | OFF | 0.0002777778427 | OFF | OFF -> OFF | 1 | 0.2925000001
8:17:56 | 0.02 | 0.00647768 | 1.799355976e-06 | 4.49838994e-06 | 0 | OFF | 0.0002777778427 | OFF | OFF -> OFF | 1 | 0.2925000001
8:17:57 | 0.02 | 0.00647768 | 1.799354845e-06 | 4.498387113e-06 | 0 | OFF | 0.0002777776681 | OFF | OFF -> OFF | 1 | 0.2925000001
8:17:58 | 0.02 | 0.00647768 | 1.799355976e-06 | 4.49838994e-06 | 0 | OFF | 0.0002777778427 | OFF | OFF -> OFF | 1 | 0.2925000001
8:17:59 | 0.02 | 0.00647768 | 1.799354845e-06 | 4.498387113e-06 | 0 | OFF | 0.0002777776681 | OFF | OFF -> OFF | 1 | 0.2925000001
8:18:00 | 0.02 | 0.00647768 | 1.799355976e-06 | 4.49838994e-06 | 0 | OFF | 0.0002777778427 | OFF | OFF -> OFF | 1 | 0.2925000001
8:18:01 | 0.02 | 0.00647768 | 1.799355976e-06 | 4.49838994e-06 | 0 | OFF | 0.0002777778427 | OFF | OFF -> OFF | 1 | 0.2925000001
8:18:02 | 0.02 | 0.00647768 | 1.799354845e-06 | 4.498387113e-06 | 0 | OFF | 0.0002777776681 | OFF | OFF -> OFF | 1 | 0.2925000001
8:18:03 | 0.02 | 0.00647768 | 1.799355976e-06 | 4.49838994e-06 | 0 | OFF | 0.0002777778427 | OFF | OFF -> OFF | 1 | 0.2925000001
8:18:04 | 0.02 | 0.00647768 | 1.799355976e-06 | 4.49838994e-06 | 0 | OFF | 0.0002777778427 | OFF | OFF -> OFF | 1 | 0.2925000001
8:18:05 | 0.02 | 0.00647768 | 1.799354845e-06 | 4.498387113e-06 | 0 | OFF | 0.0002777776681 | OFF | OFF -> OFF | 1 | 0.2925000001
8:18:06 | 0.02 | 0.00647768 | 1.799355976e-06 | 4.49838994e-06 | 0 | OFF | 0.0002777778427 | OFF | OFF -> OFF | 1 | 0.2925000001
8:18:07 | 0.02 | 0.00647768 | 1.799354845e-06 | 4.498387113e-06 | 0 | OFF | 0.0002777776681 | OFF | OFF -> OFF | 1 | 0.2925000001
8:18:08 | 0.02 | 0.00647768 | 1.799355976e-06 | 4.49838994e-06 | 0 | OFF | 0.0002777778427 | OFF | OFF -> OFF | 1 | 0.2925000001
8:18:09 | 0.02 | 0.00647768 | 1.799355976e-06 | 4.49838994e-06 | 0 | OFF | 0.0002777778427 | OFF | OFF -> OFF | 1 | 0.2925000001
8:18:10 | 0.02 | 0.00647768 | 1.799354845e-06 | 4.498387113e-06 | 0 | OFF | 0.0002777776681 | OFF | OFF -> OFF | 1 | 0.2925000001
8:18:11 | 0.02 | 0.00647768 | 1.799355976e-06 | 4.49838994e-06 | 0 | OFF | 0.0002777778427 | OFF | OFF -> OFF | 1 | 0.2925000001
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

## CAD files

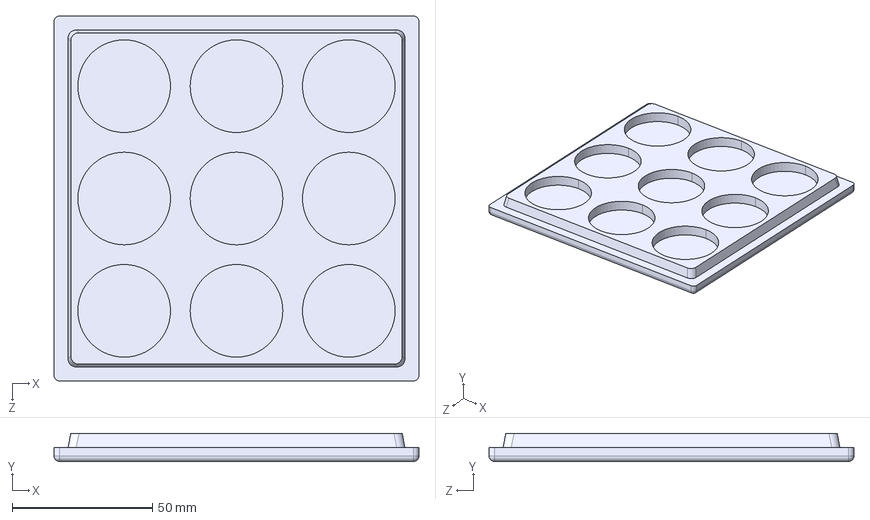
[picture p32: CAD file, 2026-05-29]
3D-Printed-Cell-Parts/Palet_base_3x3.STEP
130.0 x 10.0 x 130.0 mm

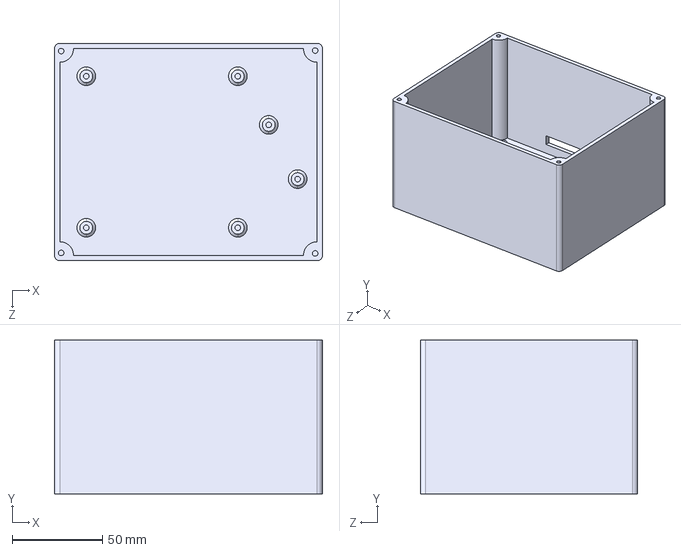
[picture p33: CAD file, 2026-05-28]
RFID-Relay-Interface/RFID_base.STEP
148.2 x 85.0 x 120.3 mm

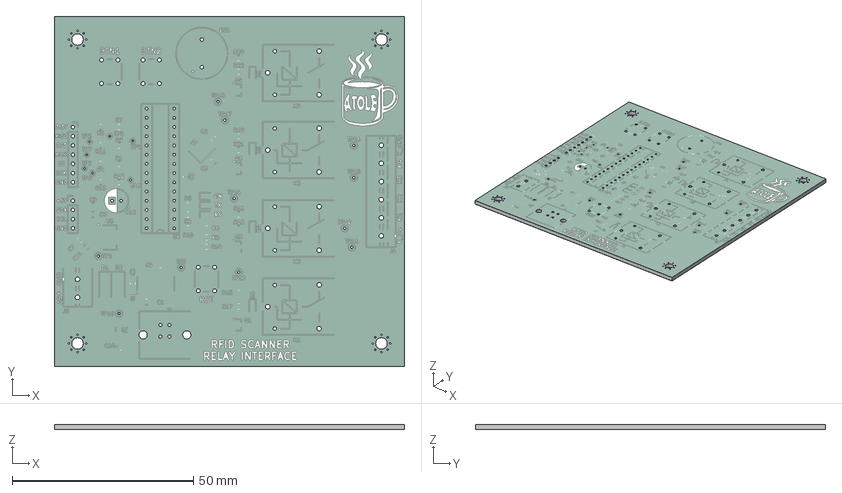
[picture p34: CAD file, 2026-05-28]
RFID-Relay-Interface/rfidRelayInterfacePCB/rfidRelayInterfacePCB.step
96.5 x 96.5 x 1.66 mm
RFIDscanner_silkscreen
RFIDscanner_soldermask
RFIDscanner_PCB

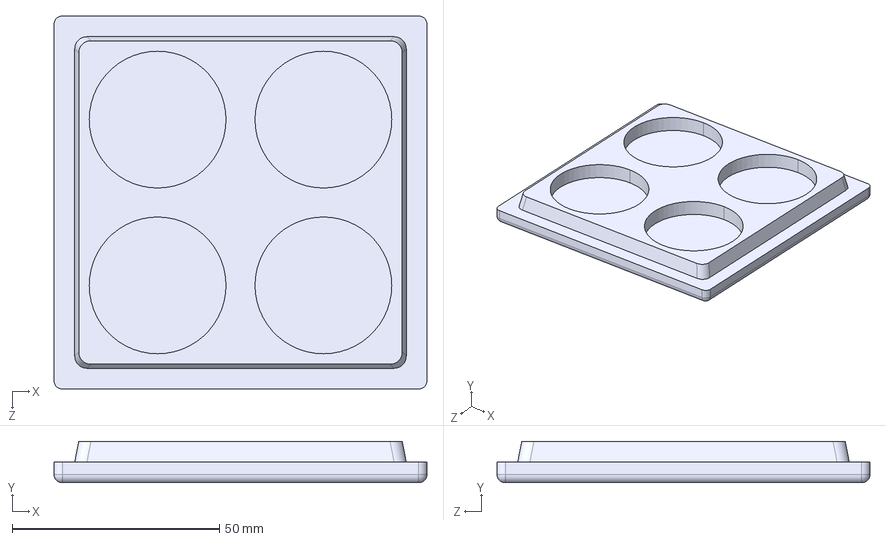
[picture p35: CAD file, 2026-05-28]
3D-Printed-Cell-Parts/Palet_base.STEP
90.0 x 10.0 x 90.0 mm

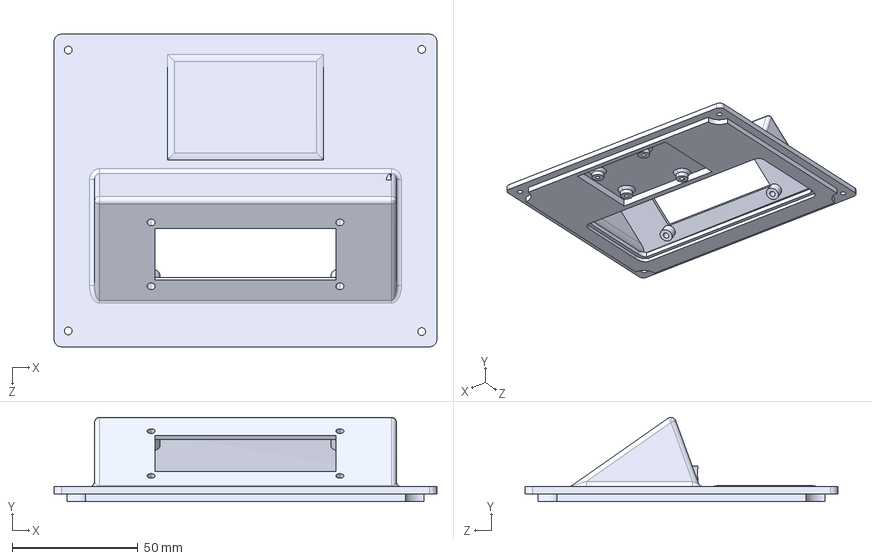
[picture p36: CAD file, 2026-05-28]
RFID-Relay-Interface/RFID_lid.STEP
152.2 x 33.5 x 124.3 mm

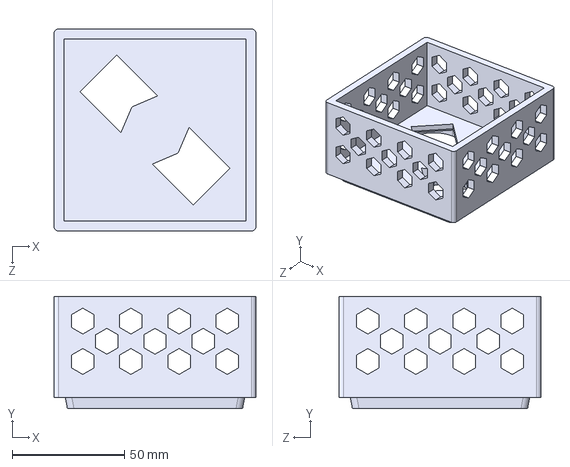
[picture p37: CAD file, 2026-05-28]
3D-Printed-Cell-Parts/Palet_lid.STEP
90.0 x 50.0 x 90.0 mm

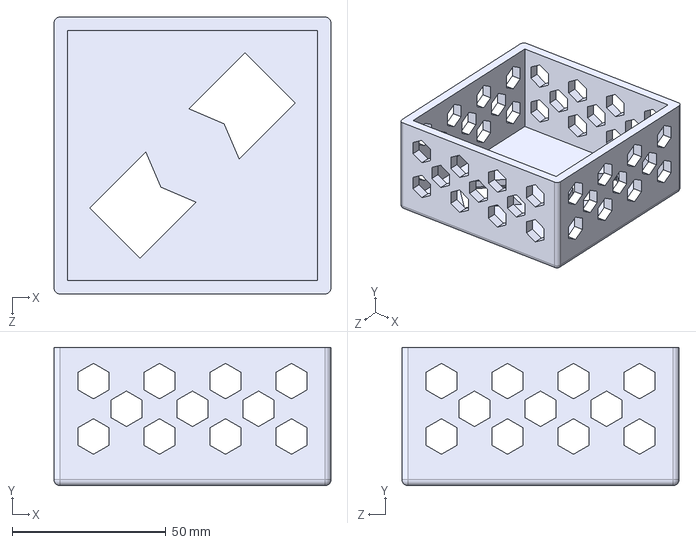
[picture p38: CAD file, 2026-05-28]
3D-Printed-Cell-Parts/Palet_lid2.STEP
90.0 x 45.0 x 90.0 mm

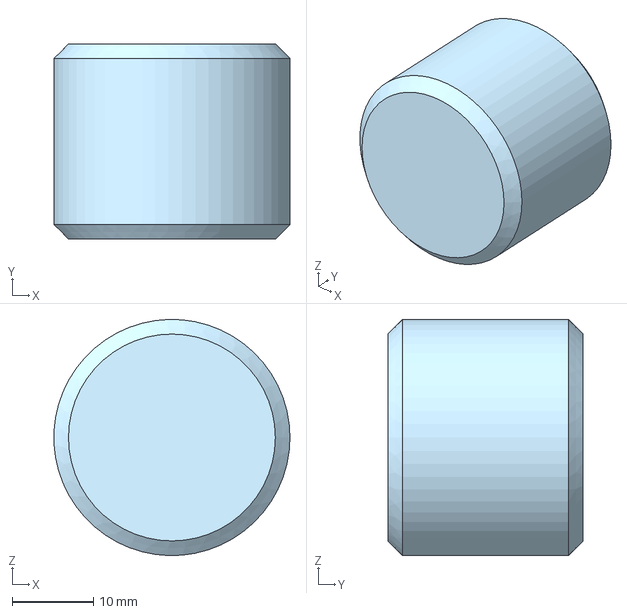
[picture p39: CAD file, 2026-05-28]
3D-Printed-Cell-Parts/cakeBottom.step
29.0 x 24.0 x 29.0 mm

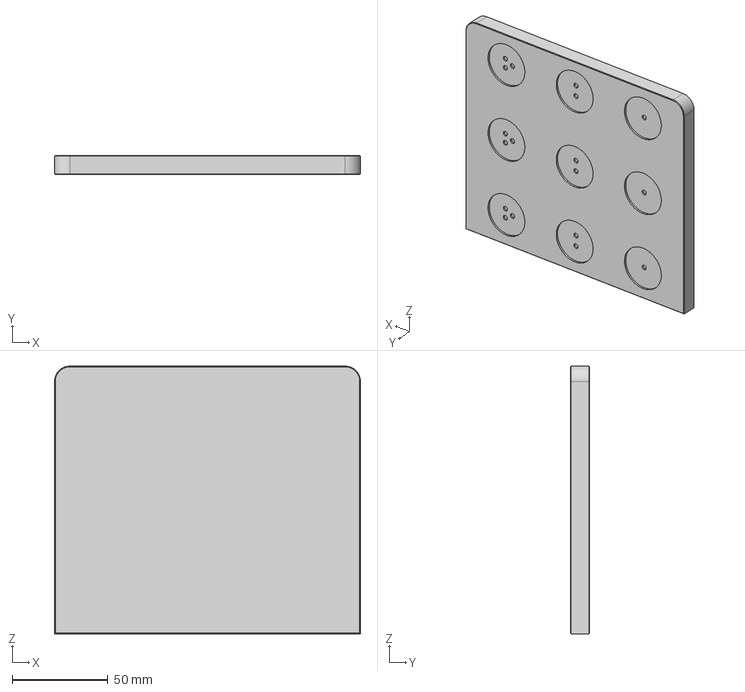
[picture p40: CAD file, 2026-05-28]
3D-Printed-Cell-Parts/trayCakeTop.step
160.0 x 10.0 x 140.0 mm

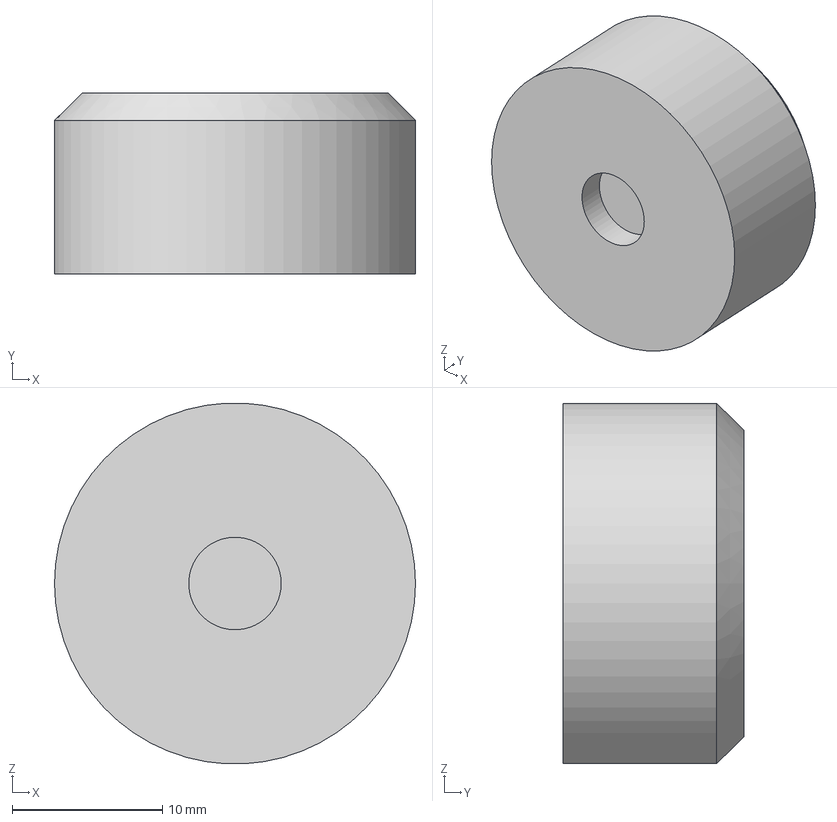
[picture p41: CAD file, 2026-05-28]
3D-Printed-Cell-Parts/cakeTop.step
24.0 x 12.0 x 24.0 mm

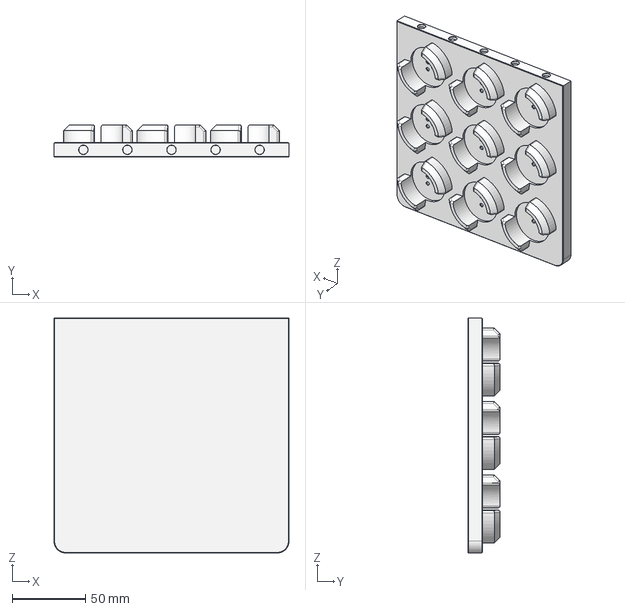
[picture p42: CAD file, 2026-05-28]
3D-Printed-Cell-Parts/trayCakeBottom.step
160.0 x 22.0 x 160.0 mm

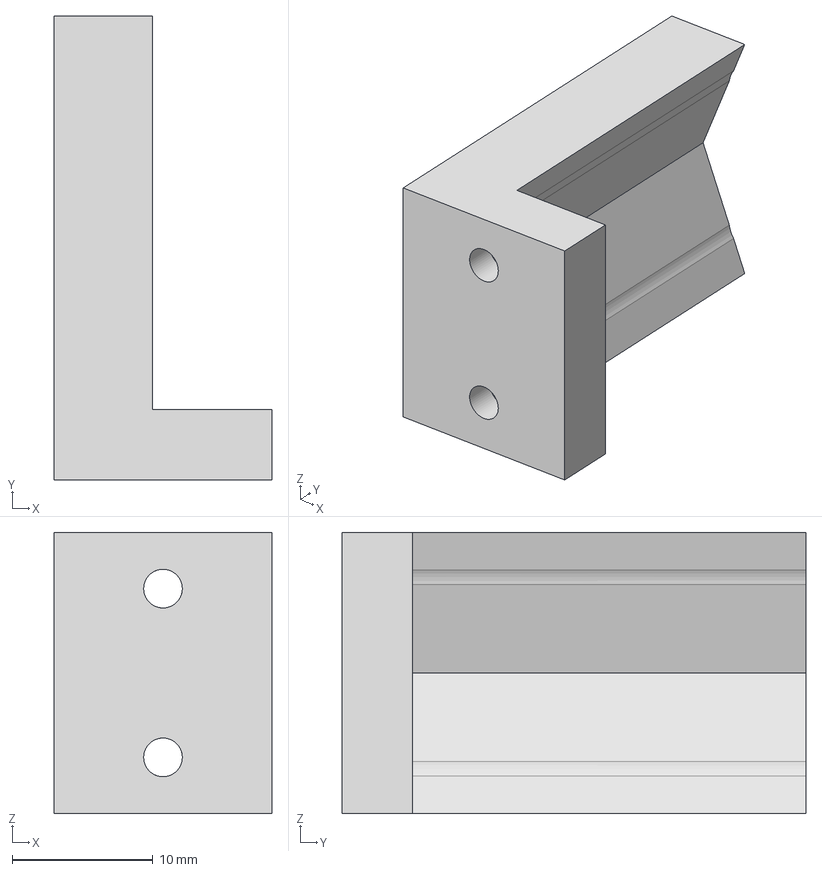
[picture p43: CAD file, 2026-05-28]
3D-Printed-Cell-Parts/cobotGripperFinger.step
15.5 x 33.0 x 20.0 mm

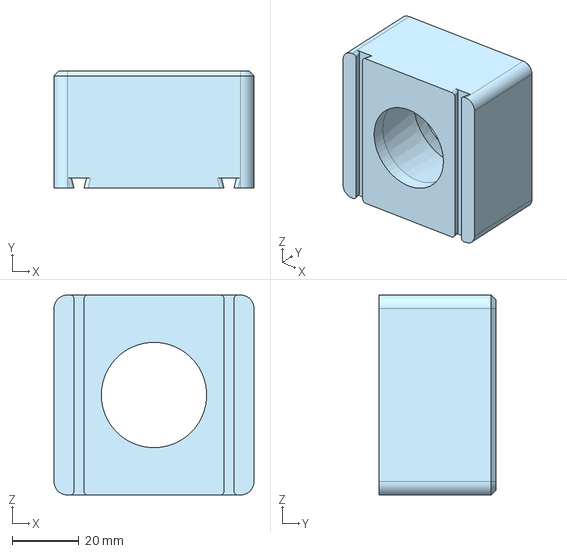
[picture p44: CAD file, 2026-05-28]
3D-Printed-Cell-Parts/cellFunnel.step
60.0 x 35.0 x 60.0 mm

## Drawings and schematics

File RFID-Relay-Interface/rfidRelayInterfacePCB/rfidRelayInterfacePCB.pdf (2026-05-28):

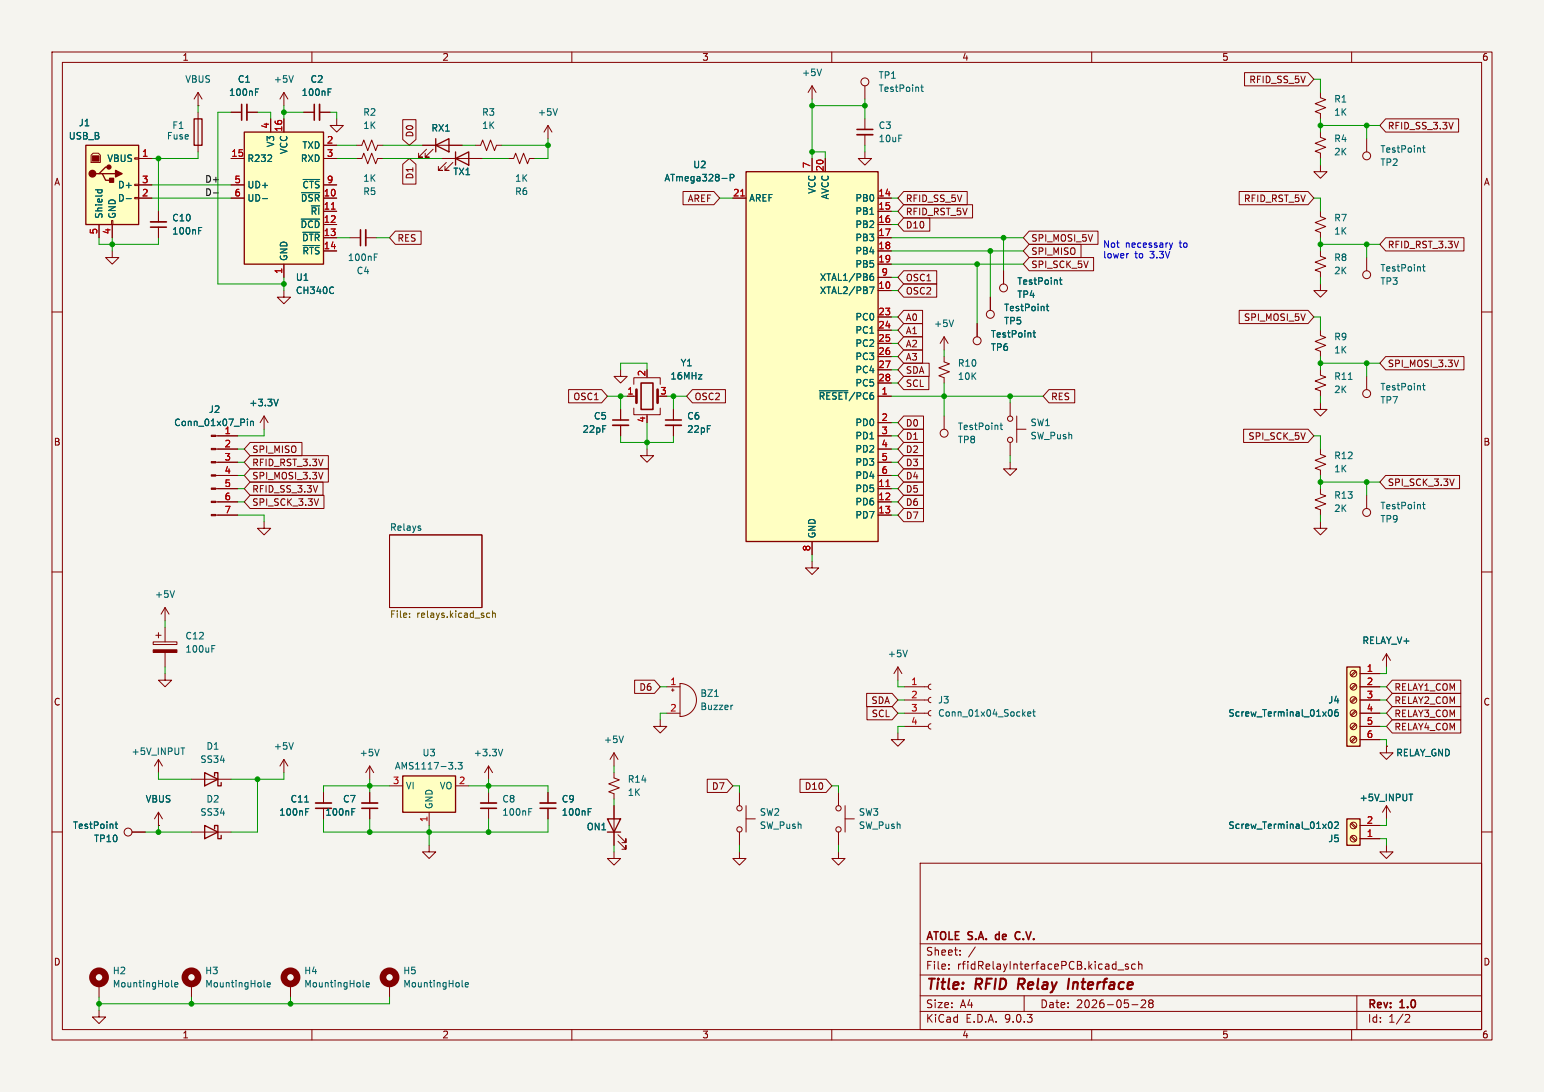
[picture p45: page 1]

1 TXD 2 RXD 3 ~{CTS}9 ~{DSR} 10 ~{RI} 11 ~{DCD} 12 ~{DTR} 13 ~{RTS} 14 U1 CH340C Shield

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

Id: 1/2 Title: RFID Relay Interface

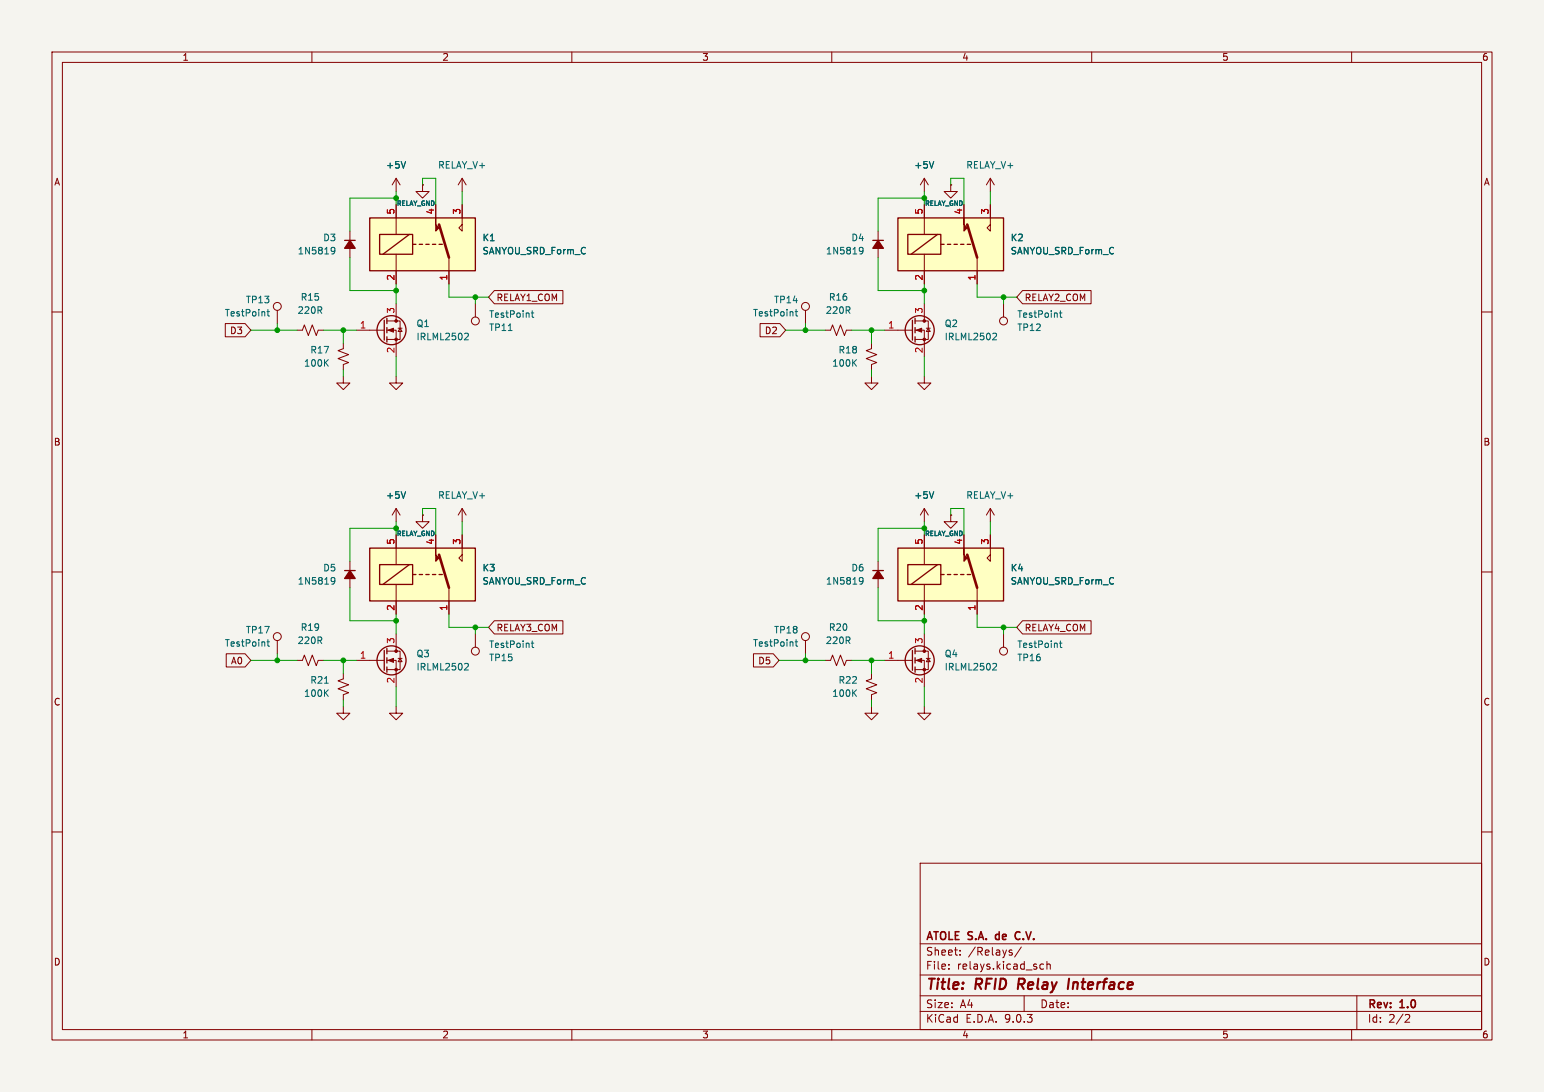
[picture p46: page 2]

Id: 2/2 Title: RFID Relay Interface

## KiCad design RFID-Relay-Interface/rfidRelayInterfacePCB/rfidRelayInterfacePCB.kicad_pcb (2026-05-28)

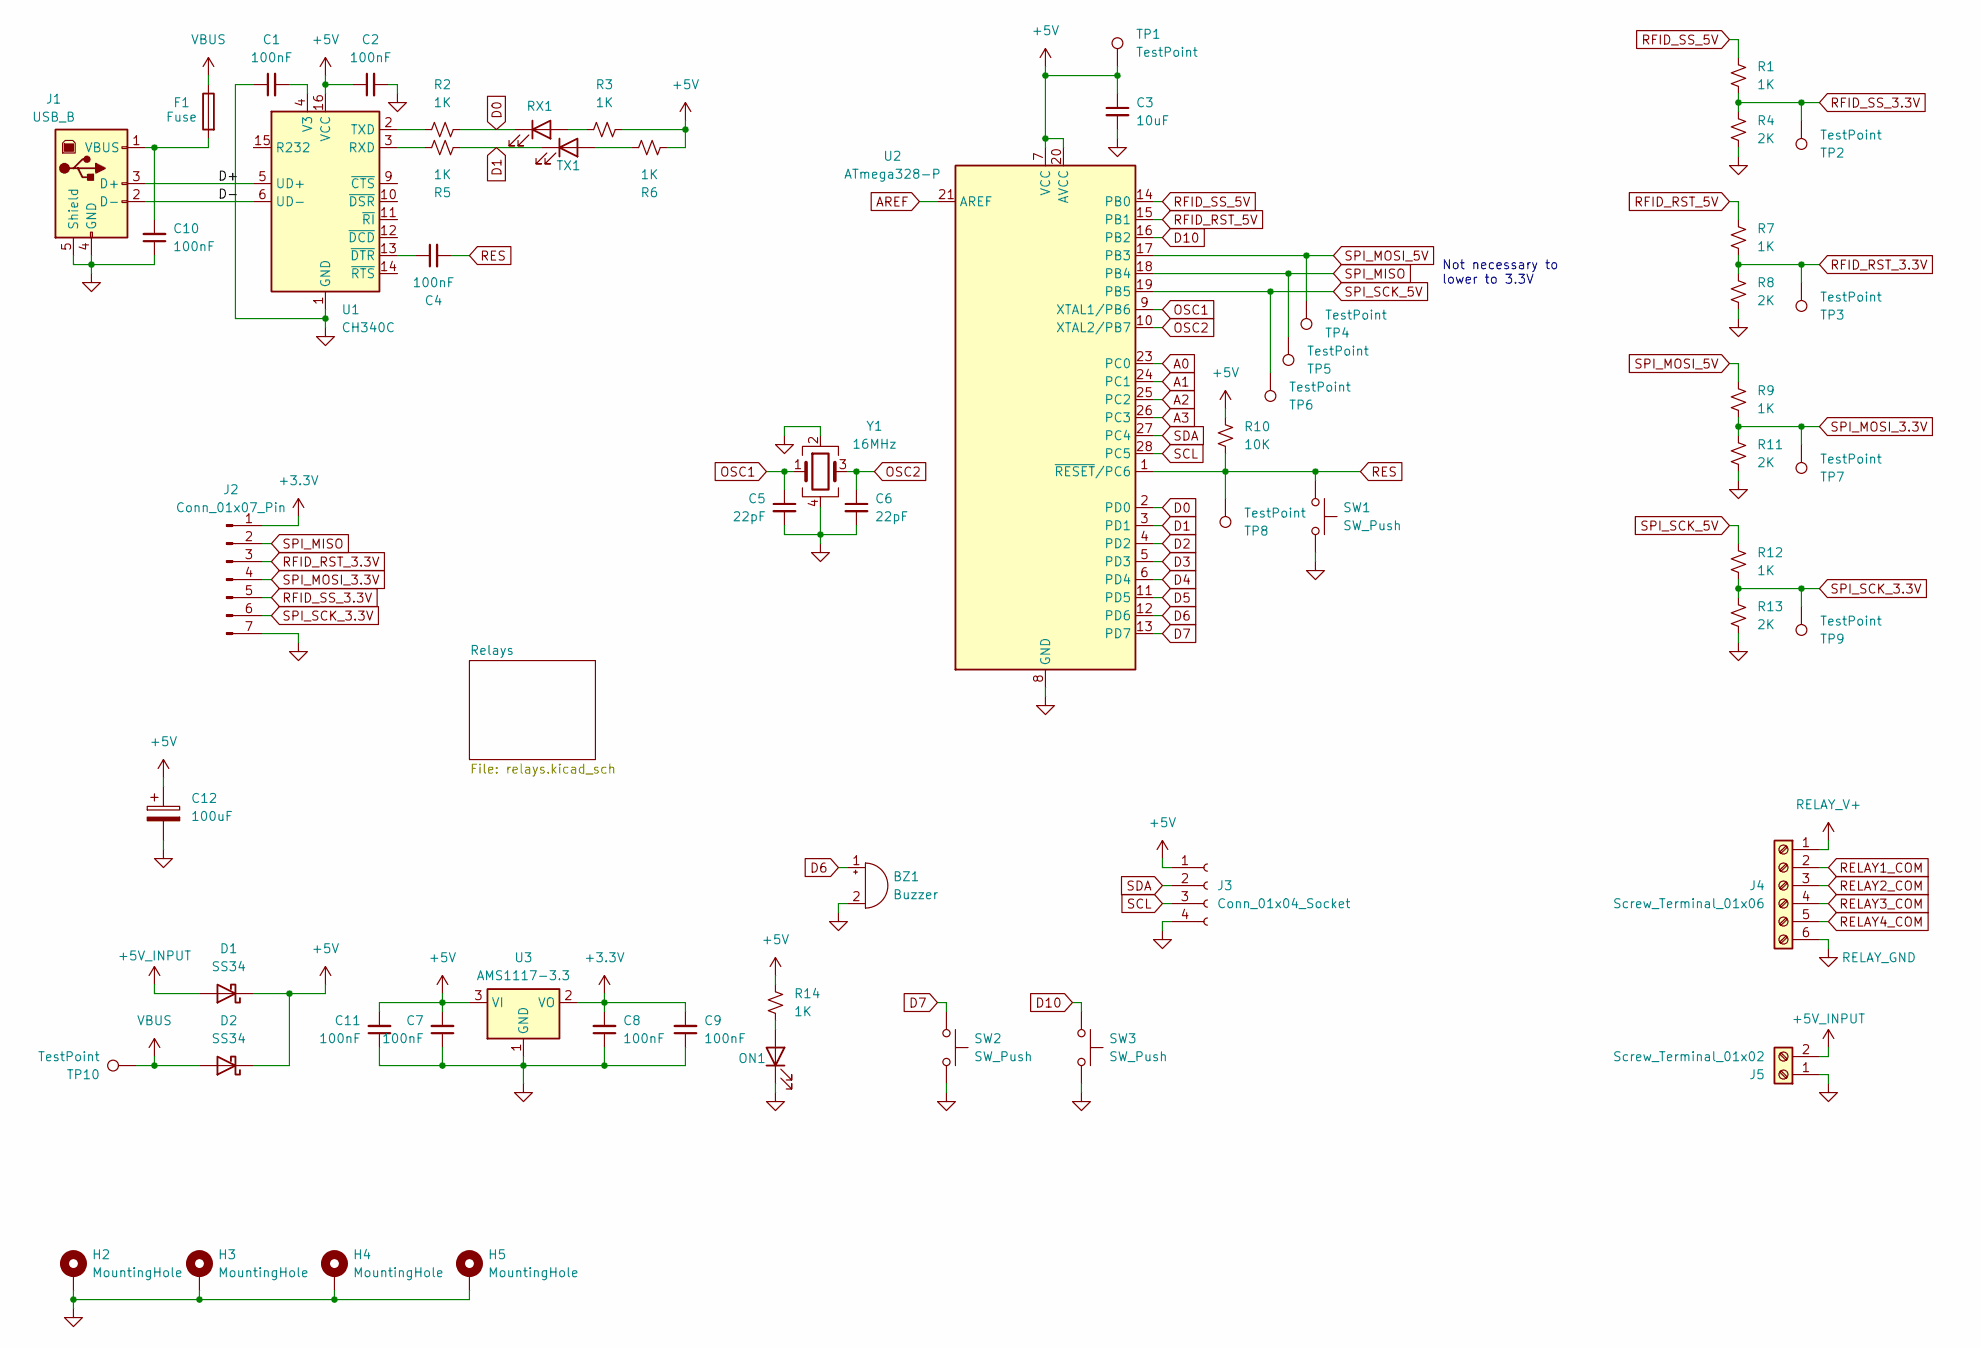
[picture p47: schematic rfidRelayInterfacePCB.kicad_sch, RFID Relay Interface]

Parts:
BZ1: Buzzer; Buzzer_D14mm_H7mm_P10mm
C1, C2, C4, C7, C8, C9, C10, C11: 100nF; C_0805_2012Metric_Pad1.18x1.45mm_HandSolder
C3: 10uF; C_0805_2012Metric_Pad1.18x1.45mm_HandSolder
C5, C6: 22pF; C_0805_2012Metric_Pad1.18x1.45mm_HandSolder
C12: 100uF; CP_Radial_D6.3mm_P2.50mm
D1, D2: SS34; D_SMA_Handsoldering
F1: Fuse; Fuse_1206_3216Metric_Pad1.42x1.75mm_HandSolder
H2, H3, H4, H5: MountingHole; MountingHole_3.2mm_M3_Pad_Via
J1: USB_B; USB_B_TE_5787834_Vertical
J2: Conn_01x07_Pin; PinSocket_1x07_P2.54mm_Vertical
J3: Conn_01x04_Socket; PinHeader_1x04_P2.54mm_Vertical
J4: Screw_Terminal_01x06; TerminalBlock_MaiXu_MX126-5.0-06P_1x06_P5.00mm
J5: Screw_Terminal_01x02; TerminalBlock_MaiXu_MX126-5.0-02P_1x02_P5.00mm
ON1: LED_0805_2012Metric_Pad1.15x1.40mm_HandSolder
R1, R2, R3, R5, R6, R7, R9, R12, R14: 1K; R_0805_2012Metric_Pad1.20x1.40mm_HandSolder
R4, R8, R11, R13: 2K; R_0805_2012Metric_Pad1.20x1.40mm_HandSolder
R10: 10K; R_0805_2012Metric_Pad1.20x1.40mm_HandSolder
RX1: LED_0805_2012Metric_Pad1.15x1.40mm_HandSolder
SW1, SW2, SW3: SW_Push; SW_PUSH_6mm_H5mm
TP1, TP8, TP10: TestPoint; TestPoint_THTPad_D1.5mm_Drill0.7mm
TP2, TP3, TP4, TP5, TP6, TP7, TP9: TestPoint; TestPoint_THTPad_D1.0mm_Drill0.5mm
TX1: LED_0805_2012Metric_Pad1.15x1.40mm_HandSolder
U1: CH340C; SOIC-16_3.9x9.9mm_P1.27mm
U2: ATmega328-P; DIP-28_W7.62mm_Socket_LongPads
U3: AMS1117-3.3; SOT-223-3_TabPin2
Y1: 16MHz; Crystal_SMD_3225-4Pin_3.2x2.5mm_HandSoldering

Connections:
+3.3V: C8.2, C9.2, J2.1, U3.2 (VO)
+5V: C2.1, C3.1, C7.2, C11.2, C12.1, D1.1 (K), D2.1 (K), J3.1, R3.2, R6.1, R10.1, R14.1, TP1.1, U1.16 (VCC), U2.7 (VCC), U2.20 (AVCC), U3.3 (VI); also elsewhere on the board
+5V_INPUT: D1.2 (A), J5.2
/D+: J1.3 (D+), U1.5 (UD+)
/D-: J1.2 (D-), U1.6 (UD-)
A0: U2.23 (PC0); also elsewhere on the board
A1: U2.24 (PC1)
A2: U2.25 (PC2)
A3: U2.26 (PC3)
AREF: U2.21 (AREF)
D0: R2.2, RX1.1 (K), U2.2 (PD0)
D1: R5.1, TX1.1 (K), U2.3 (PD1)
D2: U2.4 (PD2); also elsewhere on the board
D3: U2.5 (PD3); also elsewhere on the board
D4: U2.6 (PD4)
D5: U2.11 (PD5); also elsewhere on the board
D6: BZ1.1 (+), U2.12 (PD6)
D7: SW2.1, U2.13 (PD7)
D10: SW3.1, U2.16 (PB2)
GND: BZ1.2 (-), C1.1, C2.2, C3.2, C5.2, C6.2, C7.1, C8.1, C9.1, C10.1, C11.1, C12.2, H2.1, H3.1, H4.1, H5.1, J1.4 (GND), J1.5 (Shield), J2.7, J3.4, J5.1, ON1.1 (K), R4.2, R8.2, R11.2, R13.2, SW1.2, SW2.2, SW3.2, U1.1 (GND), U2.8 (GND), U2.22 (GND), U3.1 (GND), Y1.2, Y1.4; also elsewhere on the board
unnamed: C10.2, F1.2, J1.1 (VBUS)
unnamed: ON1.2 (A), R14.2
unnamed: R3.1, RX1.2 (A)
unnamed: R6.2, TX1.2 (A)
unnamed: R5.2, U1.3 (RXD)
unnamed: R2.1, U1.2 (TXD)
unnamed: C1.2, U1.4 (V3)
unnamed: C4.1, U1.13 (~DTR)
OSC1: C5.1, U2.9 (XTAL1/PB6), Y1.1
OSC2: C6.1, U2.10 (XTAL2/PB7), Y1.3
RELAY1_COM: J4.2; also elsewhere on the board
RELAY2_COM: J4.3; also elsewhere on the board
RELAY3_COM: J4.4; also elsewhere on the board
RELAY4_COM: J4.5; also elsewhere on the board
RELAY_GND: J4.6; also elsewhere on the board
RELAY_V+: J4.1; also elsewhere on the board
RES: C4.2, R10.2, SW1.1, TP8.1, U2.1 (~RESET/PC6)
RFID_RST_3.3V: J2.3, R7.2, R8.1, TP3.1
RFID_RST_5V: R7.1, U2.15 (PB1)
RFID_SS_3.3V: J2.5, R1.2, R4.1, TP2.1
RFID_SS_5V: R1.1, U2.14 (PB0)
SCL: J3.3, U2.28 (PC5)
SDA: J3.2, U2.27 (PC4)
SPI_MISO: J2.2, TP5.1, U2.18 (PB4)
SPI_MOSI_3.3V: J2.4, R9.2, R11.1, TP7.1
SPI_MOSI_5V: R9.1, TP4.1, U2.17 (PB3)
SPI_SCK_3.3V: J2.6, R12.2, R13.1, TP9.1
SPI_SCK_5V: R12.1, TP6.1, U2.19 (PB5)
VBUS: D2.2 (A), F1.1, TP10.1

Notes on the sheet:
Not necessary to lower to 3.3V

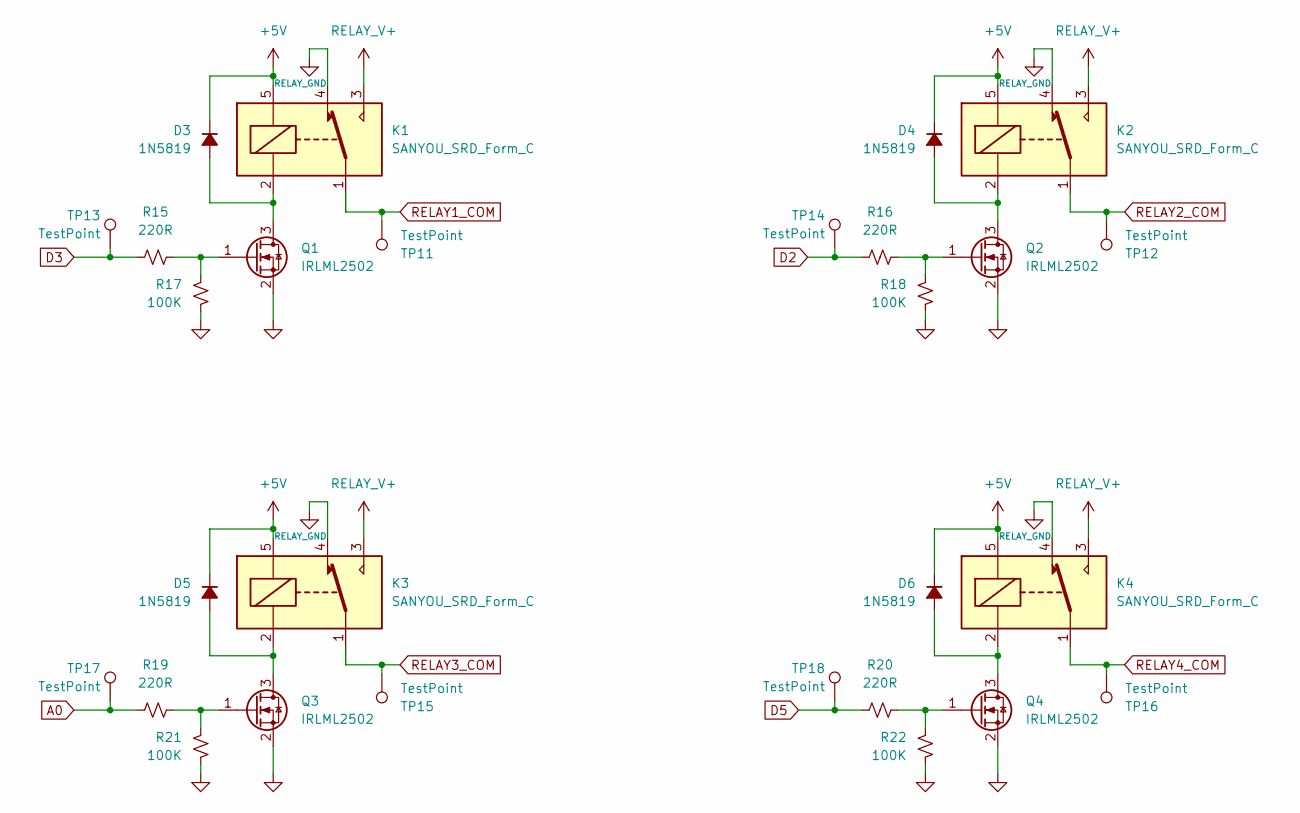
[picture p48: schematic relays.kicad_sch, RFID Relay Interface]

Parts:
D3, D4, D5, D6: 1N5819; D_SOD-323_HandSoldering
K1, K2, K3, K4: SANYOU_SRD_Form_C; Relay_SPDT_SANYOU_SRD_Series_Form_C
Q1, Q2, Q3, Q4: IRLML2502; SOT-23_Handsoldering
R15, R16, R19, R20: 220R; R_0805_2012Metric_Pad1.20x1.40mm_HandSolder
R17, R18, R21, R22: 100K; R_0805_2012Metric_Pad1.20x1.40mm_HandSolder
TP11, TP12, TP13, TP14, TP15, TP16, TP17, TP18: TestPoint; TestPoint_THTPad_D1.5mm_Drill0.7mm

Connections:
+5V: D3.1 (K), D4.1 (K), D5.1 (K), D6.1 (K), K1.5, K2.5, K3.5, K4.5; also elsewhere on the board
A0: R19.1, TP17.1; also elsewhere on the board
D2: R16.1, TP14.1; also elsewhere on the board
D3: R15.1, TP13.1; also elsewhere on the board
D5: R20.1, TP18.1; also elsewhere on the board
GND: Q1.2 (S), Q2.2 (S), Q3.2 (S), Q4.2 (S), R17.2, R18.2, R21.2, R22.2; also elsewhere on the board
unnamed: D3.2 (A), K1.2, Q1.3 (D)
unnamed: D4.2 (A), K2.2, Q2.3 (D)
unnamed: D5.2 (A), K3.2, Q3.3 (D)
unnamed: D6.2 (A), K4.2, Q4.3 (D)
unnamed: Q1.1 (G), R15.2, R17.1
unnamed: Q2.1 (G), R16.2, R18.1
unnamed: Q3.1 (G), R19.2, R21.1
unnamed: Q4.1 (G), R20.2, R22.1
RELAY1_COM: K1.1, TP11.1; also elsewhere on the board
RELAY2_COM: K2.1, TP12.1; also elsewhere on the board
RELAY3_COM: K3.1, TP15.1; also elsewhere on the board
RELAY4_COM: K4.1, TP16.1; also elsewhere on the board
RELAY_GND: K1.4, K2.4, K3.4, K4.4; also elsewhere on the board
RELAY_V+: K1.3, K2.3, K3.3, K4.3; also elsewhere on the board

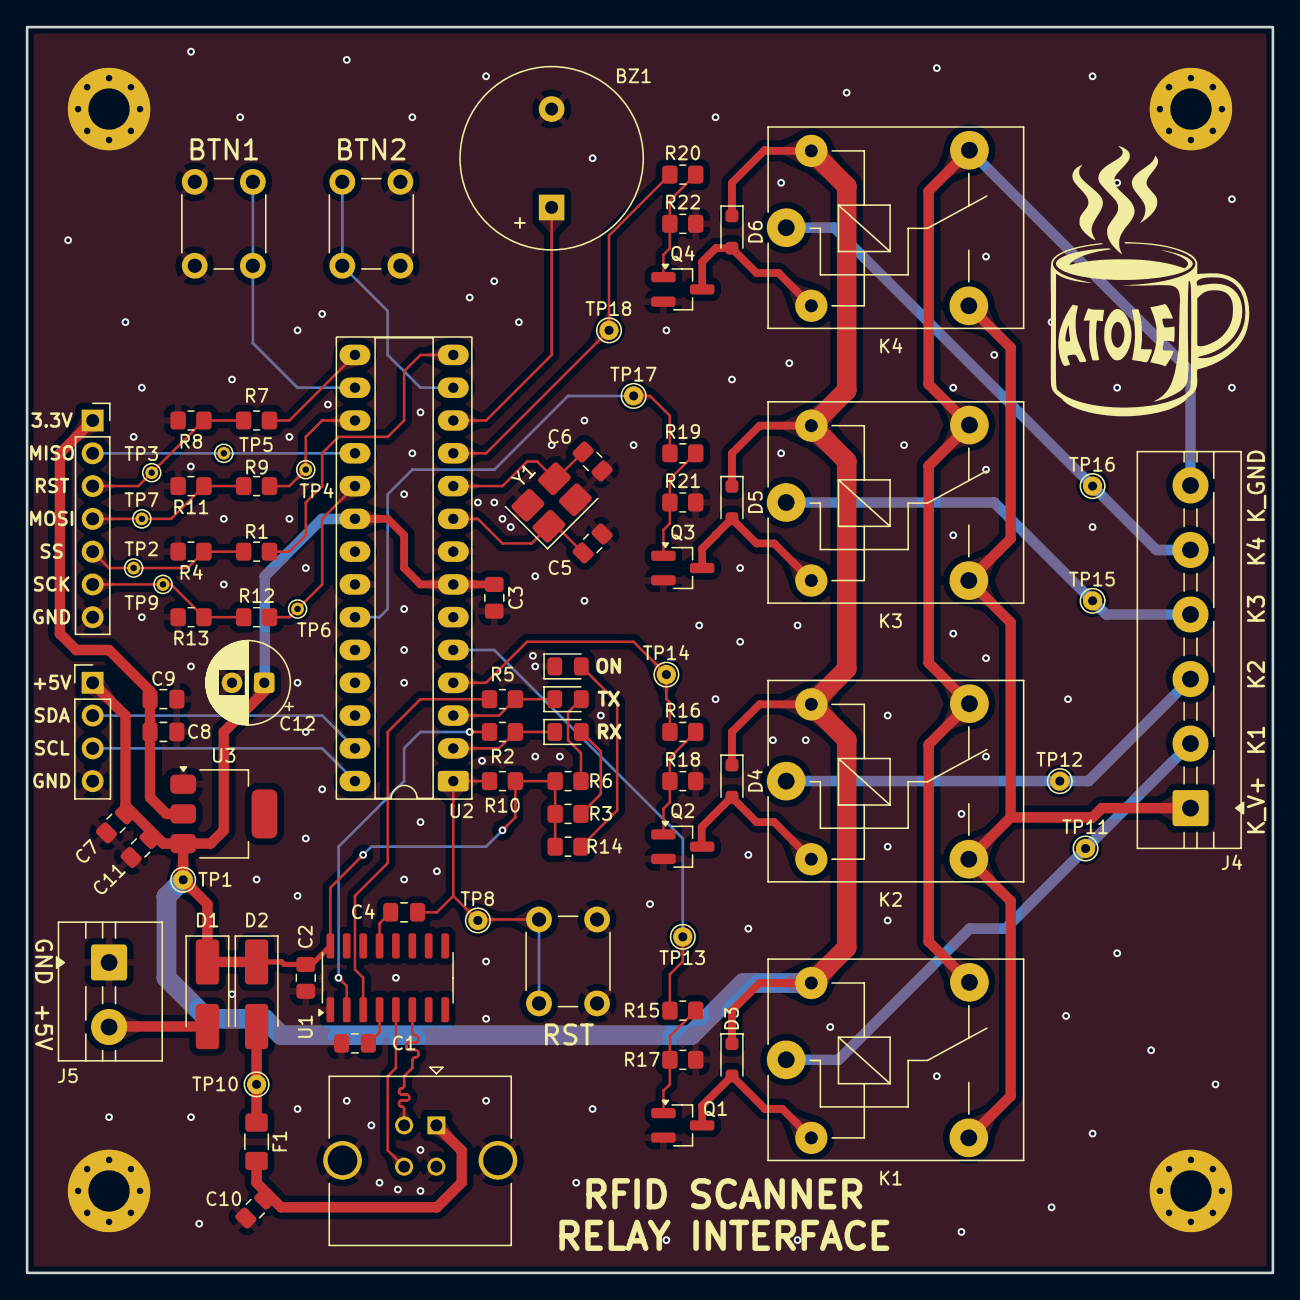
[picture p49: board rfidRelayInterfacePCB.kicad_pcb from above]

Board: 2 copper layers, 96.5 x 96.5 mm, 87 parts (0 on the bottom side), 52 nets.

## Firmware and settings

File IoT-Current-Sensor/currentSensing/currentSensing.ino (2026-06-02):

// AC Current Monitoring System Using SCT-013 and MQTT
// Team: ATOLE

#include <Wire.h>               // I2C communication library
#include <Adafruit_ADS1X15.h>   // ADS1115 libary
#include <WiFi.h>               // WiFi libary
#include <PubSubClient.h>
#include <time.h>


// WIFI AND MQTT CONFIGURATION
const char* ssid =  "Tec-IoT";                        // WiFi network name
const char* password = "spotless.magnetic.bridge";    // WiFi network password
const char* mqtt_server = "10.25.110.236";            // MQTT broker IP address

WiFiClient espClient;                       // WiFi client used by ESP32 for network communication
PubSubClient client(espClient);             // MQTT client that uses the WiFi connection

// ADC CONFIGURATION
Adafruit_ADS1115 ads;                 // Create a ADS1115 object
constexpr float ADS_VREF = 4.096f;    // Maximum ADC reference voltage with GAIN ONE
constexpr float ADS_MAX = 32768.0f;   // Maximum ADC resolution (16 bit ADC)

// SENSOR CONFIGURATION
constexpr float OFFSET_VOLTAGE = 1.64f;     // DC offset voltage for AC waveform centering
constexpr float BURDEN_RESISTOR = 150.0f;   // Burden resistor value
constexpr float SCT013_RATIO = 2000.0f;     // SCT013 current transformer ratio
constexpr float ADC_CALIBRATION = 1.0052f;  // ADC calibration correction factor

// SAMPLING CONFIGURATION
constexpr int SAMPLE_COUNT = 500;     // Number of samples to capture
constexpr int SAMPLE_DELAY_US = 200;  // Delay between samples (us)

// POWER & ENERGY METRICS
constexpr float lineVoltage = 220.0f;      // Voltage between phases
constexpr float powerFactor = 0.85f;       // Estimated power factor
constexpr float electricityRate = 2.5f;    // MXN per kWh
float energykWh = 0.0f;
unsigned long lastTime = 0;

// MACHINE STATES VARIABLES
enum MachineState {
  OFF,
  IDLE,
  CUTTING,
  FAULT
};

MachineState state = OFF;

constexpr float off_threshold = 0.40f;
constexpr float cutting_threshold = 7.3f;
constexpr float max_safe_current = 15.0f;

unsigned long lastStateUpdate = 0;
float off_time_s = 0.0f;
float idle_time_s = 0.0f;
float cutting_time_s = 0.0f;
float fault_time_s = 0.0f;


// WIFI SETUP
void setup_wifi() {
  delay(10);
  
  // Connecting to a WiFi network
  WiFi.begin(ssid, password);
  Serial.print("Connecting to WiFi");

  // Wait until the ESP32 successfully connects to WiFi
  while (WiFi.status() != WL_CONNECTED) {
    delay(500);
    Serial.print(".");
  }
  Serial.println("\nWiFi connected");
}

// MQTT CONNECTION
void reconnect() {
  while (!client.connected()) {
    Serial.print("Attempting MQTT connection...");

    if (client.connect("ESP32_ATOLE")){
      Serial.println("Connected");

    }
    else {
      Serial.print("Failed,rc=");
      Serial.print(client.state());
      Serial.println("Trying again");
      delay(1000);
    }
  }
}

// MACHINE STATE LOGIC
void updateMachineState(float loadCurrent) {
  if (loadCurrent > max_safe_current) {
      state = FAULT;
  }
  else if (loadCurrent < off_threshold) {
      state = OFF;
  }
  else if (loadCurrent >= cutting_threshold) {
      state = CUTTING;
  }
  else {
      state = IDLE;
  }
}

// STATE TIME TRACKING
void updateStateTime() {
  unsigned long now = millis();
  if (lastStateUpdate == 0) {
    lastStateUpdate = now;
    return;
  }
  float delta_s = (now - lastStateUpdate) / 1000.0f;
  lastStateUpdate = now;

  switch (state) {
    case OFF:
      off_time_s += delta_s;
      break;
    case IDLE:
      idle_time_s += delta_s;
      break;
    case CUTTING:
      cutting_time_s += delta_s;
      break;
    case FAULT:
      fault_time_s += delta_s;
      break;
  }
}


// SETUP
void setup() {
  Serial.begin(115200);
  Wire.begin();
  setup_wifi();

  lastTime = millis();

  // WiFi + MQTT
  client.setServer(mqtt_server,1883);

  // ADS115
  if (!ads.begin()) {
    Serial.println("ADS1115 not found");
    while (1)
      ;
  }

  ads.setGain(GAIN_ONE);                  // Configure ADC gain to ±4.096V
  ads.setDataRate(RATE_ADS1115_860SPS);   // Set ADC sampling rate to 860 samples/sec
  delay(1000);                            // Stabilization
  Serial.println("Reading voltage...");
}


// LOOP
void loop() {
  if (!client.connected()) {
    reconnect();
  }
  client.loop();

  int16_t raw;    // Raw ADC reading
  float voltage;  // Calculated voltage

  // Variables to track waveform peaks
  float maxPeak = OFFSET_VOLTAGE;
  float minPeak = OFFSET_VOLTAGE;

  // Collect multiple samples 
  for (int i = 0; i < SAMPLE_COUNT; i++) {
    raw = ads.readADC_SingleEnded(0);       // Read single-ended ADC channel 0
    voltage = (raw * ADS_VREF) / ADS_MAX;   // Convert ADC value to voltage
    voltage *= ADC_CALIBRATION;             // Apply calibration factor

    // Update maximum and minimum peak values
    if (voltage > maxPeak) {
      maxPeak = voltage;
    }
    if (voltage < minPeak) {
      minPeak = voltage;
    }
    delayMicroseconds(SAMPLE_DELAY_US);
  }

  // Current calculation
  float vpp = maxPeak - minPeak;            // Calculate peak to peak voltage
  float vrms = 0.3536f * vpp;               // RMS voltage formula
  float irms = vrms / BURDEN_RESISTOR;      // Converting from RMS voltage to RMS current
  float loadCurrent = irms * SCT013_RATIO;  // Scaling current based on the SCT013's ratio

  // Power calculation
  float power = 1.732f * lineVoltage * loadCurrent * powerFactor;

  // Energy calculation
  unsigned long currentTime = millis();
  float deltaHours = (currentTime-lastTime) / 3600000.0f;
  lastTime = currentTime;
  energykWh += (power/1000.f) * deltaHours;

  // Cost calculation
  float costMXN = energykWh * electricityRate;

  // States functions
  updateMachineState(loadCurrent);
  updateStateTime();

  //Results
  Serial.print("Current: ");
  Serial.print(loadCurrent,4);
  Serial.println(" A");

  Serial.print("Power: ");
  Serial.print(power/1000.0f,4);
  Serial.println(" kW");

  Serial.print("Energy: ");
  Serial.print(energykWh,4);
  Serial.println(" kWh");

  Serial.print("Cost: ");
  Serial.print(costMXN,4);
  Serial.println(" MXN");


  // Publish with MQTT
  char buf[32];

  // Current
  dtostrf(loadCurrent, 6, 2, buf);
  client.publish("current/nr", buf);

  // Power
  dtostrf(power/1000.0f, 6, 2, buf);
  client.publish("power/nr", buf);

  // Energy
  dtostrf(energykWh, 6, 2, buf);
  client.publish("energy/nr", buf);

  // Cost
  dtostrf(costMXN, 8, 2, buf);
  client.publish("cost/nr", buf);

  // State
  client.publish("state/nr", String(state).c_str());

  // Machining states times
  dtostrf(off_time_s, 8, 2, buf);
  client.publish("time/off/nr", buf);

  dtostrf(idle_time_s, 8, 2, buf);
  client.publish("time/idle/nr", buf);

  dtostrf(cutting_time_s, 8, 2, buf);
  client.publish("time/cutting/nr", buf);

  dtostrf(fault_time_s, 8, 2, buf);
  client.publish("time/fault/nr", buf);

  delay(500);
}

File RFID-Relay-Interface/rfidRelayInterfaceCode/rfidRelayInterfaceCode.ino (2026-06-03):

#include <SPI.h>
#include <MFRC522.h>
#include <Wire.h>
#include <LiquidCrystal_I2C.h>

// ── LCD I2C ─────────────────────────────────
LiquidCrystal_I2C lcd(0x27, 16, 2);

// ── Pines RC522 ─────────────────────────────
#define SS_PIN 8
#define RST_PIN 9

MFRC522 rfid(SS_PIN, RST_PIN);

// ── Relés ───────────────────────────────────
#define K1 3
#define K2 2
#define K3 A0
#define K4 5

// ── Usuarios registrados ────────────────────
struct Usuario {
  String uid;
  String nombre;
};

Usuario usuarios[] = {
  { "7F36B80C", "Sebastian Leon" },
  { "CC02C9DB", "Kintia Negrete" },
  { "BDFD8E6E", "Jesus Zamora" },
  { "1A9A8CBE", "Francisco Hdez." },
  { "3AE092BE", "Yudy Perez" }
};

const int numUsuarios = sizeof(usuarios) / sizeof(usuarios[0]);

// ── Anti rebote ─────────────────────────────
String ultimoUID = "";
unsigned long ultimoTiempo = 0;
const unsigned long cooldown = 2000;

// ────────────────────────────────────────────
String uidToString(MFRC522::Uid *uid) {

  String resultado = "";

  for (byte i = 0; i < uid->size; i++) {

    if (uid->uidByte[i] < 0x10) {
      resultado += "0";
    }

    resultado += String(uid->uidByte[i], HEX);
  }

  resultado.toUpperCase();

  return resultado;
}

// ────────────────────────────────────────────
void mostrarInicio() {

  lcd.clear();

  lcd.setCursor(5, 0);
  lcd.print("ATOLE");

  lcd.setCursor(2, 1);
  lcd.print("S.A. de C.V.");
}

// ────────────────────────────────────────────
void setRelays(byte valor) {

  digitalWrite(K1, bitRead(valor, 0));  // LSB
  digitalWrite(K2, bitRead(valor, 1));
  digitalWrite(K3, bitRead(valor, 2));
  digitalWrite(K4, bitRead(valor, 3));  // MSB
}

// ────────────────────────────────────────────
byte obtenerNibble(String uid) {

  if (uid == "7F36B80C") return 0b0001;  // Sebastian
  if (uid == "CC02C9DB") return 0b0010;  // Kintia
  if (uid == "BDFD8E6E") return 0b0011;  // Jesus
  if (uid == "1A9A8CBE") return 0b0100;  // Francisco
  if (uid == "3AE092BE") return 0b0101;  // Yudy

  return 0b0000;  // inválido
}

// ────────────────────────────────────────────
void setup() {

  Serial.begin(9600);

  // ── Configuración relés ──────────────────
  pinMode(K1, OUTPUT);
  pinMode(K2, OUTPUT);
  pinMode(K3, OUTPUT);
  pinMode(K4, OUTPUT);

  // Estado inicial = 0000
  setRelays(0b0000);

  // ── LCD ──────────────────────────────────
  lcd.init();
  lcd.backlight();

  mostrarInicio();

  // ── RFID ─────────────────────────────────
  SPI.begin();
  rfid.PCD_Init();

  Serial.println("RFID system ready...");
}

// ────────────────────────────────────────────
void loop() {

  // Esperar tarjeta
  if (!rfid.PICC_IsNewCardPresent()) {
    return;
  }

  if (!rfid.PICC_ReadCardSerial()) {
    return;
  }

  String uidLeido = uidToString(&rfid.uid);

  // Anti rebote
  if (uidLeido == ultimoUID && millis() - ultimoTiempo < cooldown) {

    rfid.PICC_HaltA();
    return;
  }

  ultimoUID = uidLeido;
  ultimoTiempo = millis();

  Serial.print("UID detectado: ");
  Serial.println(uidLeido);

  // Buscar usuario
  bool encontrado = false;

  for (int i = 0; i < numUsuarios; i++) {

    if (uidLeido == usuarios[i].uid) {

      Serial.print("Bienvenido: ");
      Serial.println(usuarios[i].nombre);

      // ── Activar relés ────────────────────
      byte nibble = obtenerNibble(uidLeido);
      setRelays(nibble);

      // ── Mostrar usuario en LCD ───────────
      lcd.clear();

      lcd.setCursor(0, 0);
      lcd.print("User:");

      lcd.setCursor(0, 1);
      lcd.print(usuarios[i].nombre);

      encontrado = true;

      // Mantener 4 segundos
      delay(4000);

      // Regresar relés a 0000
      setRelays(0b0000);

      // Regresar pantalla inicial
      mostrarInicio();

      break;
    }
  }

  // ── Usuario inválido ─────────────────────
  if (!encontrado) {

    Serial.println("INVALID USER");

    // Relés = 0000
    setRelays(0b0000);

    lcd.clear();

    lcd.setCursor(5, 0);
    lcd.print("ACCESS");

    lcd.setCursor(5, 1);
    lcd.print("DENIED");

    // Esperar 4 segundos
    delay(4000);

    // Regresar pantalla inicial
    mostrarInicio();
  }

  Serial.println();

  rfid.PICC_HaltA();
}

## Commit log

2026-05-19 First upload of the Plant Simulation for the production line.
    It contains the first milling station.
2026-05-20 Add file with just current sensing from instrumentation
2026-05-20 Add a sketch of the electronic schematic used in the instrumentation
2026-05-20 Fixed current sensing
2026-05-21 tweaked pneumatic hmi
2026-05-21 Moved the PLC files to another folder, added tag tables
    [PLC1_Tags.xlsx, PLC2_Tags.xlsx]
2026-05-21 Current sensor code with comments
2026-05-21 Current sensor code that publishes data via MQTT
2026-05-22 al chile demasiadas cosas ya ni sé que
    si
2026-05-22 Added all conveyor and worstation logic up to polishing station
2026-05-25 Added power consumption, basic cobot comm
2026-05-25 Started Working on an Assembly Method
2026-05-25 Created an Assembly station with 3 different Assemblies based on Main_Mu
2026-05-28 finished code for rfid relay interface
2026-05-28 add .step files of 3d printed files used in didactic cell
    [cakeBottom.step, cakeTop.step, cellFunnel.step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]
2026-05-28 Corrected Assembly Stations according to professor
2026-05-28 Added pcb files
    [relays.kicad_sch, rfidRelayInterfacePCB.csv, rfidRelayInterfacePCB.kicad_pcb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]
2026-05-28 RFID case 3D models
    [RFID_base_2.0.STL, RFID_tip_2.0.STL]
2026-05-28 Palletizing 3D models .step
    [Palet_base.STL, Palet_lid2_3.0.STL, Palet_lid_3.0.STL]
2026-05-28 Added files for RFID case in .STEP
    [RFID_base.STEP, RFID_lid.STEP]
2026-05-28 Added files for palletizing mold in .STEP
    [Palet_base.STEP, Palet_lid.STEP, Palet_lid2.STEP]
2026-05-29 Added palet base 3x3 in .STEP
    [Palet_base_3x3.STEP]
2026-06-01 added power consumption in MXN
2026-06-01 Update currentSensing.ino
    Current (A), Power (kW), Energy (kWh) and Cost ($ MXN)
2026-06-02 update tag excel tables
    [MachiningPLC_Tags.xlsx, PLC1_Tags.xlsx, PLC2_Tags.xlsx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]
2026-06-03 Manufactured piece data & insights
    ROMI T-240 (CIMA)
    June 2nd, 2026
    [ROMI_Piece_0601_dataAnalysis.xlsx]
2026-06-03 Add Kintia's uuid and shorten Fran's name
    [rfidRelayInterfaceCode.ino]
2026-06-04 Update ATOLE_cobot.py
    Palletizing error pending
    [ATOLE_cobot.py]
2026-06-05 Update ATOLE_cobot.py
    Adapted Comments in english and deleted waypoint after lid assembly
2026-06-05 Update ATOLE_cobot.py
    Added measurements to prevent SDK not responding
    [ATOLE_cobot.py]
2026-06-05 Update ATOLE_cobot.py
    Corrected Bits sent to cobot after palletizing logic
    [ATOLE_cobot.py]
2026-06-05 Update ATOLE_cobot.py
    Adjusted Velocities - WORKING FOR VIDEO
2026-06-08 Update ATOLE_cobot.py
    Added gripper off
2026-06-10 Update gripperON-OFF_WIP.py
    We tried to implement a method to deactivate the gripper at points where it is not actively being used to grasp or transport parts.
2026-06-10 pcb pic
2026-06-10 Improve image display for RFID PCB
    Updated image formatting for RFID PCB in README.
